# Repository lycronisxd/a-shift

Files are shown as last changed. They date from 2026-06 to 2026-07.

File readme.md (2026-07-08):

# a-shift
## a high-quality sim racing shifter targeted at being as cheap as possible to manufacture.

\
shifter


### pcb and schematic




### bill of materials

 Item No. | Part No. | Part Name | Qty. | Supplier | Unit Cost | Total Cost |
|---|---|---|---|---|---|---|
| 1 | 3D-001 | 3d printed y-axis chamber | 1 | 3d printing service / at home printing | N/A | N/A |
| 2 | 3D-002 | 3d printed x-axis bearing peg | 2 | 3d printing service / at home printing | N/A | N/A |
| 3 | 3D-003 | 3d printed y-axis bearing peg | 1 | 3d printing service / at home printing | N/A | N/A |
| 4 | 3D-004 | 3d printed main chassis | 1 | 3d printing service / at home printing | N/A | N/A |
| 5 | 3D-005 | 3d printed shift gate | 1 | 3d printing service / at home printing | N/A | N/A |
| 6 | 3D-006 | 3d printed y-axis bearing holder | 1 | 3d printing service / at home printing | N/A | N/A |
| 7 | 3D-007 | 3d printed shift knob | 1 | 3d printing service / at home printing | N/A | N/A |
| 8 | 3D-008 | 3d printed clamp head | 1 | 3d printing service / at home printing | N/A | N/A |
| 9 | 3D-009 | 3d printed clamp body | 1 | 3d printing service / at home printing | N/A | N/A |
| 10 | BR-001 | 608 series bearing | 4 | aliexpress | £0.44 | £4.35 (10pcs) |
| 11 | BR-002 | 625 series bearing | 2 | aliexpress | £0.37 | £3.68 (10pcs) |
| 12 | MNT-001 | m3x5mm bolt | 4 | accu | £0.27 | £1.08 |
| 13 | MNT-002 | m4 nut | 8 | accu | £0.18 | £1.44 |
| 14 | MNT-003 | m6 washers | 8 | accu | £0.19 | £1.52 |
| 15 | MNT-004 | m4x10mm bolt | 15 | accu | £0.15 | £2.25 |
| 16 | MNT-005 | m5 nut | 2 | accu | £0.43 | £0.86 |
| 17 | MNT-006 | m5x10mm bolt | 2 | accu | £0.49 | £0.98 |
| 18 | MNT-007 | m10 washer | 1 | accu | £0.82 | £0.82 |
| 19 | MNT-008 | m10 nut | 1 | accu | £1.01 | £1.01 |
| 20 | SPR-001 | 25mm long, 5mm diameter springs | 2 | aliexpress | £0.29 | £2.89 (10pcs) |
| 21 | SPR-002 | 45mm long, 5mm diameter springs | 2 | aliexpress | £0.37 | £3.73 (10pcs) |
| 22 | SPR-003 | 20mm long, 11mm diameter spring | 1 | aliexpress | £0.26 | £2.59 (10pcs) |
| 23 | MSC-001 | 200mm m10 threaded rod | 1 | aliexpress | £4.31 | £4.31 |
| 24 | MSC-002 | kw13-2 limit switches | 8 | aliexpress | £0.16 | £1.63 |
| 25 | PCB-001 | a-shift pcb (if assembled, ignore the following parts) | 1 | jlcpcb with gerber files | £4 | £4 |
| 26 | PCB-002 | CL21B105KBFNNNG 1uF capacitor | 1 | digikey | £0.09 | £0.09 |
| 27 | PCB-003 | CL21C220JBANNNC 22pF capacitor | 2 | digikey | £0.08 | £0.16 |
| 28 | PCB-004 | CL21B104KBCNNNC 0.1uF capacitor | 4 | digikey | £0.08 | £0.32 |
| 29 | PCB-005 | 1050170001 micro usb connector | 1 | digikey | £0.70 | £0.70 |
| 30 | PCB-006 | RC0805FR-0710KL 10k ohm resistor | 1 | digikey | £0.08 | £0.08 |
| 31 | PCB-007 | RC0805FR-0722RL 22 ohm resistor | 2 | digikey | £0.08 | £0.16 |
| 32 | PCB-008 | 1825910-6 tactile switch | 1 | digikey | £0.10 | £0.10 |
| 33 | PCB-009 | ATMEGA32U4-AU microcontroller | 1 | digikey | £4.01 | £4.01 |
| 34 | PCB-010 | ABM3-16.000MHZ-D2Y-T 16mhz crystal oscillator | 1 | digikey | £0.42 | £0.42 |\

total price (excl. 3d printing services, shipping and tax), <b>£43.18 (~60 USD)</b>

### relevant links
link to **public onshape project**:
<a href="https://cad.onshape.com/documents/ae479125a780254f271543a6/w/35b4ca05e55e778462ce5fb0/e/28c8145b059bf4585cd308b0"> click this </a>

link to **3d printed parts**:
<a href="https://www.thingiverse.com/thing:7376293">click here!</a>

### features
<ul>
<li>custom designed pcb based on the atmega32u4 for ease of future designing :)</li>
<li>7+R normally</li>
<li>5+R capability</li>
<li>sequential shifter capability</li>
<li>built in clamping system for tables or sim rigs</li>
</ul>

### how it works
<ul>
<li>uses a combination of software and hardware to be used as a shifter in racing or driving games</li>
<li>the used limit switches are mapped as controller buttons inside of game settings</li>
<li>can use the shifter sequentially if printing the sequential shift gate and using rubber bands!</li>
</ul>



### instructions
<a href="https://github.com/lycronisxd/a-shift/blob/main/instructions.md">click here!</a>

### credits + ai declaration
<a href="https://www.youtube.com/@amstudioprojects">amstudio</a> for <a href="https://www.youtube.com/watch?v=YMD8e26s7VE&t=88s">this video</a>\
about <a href="https://www.thingiverse.com/Noctiluxx/designs">noctiluxx's <a href="https://www.thingiverse.com/thing:1274947">h-pattern shifter design</a> for the forwards and backwards action of the shifter being locked <3 

i used google gemini to understand why the length of the shift lever mattered\
i used chatgpt to confirm the selection of the electronic components that i plan to use for the pcb (capacitors, resistors etc.)

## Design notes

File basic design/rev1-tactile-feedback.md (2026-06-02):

---

excalidraw-plugin: parsed
tags: [excalidraw]

---
==⚠  Switch to EXCALIDRAW VIEW in the MORE OPTIONS menu of this document. ⚠== You can decompress Drawing data with the command palette: 'Decompress current Excalidraw file'. For more info check in plugin settings under 'Saving'

# Excalidraw Data

## Text Elements
## Embedded Files
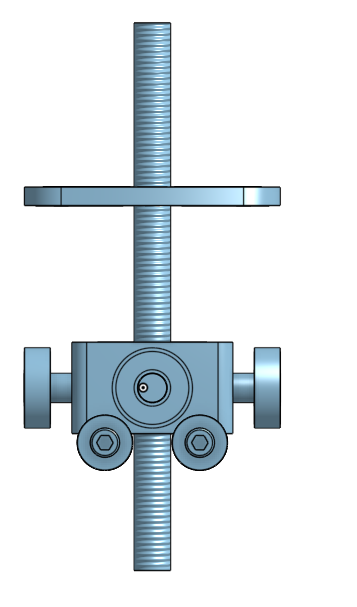
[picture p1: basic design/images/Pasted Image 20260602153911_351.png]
234c616a46d7c50920a0060077a56fa564ae83e9: 

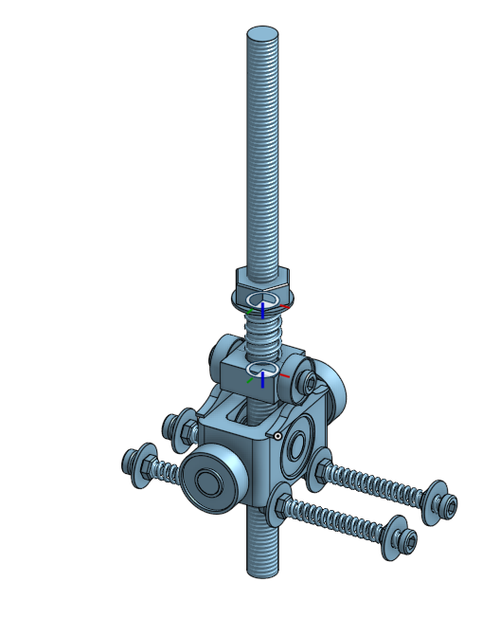
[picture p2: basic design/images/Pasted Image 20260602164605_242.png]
6d9b194bfda16ef9e24804b23e8041610898d77b: 

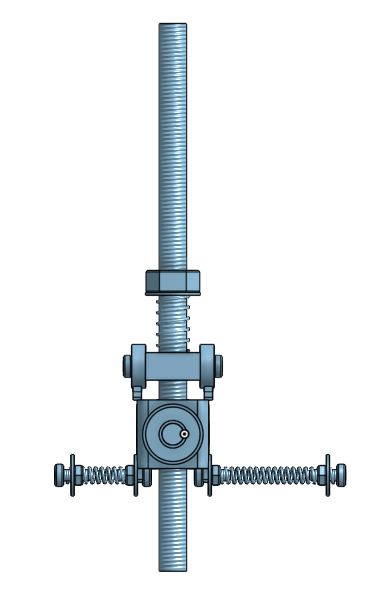
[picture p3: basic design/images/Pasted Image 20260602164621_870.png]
5b474f4c6cc8ce74e5476178851a1a231249c66e: 

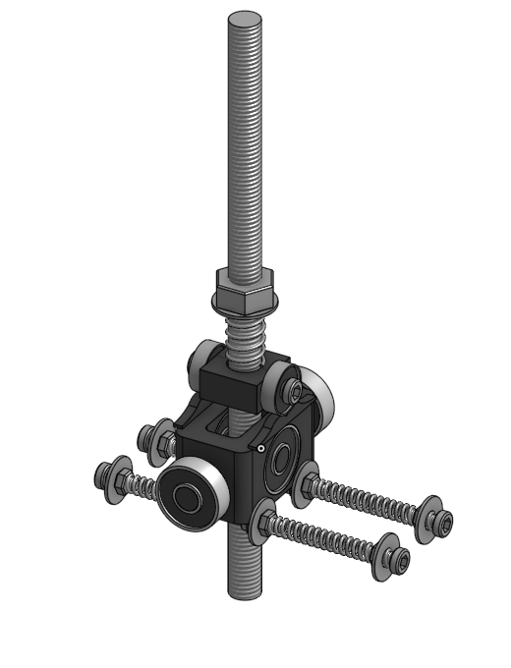
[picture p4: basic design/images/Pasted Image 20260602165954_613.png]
e46b88f7a6ff542bc56e074cb9cd92b4bdc86a87: 

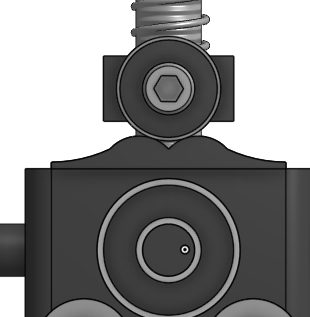
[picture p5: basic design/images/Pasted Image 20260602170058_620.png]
d8bf0ac76847611c596c5c8c6d7cbc8b6c326d83: 

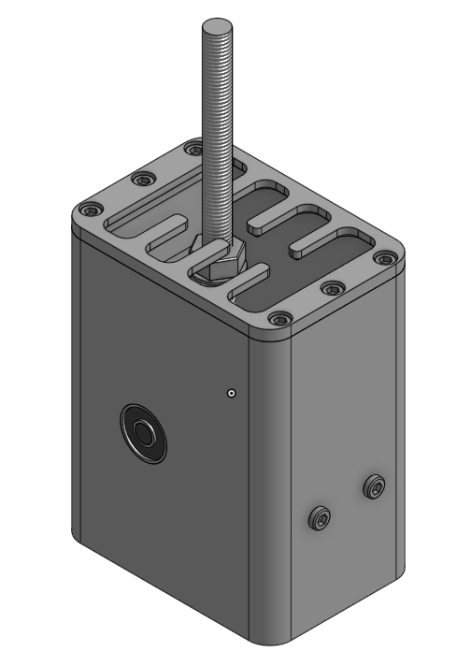
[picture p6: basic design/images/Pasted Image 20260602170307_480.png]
ec3541a6d95118efb10d60b192f7a991a92ff538: 

%%
## Drawing
```compressed-json
N4KAkARALgngDgUwgLgAQQQDwMYEMA2AlgCYBOuA7hADTgQBuCpAzoQPYB2KqATLZMzYBXUtiRoIACyhQ4zZAHoFAc0JRJQgEYA6bGwC2CgF7N6hbEcK4OCtptbErHALRY8RMpWdx8Q1TdIEfARcZgRmBShcZR5tHgBmbQAOGjoghH0EDihmbgBtcDBQMBKIEm4IAGFlWUqAMwA2JH5S2EQKwn1o5sLITG5neJ4ATm14+IaAVnGAFgBGJIaZniT4

lsgYAZ4Adknt7Unp7cWZ7ZnJ4eH1iAoSdW45gAZJme1hl+3Lp+25mfi566SBCEZTSB6fRI/RZLR4rObwta9CDWZTBbiPa7MKCkNgAawQlTY+DYpAq2OszDguEC2VSJUgmlw2FxyhxQg4xEJxNJEnJHEp1KyUDppTqhHw+AAyrA0RJBB4RQJsXiEAB1O6Sbh8JFYnH46UwWXoeXla5s0EccK5NAApFsKnYNSbG2PDFI1nCOAASWI1tQeQAutc6uRM

j7uBwhBLroQOVgKrhHoqIGyOZbmH7I9GdQgEMRuElHsMkpMktsGtr6QwmKxOA94klrowWOwOAA5ThiAvDHilmYzR4NGPMAAi6Sgee4dQIYWummEHIAosFMtk/YHrkI4MRcBP8zbjo95nMeH9C7aq0QOLiI1H8NdiczJ2hp/hZzqolAhH6IIgObHlGTMVgnDCQEhmbAGjmBpcBmBpiG2bBJiLHhHkTQdXW2bZcEmBpp1wmZcAQVYEGGZNmHccR/V6

MAL3pOZeiDJFsBxOBb2zKtJFCAAVLAoAAGVjG8XxnBBCgAXxaYpSnKCR6AALQAVSgZx9E0OpNGcYh4keSoACsACUDOUOBBmTNoqIgK8eirfo0GceFJm0R54jgpJzlwz55iHJFnVQByzicw5XSPBttgmM5rluYh7htbQvMOctoMuMtYUBYFQWFG0dm0Y8vlhEYSwba4USNN0q11FUuRJCoAGI5gQBqGuTRlmQ9dlOSJGreXIfkqRpYVg3FKUZUsk1

80xZV8XVGLNTQStSkq/VRoqcbk3NSR0z9OjIHtJknQeV1rna71fXyJiqxDXAw33VAs3vJFY2IeMJFwOZ1oXYgtu4aTWngKieF6SSc2fVBoKSHgFnORYmxrVsHhPWGW04DsOC7NApimHY4OHMdgj3KdRLnT7lwyIV1wu0otx3AmD0LY85j2CGdqsoT2Iey82CfW7X3fKs4DYWMcnyGiCnpEpyvFx4aMpkoxfFhz4uGDykoaFLtjSmiwAcnK8uGJ4e

EK6YkhlxjJupKAACEnoA9nriyYhrf/DhALQe7zdIKAAEFSBxCggVwW73aRB2fb9gOg7va4BfwGBlDrES3wQQEeL4wTr0JpOJKkx7bogZR5MkSQkn4owkgAKRmbiOCSNUsIADVVbBVXM/6Kms5M7NQeJS3iw3Th+U5hmeGHfIGOZAoOZDXTPcKGkipFoti1BHmSYYfmOCHUKPIse/SkEwWy/Y9YNo3iqRUqqMlpU9QJLqeXQerGuflqmRZVNOu5Ml

eoFAagOGg0RoIBrUmrfGay8Fo3xVIAsaRJTRIg2t9G01w9qOlgIda++c2SnQpsGUMCBQJ3Sjo9OMXdkQ8A+h1JBqBfqQAslqIGmJcy3UhqeFyqFDZI1rFwNAw8uGtlRujVATM5jr0eL8XG45Qa82TkiecHVSarmFmgDcSJqa7lBhPem8JoLgUgazDObtiGc25pnPmpQBZC3XKLLW18JYy3WGAeW9JnCrySOvLRW8Z670mI47WJ5j7wnyobYsxtTb

0llsAqInsnaOBdnbEOHJYm2yMRxRa0Tva+zYP7EIkc0mQFDlknJgcEn8yJHHBOqAZEp2YLxTAAk2aJzCNnQov0yh52JJofiuB5IAGlLYUHLgAcQAGpwFIBQBoGZcBJF6a3doEgQzMPIFQa4XcHKMzeP8YYDRxhY2GD3GY1w/IOTLHMbQ0EzgVmOJcY4UUNTcCGE5DWhZSxHj2IzfRQID5ZVQFBZyvwoaPAhlBRYLNL7olAVVe+dUmovznG/dqHJq

oP2gD/fqQp/4ShgatOBE0PxgIeWgVeviCXQJWnKPFlCLRWgeCgh0B0XSYJOj6XBSIro3VKTJUhCYZiULTLS1JHNFrMIeH8Z4LxdlHKRM2bh3BTj6NlQIzsVEFgNBBRMPhj1RxSJ5kTORJMVzk3OpubcGjbpaKPDo8sDYfKXkaUQ/JVkub4j1UnaOgs1wi3Fs4iWfjpbi1lk42x/q17bF7A2eEZZDhngcTY8WYA7G0SVucIYFYXK7F3ibQNjjfWJr

DTsJIhZ3KXHiJ8UlCbzkJTTahMtyEDnZoibm2xBbN7ApmKW8tfjYhqy0UsIYvZBx1rjT6rWVblbIXLAkXY8J+zSoTYkUsw8sYDjOJcBoI76R5vHecR4U662zv7H414MxFjbOeDwCswUZibrllrHt+tjj9sNshOC2w/FOQbD3deYKTynsvZMW9waE0Pr7X8F9R555+IaHEYt5YGhqwrPMDtQG82LvcYOSYbC13uSmNB2DwL4OIdPL8YYqGtboeXVh

1dHbcMVvFvsLRcwdKntIzsg55GF0HAwyuvdtG4L0fpEkZyuwBw9ncZcHsfxOPixPWe/sR4pM9kvX44Te6XgoQk5cU88QZP0jk1KgcHbTzKbteLYT69L27KeAsM4xxth6ZKJ+1YewVhLGngc+d5m3jhoQ/8cRZZThlkc2AZzPdw0nA865PxoxFiXHmPrDNx4QswZWMCyYlydKun+IiBNsW1bK1EU8MtyWc3xvFql4tGX55ZZcsxvxTx4rz1Ea5/uO

zpghcY8cZjR4khsbVrl8WjXyw/HeOGtrUxdNldHQmrrfWWN9Y7exwb9FzkIf7IFHSZx3HlhC2p0TmnJPD2gg12IuEJ4rFcpe08WG9s+cvZGi9k7GxjrO1BCLV2kO3em1urWFnfOPaw89hriRzjDz3YzeECR3KAx+3evLyQCvJWY5m4rDXXg9wrCWd4OyEjQUA3D4DQ3V4jZa+Nkzp6VslE2RG6Y69B7FheSF4bzWxuGwp6sBrMHGbAoWHsSThYpt

NvK6t7Q63Tipr40WisDX9i9b3QkfWZZwsE+FzNobb2J7THGFJvrJZZdvFTRl7eZb/i9mZ6DpdzMXhLfeA14TMOGjPHEf3RYDnCfbox7hS9RYKySaGFcMdDvlhO+QieU8bvmde4rE73H/uRgNdGOFYsqwIZ8c+GRj3Y6nK0/iPT0jiwsOJ/innotDZUJ2cuMznP0w6dYQL1jbtq9dk/DLbs67Pce7M+58hPX/OUouSb2LstKP28Vk76rkoQbt0995

yWDPxZB/3vOdMfs0E1/h5LI2qfzbK1y9PUeZP1H15efpJDA4rlvIb8Nlv5n+wJ01qS/rSBJRDa5X+PPWEWGUo3qz3vw30w12T+iM96iQQw7iHag4pGWEp4zOwePuYerutG3arwhsFYhaBWlmZwcByQIezu4ep6yB96TkJ4rkfW6qtmcI2+YA0+Y6SepeqeFeQWL+YAl6zkFeTukBZakMv+auv2IGzeI+MeIwp44a3aMGSu4i4q/c5Y7kIW5+q+ee

vwc6xY7W4hbwCwUhOkMh6qvBO+Iur+sQfwlyX+IwxYKwL2IG+wfW3+/w3wpwmE8hYBKwysy60BCG7696wmPwvYcEpmL6k+NBu+4sp4cQ12GBkmGspw3a3hJ4kq/hvYgRtBIGJB4EuE6q1G0agmr+owseEMewdhkMyu8hqRrk6RJYEeuw2RYAOkBwe6e67wywty8w7ufB8OIRMGsIe6hyBy22zGp+JQtRk6DRLwZhZwE88hnRFePRJW82AxNR5yRm

PcLmpG88ehQRBhrBEhmhvw2hoh5wnhC6ixoUpYPcqx2Bf+HRGh540h+xewfiQwYw4iUEkMuy3BKwkx1xWhBUEu9xFGiQoiRaw8HiZyTuG6lxZ+1hnyBy8IfG6qEwDxAJKewJUIPwYJ8hUJthsJVyqwZm9IrkzkOyyUh4Zau88hsRvYo2oip4FYJ2FGrwvuxJguGsHGEJr+FJHy+sUmtJeJgxrwpayw36/cSwrR+h6uZ+uRRYhY3R/Y68UmDx/Jnm

CQFwwppw8hkpi+MpHanwp4DxTkGGGsbCcJsIIWQx9R5aTR68OkVONR+pw8hpA4xpsObRRO+JJK5pjRYx1pDxMG9m7wtJ12jMCGppxxfwpxGWHaCGnOFG+wGRypsIUOwKmeLpaGsQOk0EI+Fw66ro1RZaYuFRPcCZJ4SZppaZzxmZkmTuzwDxwmpYEeZeZh/appSJ0uFwuwohWENZ3G9ZqwjZ0mbJNRDJRJG2qwdmjMDxowQ8I2SwpGewhwppQ5UE

I5JWPw1RA4YwWECZqaI+QuYp/B4sBJApypymcE0RWs65Zahpvw2ureppdp9RRpgU+u55q8l5W5N5zGd5a8D5jpT5a55y2MWWl6tmg4zpe57R+JvpZYMJkMWZuwvJYA8wcQZwQFoKGsFYppUFEIJ4jMtyuEx6sQE8jMGm4UVy+OppsZFRTwsIspas8xywFyq5JFJWUEUwFF+ZWG1Fp4kZysx6iQg4DZRa/cHySRwR+JtZEMp6DZ66QwfFzk6qvZQl

N2q5ppk5nw05yG/p9FiQOyUE8IasfGr6qluU6l88M5HaBEx6rwZ6EwwUQBpYIWF5m5p5tuyELB/YiOeydl6aDlA5SF2MOwWGK688o8CaHlNlUwblPl1ByRsmAFZwgVAGNJT6x6zyYJ/YdhQSw86xsV+mhFTFq6LF8Ix6MGUwNyfWISjRolmxDFRFMa3RZFO0JQpwU8GW5YMJHaA8jl/FCl4BW85wHax6+whwbVA2pGXVflPVgl/VLwgeYVwm5wOm

fG4wGs/wOVYlzVOlCGOiBlZwp6hxsmC11GW2fwpJa13Vbw21+l9p/YZYx6owrkYi7wGWcWSwjl1lbxA4yEWZZVa5D12pRYhwaqOy61NVaVUBHVFlz191YwANz1wNb1fl4NUEkNOOhwH6q8NJOyeyJWL1jlpVTMxY4elwWGlh4syEcQfhbxLe5wCwjlw1QN7Va1ysCGGNlNiGONgUdNflDNo1HVLNCFGWFy/Yp4kM42/Y1V4pzVR1N2BRkmA4CJWs

QtyhotF23Fkt+5+mMtKsee8WLkgtsQVqUN7kxZzwjl/1Oy7kI1ylR6StsQDaWEQ8wFvRIWFNWN1NuNf6H69tYUleztZartmNVNnNtNupStiQuJzwEw4iUaPYrt5yKtywatEtH6Ed0d0wTuOi7iYFGxUtoWht8wWGUpy1IKH6rw4U4wfGJ48WcErtPtgWcpWZhwc15N5d4wJ11dystdA50wyQ0dbmR4nV+sH6TkuyI86BpGZaiwrtbdld4xZhTRI9

w+49hsk9T6rto9OkpYE9HaEUS9Y929q9u969Pdm9K9PBByUGStMGWGxwjp7dA2u5udmtTmN9haPOEUqaZN9IuEBwha99eyByT9uVTmx8g6Dai1G2gtb9d92WgD4wrtYD9aDYkDpwgtSDUaJtiwhertwmA63Bk2e1EiStGDCwWD6qbFPdowkM7Wvw6BfwOMJDuUvYmD8w2DlDKZWsTuFyyU2hGsCV7kH6pDRabDFDGtEFJQ3D11fDfGKw8xvc+Dvm

Rwa+OyKW5yUhuF6W8WYJH6eDhsBDyjCW4JnDCa/y+suxNyspeeNpCj+jSjJWRjajGhFjEBu9ByH61DoiUwdD/cPcOdIDYAFYyQhGJhZh4wTVoWnjtDcEvj32JjFWkIzwJNGWpGl6LdP9UT3jMTOmcT4FrpkjrwTuA64GaxttCaFwcQXjEZ9DfjKWQUOZdWfjfwdyStmT1TsT/jG1gT9TzuOWx1LTpjq811F64xoig4KWMGeeWEfWysJW/w0GQzyU

IzeU4zA588cQ7wGE7Zotp6CzPDBlt9KzxjeTea6zIwyETu2zywuzXD6jgK7kwKwFYKKWwm1JOuuEVdoVFWdzbDA4IKaqDEazowSZuEo5WZ4W0GPzQK/zzzQLbw2DpwUMxmvFtzAKvzjzoKUEnWbiJtvY2m2mslqLGjDzMLWLA5Pw8Ui28upG+OkLaL0LTzZL8T9I4aYuT6eylyDDET/yxLfzjLgLzLJQ4UBwuwz+yw1GOwNpPL9zfLmLArJzWsZw

Jl2ypBJWkM3LULJL/LnWn6URGsR4/c45RLMrGLALnWqW8822JYfGhGdLvLprsLgrYAWEFySw9OCGWZvY39kjmrsrZr5Lam6BBEe1XJCF0r6LpL8rz9EjzrFmFwteKwZhJ43rgTvrDrTLCrs2sWoLvwRYpGg4Ybabkbe2JOGmTRg4CVZadrJrxbA5fWYuGWQwdVJGuw1bEb2rdbZ2p6VZWGJWCIbbDLcre2oO0MEIxTzwGr9LWrQ7dbGOxhvOEuym

LB4bg7/rTrJYlNLkcWzd+shbU7frjrmb5m3ObeZVSwkBPYA707a7R7Qmcuj1Et4alwS+gz+zw8hzQSqz679+A6CQkap6ltezwzH7Yzxz0b+TYARayQIwi1Xj4xeeQHSzIHy6e2Sel64U1F1Ge6B19IUjSH2Mn7YHAT7ifcNWmH2GOHTmbTPjOTnTmxw8YuRpRNJWUhHjlT0TNTuT4HeaDHSGrozHZwrHStej06AGDjXjIW+sf9ybiw7OeeZ55TIn

Bj4nqjA5PYuUfOE8zTHapBujYwdjYnRDqnTr6nbDbV2nz+Njwj5DODanYBjMnwX2z76NTD4rrDaqtnJn9n/OTn771Rv9t9DzLk8DwDXTyslTW231t1paH6MDQXD9QDknqBPWmaNuEmNjZ9h9F9U9RHYXJBxWxsfu7i8zStmXsn2XJ9Jn+XLkhXhUMJZdJec98wC93dJnnRe6Y+g8RalHoWs9HdLXuX9H7XNq6Hvw3Xqdfdoe0dWdcdanEhvWS5bu

Rm3tWyZYftKNAdan1hW5sI7wiuAz5N9djtOpG3op3HWs68wTPBu3vbP6K3RtOOuLOZknwmBWCWxWyeETytItSd4t5wknowFwCGcp4eKDKb331zYt/c/3angPulIP+j7k4PQdHNEwntMVXT1FuUByPY882Mx26TzVFtLJQNr1oNedNmYwz+Eq367ifx81uUx1y1Z1vwzO4iVPxZhwtPY2Q1rVE8Y1nVWEbPsQFhhBl+Uldu55vN/P/NE1TrBssGSP

DDt1dPJVDb5VxNVVbPAJ8+1m3+ZeNpcE6v7iFVZhLw4jEHTwDJEMXwltRp9FBNGvlV5vbP1vSbdvjp9FyNGVOioi2Vrv8LsI/DI28n7l3vxhOiz75PL9tER4gfOw2HNWys7lH1XlUVqEvl8vzwyQWEs1pYvbgWVlnltl6fI8bPvp22l2vRkaKfxfkVsI0V5f8Ulfqw1fFVclulO1N1RlA53wbLkMCuBUdaHfV1SzgUR4bPtZj9md22l755U1ilM1

KlvfRYuUCGi3eLRaFwclAli/wly/Wfk56/Y3m/2OBFjFxFhVZFHDt71OjWaPxXhm0FPXtVBVDVcE5Fvf8IcQel4aItjOCec8vlUv7v9WKFvbdN/2AoXZ/+ZYQAWFXirioG+IFDCl/0Ip9gXcdZPPNWXPIIDUKyAujhTxPAXJ0BcRCGFgLXKvlNyPBD8qF02IIhnIhwdVK6A8JfoU2TlK8tuVvJf8dK3+UsNGmnStsKMaldeGZU0pzlwBY6X4MkDc

pt5RyO5LsnWSkq9l10/ZeXpsjszVZjMCQbxgoMkpFplBINWgYQOeSnBNBymWyhEzzJxlCy6rVCO4mZzQQxcG2SXFa04QxkOK8ZWwSWS/6lVnB0wKXFvB9KUty0AZWkukQcHDVlgNFRyIzgQoTBgh/pVhGEODJf8Fq1jXbtxTiwsF4hfpb3CeGSGDdCBaQg5BkNupqxsh95B0phDggmkv+D1Wyn1nCiFRdkepb8lUKdIOD6hUwRoQHjPQKk3gSpIU

jSTVK99UIcQcYH1meD/oGw4ifoUeSGGnkzuATYsuMMBzTDzw/QxkmrBJIskjBMfHChcn8zFdPIpuQnoOUJKsUf0GaMkqMITpHCDkJw5PIiQuTIkiwqJaCF+1v60Q38sIXEuQV7aWtnhgJDDCCTRKfDzulaN/D2AIjbDTcUEXMi2RBHvD0SowiOjfl2CbxGcXzfEmWWgg4U3i42DHnQNCLhpxE5vE/LAPmKPF0yLxDMu8SJEU9ewYuLTrMCSaF44h

oZZYmcUjIXF5ebBCMj4R4LdsHi7pfhp6WaITFRhgSP3qfFCSEsQMGpfIhhxwrFFRheDFCICXLykkU2IwMXFKUpKFFbMewmNsmyeI9hNRZAl5DEXihxE/CaBAIszl1GoQ3WJwGrEsGtE+F4i9oxIhbiGYZpHahwZUuFA9G2jyh4Recr33+DORxEzwGPKbjaohjfCYYoNhIMrRRjXQTwb3C3jOI9ccoNhEYHYXTyOFIx5yE3isGezFh1ULBPMdCULF

2Zix8vR4uWlwgNhAssnaojWKxL2F9WSwzHk2Oeq7Juu3bXsOoUkK7EfishaPiaPGBi5xMIeR7ocB1HbEbiexNBnIUjGvALgLuHnLdUGr3opiHXRTBmh4IW4nI+1e+tXXcjjB1CXRcsEeO4Ks9IxkzXDCMGTbHkzhTI0gqxgoKwC9cFufYHCHtKX1wooxbtKUW/F64Is3NRscC3LACYue4UNhmBIuTgRyCkEqghblGBWk6KEwE3qcWQlfi0JlBP8b

33XKpQrSE8bbLfRQJhF0CT6SItjCjxVoqxGWUJMWEYYgZUC4ReibckYmkSe0kVLbF3Vb7dpnCEBNwtqT/5R5F0WOX3Lt1WB7xQC+ncSVAUkmwFSJJ6KsigwWDKlRJyk1wqpPpzqT5e5wMYAUTVo1Y503aIwh/kNLf52JUeVLOSKKa9s281k9/KE3snriTJjGF6ttmaaV0dRK+S/OvmPA35M+Xwsbs5B0760rcp6DscFLXznsoc5YhkfsNPSG5Bxy

VQghPCHwt5R8NaCfNXhJxiZHS7kf9O43vSCFW8I3cfLXmrxrZI0ClW5K5B66iIS8KecvOniry98sMF+G3JuTIEDgWC7U5PGXjTyV5kykU3uuBiUaZYyixeMaYwW6lTSIRQ2F4GMFqyAFe2haRaQwS6mTTq8GOLaU8gSC7Sg8uBBAi7gjzzxq8OeHYHI2Yym5IY9uS6aHmundtexdA3+n+mNzKwTetqV6Y7nwKu5bpvU7nDdmroAdU8CFCeAATOIm

4MO5uXqXLjFqPo9glOEaffiNym1TccRavPfjGYaxcIFwEFFjPhnG5ssSM1MetIdwZlj6t1URPMThkP5KZGaM3DTPoi9xyCj1BxjM2Zn75Cw4aJQsrjnLV4k8zGERDthWoG55cwspXCBN2Dd5m8TwEsAVjIHekx0gshXCLMVmczqc/yXvJLMLA1ZdJWs6KULMVxGixZvfIJl9WQzwi8cKbOGXLKtmiylZtssAg30GHKjZZB+eWdbI9ny8lgLw7TIj

3MJFo/Zls3WSrm7xOQ3hqEK3pX3JmuyY5Ns4OU5BrqfASwpM9fFHJ1kKzY5tsmDO4i1zQhbqvufOQHPdn6zaI6zTEYFnUpDBgx5s1OYXPTmRT1U+ZGPFjjIEZ8q5bsvWd3kB4uZd0OyDDlW1bn+zB5Rc+XhrFyjFpFcF6HSM7O1nVyh5vfCllPQNg1T0yNpF2dPLTlBzIprLQKpGiwzs4J0A8o+bXIngAlfMRTLbC4Wvntzj5a0+iEq0HDFglCt9

XoS/MDm3ylW48+EI51IIJB/5Ncu/PqX7TjzYRGZCBRvLnm+lWKVRY4HjkHAILZ5J82MkuheC2pwoR4TBR3PfnU5jgU8cfNsgvnrwiFb85YZ8EZ4IyqZr4gWRbILkAK4Cr5SdMPFN5yM2pa8mecQuWH1tRC7GKVGdPwpTzo5r82+RDGFqZERaTQmhTIv4risHpxuHLCnMPnSK4COlUvBhDbI6R3RkithZAt77uQ+6LybtmQNdCrzWF68rBSQtoiLB

h86+CPBfNgFKK4Cw1Fwqwl6JwhYZ/Cm+XAQWpAEYx7ObbJ4rMUhL00YSw2BEvNmszcZ1MuAg9T/Y3JRa/wUsAbkSWIyOZzOBjobEwxYRm5OkM4SzJxm5L8ZvfApc6L2BNCCFZS+Au9IIKR5qlCdCeJfReCkEXIzMppSDJulfSKe6nMkbBUepPtWaF04GYgQGX5LDanyRmGMpGATLK09BTqRNKHirTlh6nMVoVjrKvi9paypghnnyUR03h4yvHjDg

OXjSjlPU+XgcmCZGTdKEWZYHlJ3K1TlSXeapeXXqJtVtmjtV5TVLHwfLb57wPUadRHjcEoQAKgqR3nqnVLR6oULeqOR2ALBu0iUq/GFNSn5Kb6zxXeEuzwzL4L8SU6/FiuqX7BS8m8HggkAwWErV8GKlKbfmqXCYllFbAqE+2Hq0qQpyUzfBFMcWAkNmYJQ0g9K+DuTjCn+XsGYW8mRTLgLw2YKcWJqKSQMNkzyZKqnEQdt4hJUCnBCmZuZcxYkg

yUuSMlqq80GqxnMPEvxbwdR+qyAoapgLGqqppYksDpN7B48UKNE70TxKwL2qBCsQNBR/0wxoFyw7q7iXFl4m8ivhtaNllaUZwENgUwauiaGq9XyEXIUasaaRR9w6jwJRE38dBIjVx86lAWKsQEQImoTwYxE3NY4oz4mUEsmaZYEspvEcF7x4aR8U62dEblfgNqAJC4RtJsFbxnBc1c2u9UhE90P/LIjhRvyTyQMy474joSlWVrgUrrR+T2CwK5jp

1442dUOrPyr8h0ZucKFvFXVfF11ohXQsmuBZvEAk5eHYN2kxIFjsSDhPdKesupJNGYb6S9OcGvXJBaxd6nsfIUazz5UoPcC+XUo/X5iYS3YhsRGu/5VEaWLeFhiBq/XgaH1A5dVvFCBo6dYNGWRMV6PDG1zWEDbUWupXZyposNdonDb+sXSRkK2yfNzNWI5KkaUxv6k9G5DVlB8dgkvEDHRuTEOjkNmyLlSSvDS5jONCRCMa2t43ErMVAm7tIqIN

FQ4jRv61LMhnAyiJfMuY6TeZJVHhR5NlNZQk20sxX0F0ookYpaXGKDKY+YtQ4bAI4RbwimIouomKNGISjTNMbIos5Gjo2KIotOWzcMQtJjEWiv6tTG5uBQeba8DxTkeGXOKbrX8CwLZM3JBoXybmRxXKCcRWI8jItrBdqasAlRW1uC8wULUlrDIpbx5aWmhn3Sy2po/+lg3EbSIJE355CYwgTcivQLKlcyVW/EStVq3Ibz8V6XFTDh2BGKF0rW14

u1o+Kda1sg6D4b1rglAjXhoIj4YULM1v4L5MHbOr5h2TTagSbw2zHNrq2g4ycpJcPFjnW1IittKI1taEQ/wVF604aVzJsKJLbDmSNws7TnkBQ5ZnVr6W7ZcJ2GPaI1bBHRPMBdx49mmH2pktcNZJnbucs6GzOhx0w9dDygwlUsMKc3qqcoNi5qX42hxzD4dJ5EUnVrlzAo0dF88+AukqE0VqhTuAgQtvvxJNLWzTPHBULaGk6OhnWh3HVgExlUHp

9Og0ozquS1CztLOtapjFczjYghuQ0IbBRSFnak8M8CNAlQAxUisKiQ/IeLvm3Oahi9OK1BDGu3FgRd0FPIYGXCHIaoxQ9G3s/gjQ66QhSQ5XU4UWKuETd4eaYA8Uoq9s3KiZewYbrTKmYOllmGJo7o8E2DXdmyrpn+1gyNEMI/VGlQuid2eCA9ThV4B5yZmXI/2KbKwQWRd3Fk3dranuM5AebmEJVN+bIVHv93p7A9mxZUvCxRyrV3ixDSPX7rT1

2CS9edbQTnxzn59XM4+X3dYLr3eDM9+wXPqsDghLAAicQwvV3oz0RqGwbLOwq1LUUd7U9RZevU4UB6rVlMpvYwrPud3z7u9Ea9cm+maxJlhZ/Wg8iPs31j7K1SFCYMbtz1bZ190e4vfIQYrhEVg6FcWjfqL0L7kNfwYgZsxnQXyLsr+0fQ3rM0eVYx7LUTvpX/0n7ADzmjyu8DzxZNXMQOCA14NP0BMbs0gv9HnlGLKUkDMej/b6XilxLrkYdGvZ

3sgP37Yy0MMkYKPbo4G79H+2suKmZKWYAMtB9/a2o7S5QFaFwMhuzksHH7kDUB9VRTRWot510g61g1vsrVC1wIu7V5IUpbkLoFdeugoSUUIq6bzs3BcRLDqUNi6gyKuoQ/xQLF7VwsotOIToct16GSi1lRXEMBGYhJzdiu/XRLojWHA+4OFfHeHjNnE6Gdj5GoRTuc2/1QUAHYHs2v00HkSdvh8nSUWGoOddCaCl6fSQGFXYFhOO5Db3HmAsYIse

PQhYkfmEI7FhJRBaj1gVRu5UIVIxciDtJJg6XDD1YrD7j27KbcyFR+7aDuNFCHaj7CWPJxXXgIiXhG22badojXcNG1XBUbNkMREokTt4I1A/8iTnIrXM14ijINrpGEjJihtLoleiuxoEHiyxmrSNtbVBNXQzoiNHWpUwUYwthWtYmsbXieZ+iD00RHlqWLhbUtkxSELpUTnG5IYitAzXZqM2+bJRBxwpg2lUJtkK8Xmj0g5pPwAmhjQJhsCCcsx7

opNeo8wupqKKabkNUwA4OYywiyE3BCo5E0qMNGqiDjQUbE1hCLUkauNPojEzBikrnAz2o2MpiESE3eiRNQx8lfPk7xUU1ulJ4TbhvWYNgCixsTijyfvQ3qwNRYpDQceZWZbAUvRBYBE07G3rENSOk1V3MuwaN5TfWUcTsVuJrjitasC5OeBKEOd2cOplcROJPXIb552HRFpJVXoIVe1IxgdSeOtOrwT8madvKSJRYpEUJZBMtTmrSnOaKWsA3bmv

kKVnHfThEgM1BKDPqqQzpImDs1w4SOmuJCazAgJuK2ssmajzbUspvjVxLE1mZjEokHX6lhiZzMD8WmcLMZm+Jra4VmWdSh1kHjSk8AgaugJSTrTm4wcd0I8JQxHT1qiSUaoxJni9K/YeeJxQO5n5Bzhku1SObX6HoJzYtHUcqvFVeSszkzU4jIfGwtmlVHktc6qoxKbneyiymhmiqJX0qeVcZk1S60SLk6t6za6seitCkMreVqBshZ8iLR/bClLQ

zleJtfPXmxTwLMPJ6xRXrpoVbeQqXCvrNYSJcYUM3KIh7XVSYVdUz5a2sLC4FEWuwKZrZiuXLTDpyG+tuMRkr/pNCzM1ZdcpWnkke0eeQKkGQ3jfGhsFF/CxsvJKLoS+cBziuqjwsHTWLhFk9CtWbmWaiwPF9Zccv4vv5np9mQpY0ren9LPp5JT9P5hiGuZNYlaPpdMoUuEXUsibbKgaxay9K5Lml1pehcYx3nzRYFoGXgWMtgz0LamG/AflYQLB

95Glj6SZYjUkdGhX1LKRPGwHqWjLbl2yx5dixadYx5eXy9UXKW14kleS5DQx0Hi6FxzaJFhTkqpmxXW1UnPStjUSKwVbFqV9mVUoytnY82UQmAn72yUVK0rhViNfcoHCD7gU8+akhVeiuVLkZGVjHPrXXTJ8+ckV7GS1aqttWarOefjscDcpQqEllVgq4NcrWgrt4P6Ma6iuMX2LBFQenZISUJOyaFDQ2QJdorisSFnqEwIJGiV/P/4257CvawMK

55ZXjr+82fH3gXyC51S1hcTKk2ZiXMucxAufP3kXxtGTVxYJWPxzhGrlmZd1vnA9Zcjqlciyua7bBwU5DZQb8+AXBDYHJZZuMHkZjHjwWBlKEb31x6yjfZ6sZZTGInSSDc+v3Wkbv1ijATb1zplibklBrDXk7z55aMTOfG2mU+Cqz2JYtenutLiC14pmDOVKIBYM2JA+tvtHsBvAZt82mb9eFm8ClNJx8756/TOkNqlu55mbjOeW/jfjkskBqm2k

mWrf5sa2hbCtnW0WD1seIDbY6aPOWJxzj5P+TrLepdX6pFFYKETKQZjlttA88cN/RxYYsRzBRtCzWJk/RBtvY5vbH+WuVtiazv0XMXxra6HbMlY542uOSOwrde4/Uily59HEna9up2HbXw0pVPHlkCYN4kZobGHZTv23fbATfzIz1pqa6k6yyiu7nfDv52a7XTOwmZI6UvIUV2/a263ars+2o7RAkzOplLmjLmZldu28PZDIAltV8RDxAPpzue22

71dkewyT+BvFe8PBd29PYjsF2/bUg5WHmx9ut4p7g9me2nZRvH2xMpBS5P0UNsy3BbrNx25slTxFY4irCQQZWkZt14X7Wtt+76U7xvdQjgjbPNLf/sF5X7hdxwSBM1TKwwHpNnnOTYHyU2jisZNNPtUSjwKx0ON8G+g4PLRb7JgVQfUGQ+soOwbFNkMrWTMKkOk6Ei061ovOtv3JyD0odAJtIyRLHbYwoYLdReo4Ut73Dwu+flXo2pVCNU4R37bf

yftlg2cr41I9rsJANChZA1qCQd1LWBFtCzu0yJeQjx3kq5TRVIpYciPnkwKfRwcU+SKOzYSIcZFaBEDhATUOoToFGA0QAAFQIBmAcfcBsQQgWRJxFTj1J04wkKpKJBaQlA2kskdAKqAACKI4AAPpsAAAjvoEUgjhHgZgTAPJH0DOAQwAACUqANB5klkJZHmBWSdwtQg4I02KPAxckOJpQE5Hzjj2IXzVRNUKPclmgPA9g7BDpVrm2x8P94mUbgEE

zgyhNS0I4i+C7DKhQp8QKKWFM/GagIo2oH8OZz1ApAYpaQQ0bFBSmNBUoZnaoIlCvAOD7OcUlKBUGaGEA0oMwdKO0AynQRMpjo2CVlE48uj4JCEwcKsE9BejoAcI/KL6IKkdTCoBAoqNABvGKz1PIASqSpDpn4QowVU9YPaqVcwSEAdU+MaRPqirDyIlwRqL1CokiTqJaYYMQ8AzE+Bf4HwDqD56UEfCuozE/jixJ6mUTUQ86SaANE6zcRYEi07a

eLGj39TM4U0BxA+jV0Ki8vkNs4pW38HBzljiDUsU0txmOzUZM03NkV06wMwwdYxGYvSsq6+FhZXMkWQG/MXZcNbi0S2Nk44sqzpZMsIUSdVLFbScuS0z1TrIxXmy9Z+slUhNIa8LTGvkmd2dTGJhcKSZnioaHbJ665cOu6292BSlKX4xF4W0wbttPa9NcBN8slY8oc7l8KRWU0gBdNHWizRs8msg8VzODg84NZM3j+HNw2gcFi5z2N2HN0EhLfVo

gC5bhsJW/Fw1vUcu5kImK76y/ALCRDRGnyIODvZguNQ5gVevvRdvZ0vb4lRbkZ5liX1rlbtBO57dDir8M76GOYXneSZcycrgNTRnXRrurcsFWUiTWPQLzDMimEzJdijy53Y8fubTGIXPJnvL8F74zKsGryQOBb0DuNY++7bPvjMr7wh1zI/fG2rRStMYC5h/R6UI8AGbvGTaodoOP04H79E+ihz/oO7dA/BxTfwxpYyw6/XHJpTvysKrSIjK0i8G

w9wY8PSGUjIR4nR9aB+IFsNgRlw/A8qPKGTeQATo+ZiyRCFObJf26zaDblkU+AiNXETg4GrNpXjzGn48IOcCMOET2MxsXRkE0+2DTOJiOw6Z8lHUhSZrunjOjVMImVT/6+0yqC81w+H4PkO/QqCWC/2S9Jy/YmhJnDlaxKUoTnS0Y1Cf2CN3Z5LRqz9DJq5z/rFc+qECVCOUNe9ySzwg6t+5uyZKosIxZEc8WIrOF6jaoHVz0XlKLF7HQk48eFeM

hohKGBOF9JNqjs9K/ohZfxsEObrq5Hy8f7aJNZyIofgaxrZz2m2KXCIJKJ+mLmIVSMta9Fzi4Wvs/XbGkY68Fs762NNqZrmws65oPxYT4hsZzkNNIM+8ib9rlosVThbVxOb8FGdyLeQcjPcHKuShwoN/D6q7Yo50YNHZdvYOTCJDlIIw5Pij6QwUmUkwr3vca92e9ac/XHUQFS2PEy3dXtD3r76Fm0RKupJZkSwId6nH/c/dy31vZ+DkjQzxahII

fdcuD4jbQfqkCTmES/HKWdmYf0f+N34z5pakvttrRHvdSWhAlpazS9m4zZrP/z5XuCO2EMvlq5ERl3jASimUkpcKqmljTxDMquUrIR7SfDPiLOvFLJ8/8pWZHZEL/ohNLas3Xbijz4XQtl9YQPEtMKdEs3LBDaGRcubdJdLYEtTFrTyxfEuO3dfiD7KvFh1HIXhCUmDDlT/N9DxFM/0883SpfNXmFySR+MaoVUJGsQMz57leFNh+DF7yvGHDCV6i

0Xn3fQfr8jxiw7h/5ib+MVXt0jKr1g/NRBXQhbgqMOQiq5lP7jiKKYUEhWfvCgOcK9Dm5zKNqPVxVorgXWzLhIr2pKp/V+jjtftbfemrMRFbkh+U0hJR7IB5srBZrv2IhGGO2+/Sggf+3hLX+mfxWu4ylOVEGzlD9Z+LNTGbxbz/TKcEpf4n4PF3jRjrplV5QKiLnst337qdewUPH7+W1Xw9gZBmPebMlxXxWiyngSuAfmquAiVX2C7rmmXIy67r

nQzf9EKYAVfRzHfjB9MriSQmf9//bVUcpgAneHph7PRP3FM6xe9SV9ZMKajQV9BW5HIJ4NLsUlM0A/TAwCIYLAJ/Q6SDjWB9OSakm1VAAz/V0ooCbYW1IJncgM9EqSbkgQZJqS6jBJiSRgI7E1NZUTRMaA1PlchncH6jnIkTPIhk0NNQQOL4vqJJnawf7A8lFEreOnFpIJOJGiawIaNako1LBC425EitfGmN4iaZ3lmBHjZLT0CrjPykd4TeTXm1

wqRKrQrJsyXzyl4+eJmnGpm7HEQl8HA6XycCwqaXlcDOqdwMGIJjTbVBJpjLpgylIGRKF1oT7M4RnFgRSY1CCfA2TAtopUc7BSgO3fEmCCBjMIJqoUgsohRoiaWIOaMrhKo0AC3aPwiekoiHo0sFigr7WqNHFCHmpItEddCU8DyWoIe16ggJkaDzRG5EtobSOHWSN8jVIydY+pI2hZIG6a5Ex1Bg7HVH9tXI7m1IccZ6iKCkjQUiGDZghoPmDG6Z

JliCIjX8gOJ3gV2jTpydRYEHpXCSwV2DqhfnFrle6SOgHpZSHTgcMKqFCFTQYeEYL64q6BekVUDyBXSeCpMVfGuCyuHemAlHg4sj+CyiV2ji4pgXbnxZ2NI/Vr0yDHuiQZQoJ1W79Yg/g1wMRgpTjQJ+1LGFzJ0QugxGDMmKQnVQSaZ8hIM59AQxSxFmSNx2A10UmipF8Qtgy+EV2LcWxwWaGX0GJGQyQwCYzGWdCnou6HHn6CuQlAy6YRnEJnFV

S0WygkMRQzYl2R4oOQKBpUmNWGlDtfLhkKZ2EFCj94ewWYXcFSDSkLWYemVNDlMiSFUImYqeYpRaxFMGNBBDUIMENeDmQgCU2ZvgJdH+kzDBIV+Ca3e0LNdXmFfX9I10BLBtDng/4JSxgWOnnhJRWS+k517SbnX2Da5Q00rF3IKEFlIYOVoS51fDK4OxZkgXFk9Yw5WHQuDDKctE6wq0KlgPwaWWHUVJpg1UgIChWHtCfRI6STDRxcjLHSrDOsRd

F2BZOYwhJoQCBdArDVgmYOrDnWE9Ht8/0RTHpNgdFo1KCdWDcgNYZ4dLkjlEjLYRKDdhc1h/52qLfjXR5RA8iyDkRHILzoXWdfHdYpgbTGX8ggvo2O1EgzrEDYX0EUllIvGI7QSCwRJIJZYrwl1QlwdOdvwG1PAgX0cDLwt4HjY/GO3RWAdjL8NwofwgNj/DYDUmiTYgI84xZ9njfQPJZs2CgjvtICB90S0njS43DVHFetm8YUVZtQS8qRJQPeQ4

DdVmM4vhWRReB5vfwV3oIXHIgJNJAgQOHZODOsiAYJMOARCI+Aok3RN12OdiOEO1LQWrFOI2TWJNyInPAVpt2LMhfUsNVgJpJ2A9dhPZ4MPYBP8pSaSKKw2AwALLBXNTqgOIzCEnzh8KAmSOoC9sH9jk5/2aWVwDlTfAL2wHcNV0KVeZVoMhJPvSyPrEpTciLQ4oyGzD95MlH/ygCzkGALU5m8RXFJkyjO3x8i//PyN2RJOFfFYRbUf1yKwwowqA

ijAA0zk04UKNdF059xC/z38XTa/0cV7lTJUc4bsZzg7Fd/ftWPFcopN2S5IuKYQA5LgafwglKCC4Ek5huTrjG4TgeqOzU5/ObjeAXXSemMwE7V/E79PVPVkk5tuW0JchRPHoL0k2zRv2HM1OV7lLRe0K3gC8PxGc1tVOzEzjh51sDmwkxd4aaIb8K/DaMilXQbHlotXVSAiYDc/fc3z8J6dP0p4lCDPlrwQTXMQD8SVRlSz4ReERivE50dxFd8+N

TFXejjonXiUjMlRKMWN/fKP0D9SVLPmt4WMLxjG5ywDsRt9rsO33OoV+fkkLB5DfvXRlNfKixX59SR2hJouScxmdlmLXi1N9joivgHgguSAkis5fEKAV8NsNnljJSRVSxN5v5KywewGYykXWDlhEdWyM2Y1QgcjSFTn0RlufSfkHcgGGfgA5y7D+VFimFJnxX4j+ban/RSZM/mMViPCn0OQHBV8kHFL6C1Q5t85TWO1JtYr/gApf+bikKhEJI2PJ

8TYl4AcFzYkBUtiY1ZByNk0fH6wcE0BK2jiIxuDwgoc3Y3G2Rs1BfikYEssRCXtJYZKHxA9AHSKWYw/wkYAasZmYeBGl97du1vkpBa1lswDKADhjc0xPb2u8UmaHGWAHBEwSuQXRFPHAc84q7whxC4o7xLj4oCXHWwhYkRlOxB3LXHbpdcQqAcFfBX4hOohKZ2WW8O46bzui4ZUYmiFcKXD0a8q3PwT7i2vVIXfwShEQjKE5+StDK95DXLyq9jvC

AS6FSwO+WaFGLekGTdCsRLD7ZkvTHjGEk9UPGQw1ZFNiPiwvU+MdFMaCYSvixuUFn089NLz1owDdPkTuFisfWIA4pzEoBs9I3ezx89HRX+N/80eABJTYVPP1y0wpMQAIOFmMP+KgSdsFNkk8PgCqhk9RhQ2kuwFTUbFLk/EDBKCxSCArEdFcE1YHwTASDlVMYmPIjHw9qPHBLeBEidjHpgt+eYnNdmPYjAI8mE6ESB5F8KSjI8wPL9DbJf0aD3Q9

GRNESf0mYE3hSphEiDxQ8/0EFFvkSRD4zBxtscazCon3BTH/dxMRBNUSyRdRP2pFrLjCXRd3PjH3dRhUehZFhA0mQQxqxJd2WAV3dfEdEb6DtXDxlCbHGZlS3Rt0zQK3UYTcTEWI+nilwA+kA9d43E1xUTpRYJDPgU2cJLtdIkx0WiTEsEJCKg4kx0XVFceb+TG44bMJMdFqGQcDKFV8fQT8RXEAtGNgo0KoljRIxP0UhUP+FPGKotYMpODcKk2z

BjRm3GpIuRjxMigaSImRWAbds3bbHWwLcdRhjFQKKIiyJSkndCzda0IZP7dIpKMTLFrWcqnVQeufpIfxfE7tnmS+VRZIjkKxbBjWTQMJ9HAxB0eYAtxfVAcVbEhklgkGAd3MPxNj9jBZNLM5xNJlJkWxUpMoxzEtdCaE7omcXKFHcBcROsFYAzD/clMCVAtxNxY7FgpB6EtAQpnAEFJ0SwUxNz7EzxQLGyxLxJxNKSEUozCRTb5LPXPF0UwqExSm

knV0g9UPLMgtxnxfYP6JOpNZNJTFEoqNVC0xACXJsGGMsBTZnAThPoTx8ZTAtxXmDmwihWJM5BtJOUuhMo9FcQ2D5TGKfWEFTASVvFKTePBbDYx4JTCREwZyRgQW531JpMVSXXA30ipVUjrkLoPmbti1SE0ZwFgTDsdWCLRVU7CVmYSQ9WLNSLUtTytS7osiRZIMOR2gqJSk4BOswAsFCmq8TJZiXyJASUmQExvUiN19TbMU6i3jrbASS54GiW6i

mZSku+MS9TcISmklB3NLGl9CocGIVgU0k+PJ8Y0ytE/1XvOSRzSRUlnFGxWsCnEvQo8E9DB8YcFm3mIHIMrzJwiNZPifDqcDyjBwU8a5kZxm07/j68XBc8VdTP0NvWFkyCKsSmSmvGeKlxtsKPDHSVNP9isUbkogXOxJvVbyFkz4ugSN503GoQSwwUaoh1g24jdN1wIcRyT5sBqTgkBJ4RKZMtx9vG720FGYKPF8kSba1nilckkoAch70guMO94R

F9OIE3019HB81kj21e8h7Iwyjw1MGKQaF7PKZNTj0CF2lIloMk+O6E4MppJpwjbWW3Yk+sKDOilUMuKTOEHIPHw9jkMzKXLw30QgnAUMMkjLxsTJCzG1VJKNYhhwK0naxMc+VDgyvFtqQKm/kXOM1KitGFY8UViTJWLC3sXiUVhcwj06LSmU3LfsGKkG482xsVE0qZNcsWlOTN6lGpZmCBJCoajP4yyYsSzglq8M7GfsG8ZtLGF8pSCw7wV5avFB

w00RGNQk+wUpIUJ/olKUijepWzPQ4sYMgkcymkpPw/wbomhg6x3M9/E8ze2eKUriFYZRxmiK/bUiOl9OZJnCZQkMgMiy1o6AlizepDHDN5tcENOSyXEUIg9VE1KsTiyB/Lnm2QnVOFM/FS1Wf20FEEjaRKzsspLIqyhowrIhg7pMImFlkMXrFuonM5rMwIis8GRQlQ6f6W/kV4yLN6zKyVrIGzfpKGQBlRsvLNSztSdLPl5unBMg5sMRTGTMyFsk

/DF8UZHpzWyMZXsk2zy/WcyWyp8Gx35hPHZgAcc2UCqBcd8Adx0uzvHNAF8c6XSAC4hakNOAdQZEcJyKBc4CoGUBMAZQA4BVQYgEmB+IYpwqAggIgDkAbIUoC7gMLFeRnRSE+fH0RGnEGiaxnpLXCQx9EJeDmhUAEjkc5H0eGM8g8SKQAyhD4fHKCg7BY4L5YebSAAhRiUfZ1WdH4OFEWc5ERFBWcYUNZz6hBQTZ3ZQAEHZ2AQ9nMlGmhDnElBOd

BckBAQRLnTaABcWYVBEZQwYI6HdAnnM6Dxc8Ea6AIQ8kIFzKAeUV6DIgLnKhABdaEaADbh5oRhBBhboTgj8Y+MWFx4QwYInVKAoXdsHhdsoZ1W/lT8MoFRcEAQl2qQDUBRBxdGXVRCrACXTRGJcocRAhZgrwEJ0pdIAal3Rd3UJEHey6kBpEMRQnLOBKBgYCJz+yJAVUDccoANgCGQYnOYBHB9AVUDYAAATUUhcQfQEtgAAeQoBJQIQBbhrgehAk

AocwgBhyKnF0FKpyTRKAzpIGY5HHgcePUWsYHmTNAhgOnZeAn0xeEoQeZmsUnO+QhnNAEPIB+LGyiEwoEqCmcr4JnK5yWchZ1hyGQDnM+hmctFHWdecwaH5ztnQ0FgRznEXIOdOnYlGOd780512c78qsEQQ5c+lH2h7nJXOZRVcm7NFA3nbXJjA9cn5y9g/nahBNy283gAtyKoEF1QBKxa0neBv6asGRh7cp5DtzBEVVGjQNYLxn0QUXPGB9yE88

xAZBDUMmFxd/QfFzNRCXS1DCkM6ObIMQY84xCpcXUEgteypAQJ1TyQnb7Mzyc4T5zzg2wS2FIAvQOAEXB6AcuHLhFweIDgAvYcuFVBMADgHic44CvIhzFkQIDKdKAbvOERaTS2htxX0GVKHz7IJmU6IvIBOLTR4sKfLxy8ySMiKxkWP9HSYycn5EeQTKWzCuRNUXnGC9SgBnJXhd8r+AkAn4OFFfhlnE/L3yz8nnL/gtnEaBvzcUd/PSRCUR/KOd

BMKJFvhX8oXLiLIAT/OudkEW5x/y/IaikedPQZ53Vz2UYAq5RIAL5zIRcAS2EgKAXWPOAQEClLklkMsTBGdzhnRVDhg4XNGCogMZQGgxlJENFzdRSCiACxdiARRGNQSikPJoKw87RHyFsLTBGjzyi51FMQmkDgssRKC31DzQWXELGbxZmCWl+YqiGXFsQdi2cWV4ulRMMYEbk3YrOKDiwUwHDzkK5NpDhZdtGr0FYa4svxzi04DuL5CbPUyojjdq

lgpSk94v2KoYPdT2AfinE06o/2alQVwj04EoGpQS74pRtXCtbm1UDKZXGbT4Sz4rBKBwuPXsTClGniR44UrEtuL58RykXV2cHMmNhhRDDPA9YBHE2pUXMXEsRx9Fd8XExQMukoE0YCFeXCxXaKeFoxcMJYEzpTUhWAeKFfBkp5LwStZkpp5TRDG1CWaKZM5Knixkt5LpS2ZjRJocWQjcpFSx4olKgtKUqdZMHQsG0ZlMS+h1LxS7kv1KBwvBj4cQ

ULq0DdaS3UstKmSu7HGBxE+0tyyv0w2koTYSIPl7RxESTnYIxGE0xaKTEyLN+KdEf4v9Lt0vOjQ4HCubSjQbk70r+K/SxLBjL9hVeCNTeiGiguBwMJzIjLfSvrTTLK3J4FuQBsEQlhBc0vLILKuKdqhsxK3emGm43iSYSIzkyyMtTL6y0YWx5AsHXG0ls6fMqC12yoss7LGxWVUIwHhEkO+oByn0trLoymdyHFzPbamQhDFacpTLhygMtIluMJpz

gM9KXBzNS2ywsrrKNy5bOQpx8KdH4YvGMzJrKoy4st6kfMUCnSxsLPrSPSDy2ctvLg5aePaxdaGYSnpVyocqPL0yk0XJULgSdKJSo0P8sPK5ysxQYE8ZE4O0IM0CCrfKRyoTwbju3etA65LsDlNfKby5Cr5VJya5iB400ZQMQqcK48tM8MbGHDPQIcS6OrLByyCvfLTPShLQIfEJtj6TsKjsrIqnPP+g+YDkRXGXU2K68o4rAK5HXY5YDQvAeZe2

EiqErIvGhjEruhL6l0zwyyEuT43SolNw17aXYiqMx6ZjAj9tYX1UJjBSAdHYlcNUs0Ixa0TzKKJ8y5SsMrUkr0NQMOrfzEA1ycDmN8zm+f0OhK1K+/QGEhk+zHhIIs6susqPK4yva9e0ShIDxpgZjA/ClKgyqCqraT4lijryKXxfQrywKtUrgqj73Mc2yfX38E+M6Kvcq0quKo+9CYyYVtDmMNWSsqYqgqrsqg9BanLLLipKE/S9KtyqhKqq3DVG

B+fcct/Yx3fcuaqVKoysKqMraQWNKOEXCTNwsK3qpsrPKgn0DFTBXwl2I3XPKpar+q6qs2IoxGki3xCCTgjkSeq1KuWqR7Q3GLIg7RaiuwKq/Kr2rxfXZEXEr0XtE3CAqyqvOqUbZwi6t9qErFOqlq2yqjsGSWjg3h+9bES9KJq2KpWq86AkihBthPFirFC6N6r6qPqr8gyNQA47FmkoayavSrHbM8R6wEArQm6qFYUHFRJ3C9EsPta7bnDhJNDT

gkRMmknGrcK0S7hQJrO7EuQCw/CFoqWBC+cmpRLHaXZHxqJEmPhsKiSFaNfETMD5NZq8a6ms5qY2bmpRpUmHZQFq7TNmo8L/hcJHApfwR7M8cXnRaDuyHs+x0CAfHUgD8cakFPOCdaXH7Mic84QSAAAxZwBHBFIZgDccvQTQCgBtgL0DmBIIRcBgBsAGJ0mA1C9AFKdPAVZCRAu4bp0/sffJPRzkjC/yCZkdKXHAhAMjXKUXhDnZRydxQzOzNpJU

CpfIpzHiS6sPpcIGVNljkQbfMhR780/MCL4UdnJCKOoU/L5Bf4TFCiK0iqXIqgpoB/OXhxcl/Mlzhcj/JlzqEeXLud8i5XKrAWUNXKoKNczlCFRQC56CqLKgWouyLAXJhE0RMYWbNaLOi+3LuoZUeeuwLHkZ9CeABi4gqGKOC0YvGKNi6gppgZiq1HyFYBZIsWKh6pEHjyt6j1CsRvUGPm2KByFl1OKPig4oeY0tJNDFL6S50r7Ba5JNHYqiy8Ah

/rF3XaupVAApNAprU8XPkT41ZHYtPdoIJrSpLbUA0q+Ek0D6lZLLPE+2EqtixDxjRe09bGFLAGrhhlKhCdjHVZoIGBsIb1S3RDChVk85hCwyknCRBKLi73HwxKG8fFw9YBA4IHJ6GvYoRKmGo4tmxh8Y0pZpTSr4trluGm4tBLLi/TzdK0Pe0olo6GkkskbmGi7iDLC8EMtjoFGp+sYbTBZRoRxHzJOT95OXItLeKtG3hp0b+G4nA05m6UkiKjJU

TRoYazGw4pGkE6IsBEFeK7UJGB7GnhuxKpGyQWCYt7cshr4M2RxXEbn6pRosb6IIwn7TeymHGe4uGxRr4aRpJEkRyJy9xFBQvGiRsSbdvBcv0p4RJJgyawmrJoHtd48Hx3KEQVyAKbtGpxrVt90c8sH5jgSpscbfG3+3vLmzEkK8Z9YRpp8bdG+G0/LJsUtEbKxGhJvMbyZb9FAr2JXNk7TtYYZuqaLpKOgw44KhMiGbTG7poibqcbwn9kYQC+ht

Qumg4uaajfH7kIrgKbomWaHG1ZurEhmXCScSx6Lrl2bwmi5r7oDtFirk47mopohigcWPCGBvypmVeaRm9yVkrCudATfMumUJqqb9ms/A0rTqFkm0rkUzYlBammnpunM9RBOosraG+JpWa9mxFsGiniRysSh9GCfnRazmzFrWbWCRUj2ohG+oixhfm2Zt9NQqjRVgNdENLXhbzm9QgSqPISTG0F0/ZluJbqxOXFeR6cbKlsDqW8Ftfxe9HDANgSrI

LXIarCZvlowJWgLylaH660T8Inkb3FVgyIxxV/r2qlvE6qiNN+qRMt8FCErL4SKGGlbFAqeFEIgcRTSDIzW/EgAo3IZTUWCX1E4pwkTzSDEfLYde1ooItg1XzS0P6+DBqFzRXszy11qx1skj7Y3vk5K8GjUWDbYIwrFrQG+RakbYfiwcp4oyqlhiBS7Wg6oTa31IHE/JRXHE0AJzRK8X+BPW7Nomjc2lhkADwGmWoMoFqrNvjaK29zCrbySuBp9w

6KSHAw48tRtqOq82mgJZKYFGklIFYg85B7bE2vtr5KRPPu0nQdcbtua4m2pNvzaRg1qiD5iKbogQ5efdOvbEbq2tOlKTMYhtTcFSzdsA1t2rOqmaJCZplmpJWPXH1pgIrduuqz2x10HEyqhzmBk7A4fCuqXVR9vDc3SzilbFrSH3WPbP2zOp0qpm4FjSZIMLOJDx+gmi2A6d2sDrcMTMBMqzi72k9ofbQOvN0Lp28JQgVxARIDozr4OksuoogyUZ

QnxUOuDu/a1BfxoYJWJWZi+CPA+9q/aMOrsqbSYmhLD3FPwxjpA600Gd0Qt8hJDD4YWtD9oI7KOhZKzC/EkDPZqyazjrQ6mOnjsjFxO+tEk7o6MtrHbK25Ns3KSmufPi0/mOdsOrx2ltrvK6PTtVBYi6EdvLbe2wzpPKxEdNHnxACQITjb52yzo06Pyj1m8RoKSMP6DR2pzoM6XOk+TMkHaf4Ctpusxzv071OpdpQr5m4mQA5PzPTpzbm2vzr5UN

mtCqLAMKiAji6F2iduqVODEzF7JQeNWFzJvOsLoS6Iu+dUOEFKYinBgPILzos7fO0rtQM3EM3BFJmYI3CpEiu+LsXbAAhQhdVd4PiqWVVOnzvC6uu6KJ4qvm/FjCMGO2Tu47d2s7VEq+EiWlkFyOkTuY7ZugLzrRRvHxiE6uOwjs60NCS9o26YmLbqm6duiJHOyLEJWscdJi1Wv0BXHCcA8cNaqiBezdaz7LTzeCsACzzfsgQvbhy4HgHic68tsG

IAYATQHmAknXEEwBy4SYEXB9AEZBgB3oVvLNzPajQu9rtCy5CxMk+K2m1xSctHNMlBTd5Exii4qwq1Bs2YauNamK5OvJzfkT/QnYiiEUjYlosSZ1RAd8/OrCLC6tnMxdj80urCLy6jZ0vzLoAXJiKzneBFrqEihuufzhe8lAF638oXtKAsi7aG/y0ELuv/yiivuuDygCzXPecWCiorALkQEcHHrMwTXoaLNETavk56eqsDaKbQZCCwLXcxAp3ZbU

UnMILdUWl2JgA8igqDz9681HBBZihPjORyXNPPqLL6p3tscGXaxGZctXTVqBKn6t1sDbB4W1q/T/W5UslKBw94qj7464DUdKLS54pdLI2q5Ojag27enNLP6zPtVLW1CMrTby8arArSlSvUqz6S+wtoDwiiU6mjqequirfKAG2V0RZd2T5DhiFA2ipnKbytvr8oKSgZr61tSCrMEr/68sXJKTg0PDZLL8KSon6SwSdtmoRGaNuvJ5+pmkn6924+mS

hD22iKaqW+/vs36nWC9rrR+oyNEFwx+g/tTKB+w0sEaX2pmDwIryq/oX7a5G0pB9/2npRJbnAP+o37F+tTiDLsqNCkH1M2/6uf7f+2uTjKn9EtBfRuw8MrAHyyv/qz4rGvfUc5scX71761y8AZLLXGjfo8bWy8fqwGv+ajszpmy0sqRroSsOOmtlhKJp7Kx89jvwHgGygbxTZVfjqWpAqcgbdKmB+cujQpSD4Ck7DkgGs4HMIKgcx5NxPXG07oeM

/0WroargaM7zyvXjjIRLVysYHhB2+Uzl0KeNg/4ahCbv+qVB2EvfcbOzQaXJBVKWtxqqazwtvlSqKELkd4MASh0HtYGtqFqLBwjzGbhxCZu0FTBymvZrhamRRgqFmopi6IevL9McHzBuWugq+iHnAjiG/TwdRLvB5wey6fub+VYQBPI9JCG4hsIbuUcu2jCbZ9GArqxSKSsEl2VPEZNXK6vzIGl0IuefIbbbChwumKHkNRrvyFmCa8kOQqh+xJqH

O261J41uKpmoB1QKPpLxKY8L+VqHN4GSpNwMDVlVgGXEAYfbaihkYd261urSr3kOU6YfaG2qTocz1kW0kUTrLKppJWGhhjofT9ztOrBq5WsFjFaHBhjtrWHDhsls+l2GlBnOGZh4YfWGXDLt31YFTcc2bS9hy4bqHW1UegVkMxRbFPIYh2tp8H4q9sVtLQ8VIcFrQhmmtL1nxTYxukJUDga+bVBjEmz0h0WnoLYRU/SrOqYS67TRHzHdmqd8/Mdf

oQHcNMVrDwnqW+gc4C+rkqL6kGytVqqT7AsXVgoqlxHj7q+4vo8s1+ZkZx4zVYksj6UR6PoqiaqnkeGk+R6CgQpWXGq1dZtRCEDk4savJLitZRl5HlH9GRUYlhBR6lRqE9qDHw6roKX9mbkS3HPqFKNRKSj1GdWg0YVHcxAgbJGLRuUd4r1Rm0b0H8R5Uf1G1Rs6Vh1oR9IdhHG9bVodHDRjUcQoCh/YauH7R1UcdHPR092n7l5KXy05wx3VqdHs

G5fsFKaha8gTGrRpMcIb92tEhIaGrJlI4iVRxMajGKGy9rP6eZLrv9GIxwMZ64jS+/rvofcYrSrHixo0Y88ZGu0vYxVsjMY9HWxhHAb41G9MnrQUBQavdHIx3sfFhIB9DSgJELSsaLHMxksdXjkBsbu+B0OAcN1FRxmsanjSytxvr7dubsbHGgx7/kbKSBiYXBd9xzcdexuy/1IgZKJQ4ebH5x8cfohkm1gekJtHUvXvGexw8YjoeBpHxtRd6DH0

NaPG0auTYc7EprwVO+WEimbdRQCZGqTWmCJaa6PNvAT5SRBpuVGYJ0nrGqpbGzrsE5ycAklS0Jt5CAm4J3Hyrdp4P5gzxMcKCeJ6jWzlswnzZVwdk4JmitVQNqJoibJ7XpeZqC6Aht5gAnCJ2CfYmLpCIfQqp0CAl4mSe2iZAm6CLIaSH8upsaGqaJ4Cfgnh1Uoeuatsaqxmt5JtibomBCR5uYqHhQ0bEmFJ4idd8eu3it1p+uwya0nJJvc1kr5u

8rUwb70Vif4ntJq6LW6MREtDoZJswavQmJJpSaRb46rYYsqBKSyecnrJkIgcqCuU4YJbvJviYwmwps/BuG3cO4eOBZxnycUnM1V4YBHlCW+hCm4pvydfx4R6gSSqRR98c0nQp/KdYI+WpJiwhBWwolynfJnUTFa5WrohlToGgifEn0p5VoGxB9Rtkr41xpybymdRKsYlwabRKHqnOpxybKm4pudRYmpphqa80FXK1vmrUp2KfmnYI9ar7BcMSDHD

Rxp4ydC6W2HnExh1MmKY6m9pmToo6esFadOmBJ5X3iz2MF6qwjZptKbOm2g9gjDI8I/vUChzx60f6FUSb9AqkPkKibnHPxvMI047CR9GjQhS76azHFDLpPcLSRUmrXGmR8Ud1pJRoIXsJYNDCFXRySMUd25UZxziCFzwXDHeAngJmuMb9IvwhRnWR4fWx5x8ALE+R+cNEcgblNQGj7tYdY+FTt6ZoHE+ACRk2Qv1SXEkYowfQqAlcggkQvC67Cpw

Am7YkRoWazCLKctC/QHZEKv+H6Zj4a7ISPK4MVm6GLyuaIkp2QnuHZZjWYVn+9bWZq9rSSKfGwzhw2fV9jZ0Wda5x9TYfMqzKHYYXQHcG2bEq7ZqCchaVqX3CWH1Z92eNhPZ0YcJTxUT/EmHBiN2flmPZpWa6GPm0sPbaEjV2blmxsaOdNnW1BobfU0FZoaESk5o2dTn7ZsrooqbCarAx7+gyOZTnA5mOcyHEhvLtyHYQ8SmTnNZk2YLmtlaSdrm

UhrslA5+iMWcmwcCISdS6RJ0JIjmXhEWbyhxZnAk4m1UCtoQrZZrudFmb0oLLnkAu8ZtxYD44ebnmx53udtlSJg1nJMwSN3F91U/dMnzFGZu8sMHGiYwYrZD5zmYVNuZgsaA9jOhQYqIlBmvSPmuZyknvmu0rcuK50sSQeT0OZumdvmP57gYk6+BlTuvnAFk+Z5mFOvjqsw2Bnvs5DaZ6lSAXT5gd1Y66BpmTRCkF4+YZnoFqjuPHAmlsogXkFqB

c/naIFxrLL3GjhCwW35lBbwXjo5AZ+AGiDImUxiFnBbvnAyx83ZStBY3DYX351Ba+FIB7heUxeFijDpr+zEmcKSvJwRYAHIO3D2g7CZ+moK7SZ/9FdLTpMqsy1XIElviEiZhmpUXpFxxTrHz5Bsc4JFFiRcZrVFtUrLGJbc/tvaxF4JnMX9F8mckZDcU/psWb2teZqIAFkhdwWyFhTVlK8xo9tfmb50haX6BSgfTTGRS/Em8X2F4BcH6Yx53X9xk

fMWp8WOFwfrbbh+uCREE+FuhbIWKazvt7YrUBBa8XsF/hfoXK1NyqLaG+8JnZnSl3JZTbKEsvuDSQBkpdoXQl0V1Tb2MdNor6cl9pdO62iRWoe7ACgQDVq7ui7q1qdapPK4L9a1YsNqc89AGUBKgRcGUA6gRSEqBNQeHoWR0ADvK7y1kbgF7oaKBtEKgttVArRyEMSpmuQsbOpRZhccsVDcSWMGtHnbkilOt+RotSecWa3mLfMZ6868XtmcWe1nM

PyRijnuRQue9FAvysUaIqAQa6+IpVBwEPHMbrflhAGrqW6mXrbqv83IoV6MEQoq3Bii/utKL1ekApIQR6hMBNq9en6BohTcrZbAoPu4F00R0ycDBOql69AoeB65tAu4QV6o+GhgCiVAod7BiwPsxdyCpRGGWIAUPItRw8mTkYFfe5gqdQA+1Yue6gnL7LCc+C1pHmWIAXpAMgFIZgGUBekJIBgBMAQQH4g9IOvIMh5IbYDcdMAJME2XLIHZbCBtC

3uneIrMR6guYD4iADRyMLbOQPChG3JJuBDnOhgOBijR5c55BnCnLeWjgLiYmjPlhnumdme/wv3ygipZ3fhQi2NfCKK6vnL57r8qFZRWoEUXMSKEVmFeWhJe9Iul7MitFYnqO6vIqxWVc5XuFWOULXKWLKihMCGQyVtAGgKEe6lanrboCAgbJ0Btlfhh5oRerN7l663sokMbZdA3rfcjF1KAd6wPOFXRVz3qPqE40WilWli2VfTzhi5PJe6eCpVfe

7+CmSDzh6AfACMAVINsHrgWQegCEA3HbCHkh4gNx1VBnAGZA9qMACUE7zbVvZbQA+pS1nphVyXD37sqwNHPU5ydb6mlIv5G5d9WjeRtlChrsJ5eDXXltTDDWp59Mh7AVsHOu+XGcmNe6g41ouvZ6S6kFeTXue8Farrm6jIpSLYVsXLF781pFaI3i1lMFLW5ejFcVyCiqtZxWVeyJFrWNep1AbXXoPJ2bWaEClZgL21y3LFQPRy3qZW5UeaCyVRN5

VG6LuAJhYjJU8cdfYLne7F1d7Z16YrFWvemVI1hl18+pMQaXOVamWPshVde7t1j7qNr/s3J3LgWIJJySc3HcuEqAbujgDmBekfiDgB6APJ0tWkQGAqfXoc19d9r9l2sL3nWNKVBDrv+/jkuomnS0kaSqwW5ZtBwNgNag2g1pPIp6HgODdgruJpDa+Xo1xFYLqAV4IsTXOevDbBXIiq/MhXb86jaWh66+FfI3s1yjcLXoVktb8BZcstfl6GN7utKB

e6mtbKKdN7lGJXXoL0B43W1qlbgKRUTRBPxSaUlztytQPyd7WuioRFLk6GPYGRdvcidcTyBVl3qFWVayADnW6YBdaQ2oIbTcnqL6tgqvqDNvWsVWM8ndZVWvuiQDyc6gNx2wA6gfQArydwAyB4B+IYgBidMATABmB4nSoFIAuAK1chzn13Zb8331gLa/XGYH9ccKTkDhEzk+HFmlLbtSmOsSK/ViDZKYSMfuSS3nCm0FS3/BiNYy2o1pnuy3/lg/

Ly2kUT+Aw2U1nnohXkV4jYq24V9EGq2SNgtczXiN2XpucqwBXN/zGNnuoALNtiADY3CVz5217cAcuAG2+NtteG3aV26A+AmZRbcm35oCFxm2Xc6Teyh4pMgi03tUIgpW3hi6dZU3+d7baJcNNstFCSmCldeO3+V0oA3WjNrdYu3TN1VfwAq4L2E6A9IRSHOBmAPJ3rgYAJIDrz64OvMUgewR9ZtXAVv2tHb+9HgnB8HOaHa2Ad4f1YYZk43ElA2U

duLYeWEtzHc4hktnHb8Hw1xDcUr6c3OrQ3id5NdZ7AV1qHy3cNynfw3it9NdK3Yi8rbrqGdp/OSKKt2neo32dnIs53O6ytd53q1/ncF361kXbmRDcgVAnrBtgGCl3DesVclxuhDouZX5odiMhch11XbBhRCazXcCvc7XcU3/c5TY22rurbbU351sKVcISue1D96De1db9yAnQze4KDa5Vezzrt9AHrhJAXpFxBFwEcG4geAAyAryhkOvP4h8ANsH

icGgfiEwB4nJtcB3284Hd83bIeVCwl0U3rDfUyqT3Jh2phJLWcsxKvXEJ7Yt+5cg2qPdPat3M9sGFx2c90Tzz2UNrLYo2ct0nYTXydsuqK3K6krdb38URFcb2kiiXLq2s1mjca326lre522tyAA62+9rrcO3hd3rZ+dwc4ff+dR9iXaG36QGlcn35UTOc/oFd3gCV3ncjlaJdGBVhIILltrfbW2d9iYrxWpig+vU3dt0mWQ2z64Q9YKVitdY4Lrd

m/dmW79z7r3WKgbiAMgZgeuBmAhAAAFlwgQgEXA8QRSElBHNx4GYATapJyD3IDkPf2Ww9q7FfjC6T4BC2cvJrEwZwYI8MwOwYFPZwOMdvy3wPsdwg+z2ENkg+Q2fCzBAq3KD+NeLry9indRQq9+g5r3GD8iAb2yN5vbrqGjw3Kuc6NzvYrWHnJjZwRBDglYH3RD5EC8Pxd8WEpXx92Q47WtQKHGmYmF5Q5pIre5fdKVdiRFo33He/Tb0OximdYN2

D9nbaP2BsU+opdz9i3Y2Ord6ZfO3mkRw7M2JAJJ00A5gegCMAZgPSAaAvQR4BgBHgEcFcAvYGAA4BcARcCEAIjnzaiP31gCiBISaPzG8ho9+yBwmnBJKfnhzGLwsgAYtjI+wP0d6Dax3l8/I/eX0t0g5KO/CynZL2ydznMK3z86vdFB+e1nfr2ReqrZaPUiqjaYPUVrg/RWujzFZ6Oe95jc62Bj7ra16hj3ADbBRjqsH42J9sIFBha0FPFYlPc83

pUPHCtQ+t7yJj5nt6dDk7c2Pd6t3tNRjDw/ahxCgnDjN3uT5Yr02bD+VfsObDuZYf2IANsAoBuIGYH4g3HS2BmA8nIZE0AknIQDryZgCvKMBhgAyFwBde8A8R7lkLQrfXUAI3l5xKS3MrVRUcrYChwtI5/FOJIa5HeXgPhJLQnYRaNWQ8GMT1Oq9aNqraeNwdTvE/Q3UUQk+oPiTyvboO018k4zWythk5q2WDvNZq22j6XKZPmt+jd4Olejk/6PB

6yw55PvnZEDcceN+opFOLUHTRAls6qU+NhFjoRG3g3RHggU3lTqdcFWDD1Xv32NTvY4RBOeVAosP/ek48NOg+m+pURNie+rZdQ0HCUHFD0zAxPBY+5NCuTEWOBtSYZu5BsXdBygDv4Yl0fVvHdgGqasPOKMb0dlrfRu+tgb7EjI34w1xC89QavsQXGeBk8C86CgUxiJfwaLz/xYPbtQ+xJdbZmFPvMcX5irFcWQJU4nUwK2KZuT6hR+Ov44iEu/r

IZJZaOjzwULs8EIv0Ls4Tf7ZGy2kkw+XE0cDbXifPrbHbStJkYvBPPlSjbTRvPr+qwAcDuDLBx33GcXLz7rlz62LwS8nHd2acaCxmLyS/4vpL2GUzKgyYozMo+BP1r4vWL/HEEvv+bcYjrxsDIlvkdL2PBUup4ghbpFi0VyN4uWL8y70vYZGgevHtJaZkUvmPXS9ja84vjoVwF8AoncuA2hy68uhsb8bXQJ2d5CCsKl+AfNFIrMQe3KIJ0mYaXMB

8oT99ebRCbqaNSrrttGYrrCfQoyRHSp9xPGjpb77UywErwdPyxMK3tgsAtvuq8RmipFixm+E/GJTBaEwqWXR+q6cUCjj5aQ2IS2q6YHXpfuaiHRJmq9xH+rqSZ+4bkOst0IoJwQZRHYSofAor0CBqm6w1x2a7qukY3SfqNO8fnkOG1rsa/ebTJsboltitPa9UH/mv3iaEbMRFiBqzNU6/mv70b2YIg6rDrmHGI1O6+u09JAKadmp0YKZGv3q/a/C

mcWi2fZx8+Xq9Guzrjv28rbh/WcYEwb/64hvaWpXAuY91E3deu/bb8/RLrY4gi7dkbr9EKj2+swfSGsb8/1iidcA1hwyCbrwdlribkIiqmsqwVosJa5L4dmGT92m/RH6b95EZup+9KlW8XiQAg/VMqgVs5ut+MJdwbTRtfrFN2boW8WoRbnun5KxbyJY7Emptp1KrBTc9qIbcx3fsdNlbkqrzY1blLCwur2vdS05cxHW/layq3CCfbI0YxbfaP1Y

qvNv9bn9s4uCsAyk9LKp2VpVu9btqZM5VGo8MHGbMRqY9vdb1qctv/+x8ynG9KSfMlv7blqYtupmxrCw7lx3Ds7Jo78VtjvHbqju3HcBkap7Uzb9O+9vY44gcIWyB1O+anVbgu75VnL06hvH+y0u89uQ7+O+fG4F18aVug7h24rvlhUK6U6wF3KsciY78u9DuTJb+fAnR+FpZyh+7r28HvppU8unRrkCHBBo7btO4Hv479QYfK7OvCd5a27/O6nu

+VKwbInxyzzsXuy7ye/jvgKzzEYmTaMMr7ul7k+4nn4NxZtmSj7+u7ju+51jEiG0ux3Ovvj7hu808a5nIY7m674O5fv6hza8+bACKLbZuJ7n+9jnDrvrpoTIHm++gfZu2ycSIFu2QifugHjO5+09u9bo8mDiDB/bud71A1MqUW52avvRWre+XuvK82ZOHnK4WPdvBbmqeFvEB7fShu9ZvyqQCpbph5luWHqQ0ynVZoEclvGH7Kq5uMTcDwRHpZm3

E3vhHhm9lv6zLh+yqt6Vu5kfmH8kcoeT7gW/5buH0ml4fUDJkYv0q2sck4eVHnh7aqVRkaecs0NTR+qmRHuR5lHnpm6bZuTHnR6jsSURabmqJXXO4UfZH3R87tMzzaf3Ttqpx60fbH3x9Wr2ulokOnFxU2+8fVHi6uO6s66x45vTH5sjum6KaG2MeQnnx8+q3pvxh+rJ0pJ+luXHz3z+ncym3nSJCn7R9EfUasGaCQtEeClzjgnmx+yei/DGZJqd

4GJ+cfqnwu3EXiZixfraKHrp7se/bGJbKWvHoZ7Cfga4Wagh55ysQ0cZWiZ6jty5puc9nKn0J6jsl9W4yhgYOeucGesnuJ78pMadNTXwdG+mDWeWnw5+dtvgZtrgacjxyMWfHKJrzHtIZtmvOeDnlVzTJQWQ5C1xB0aR/2eUnjgOp61UIeC3xA7h58BfjcYF+zk+BAh+3upmz/UChM6bhYH1A7qB+AeVXASxSgWig0gzpYXqh/UD+iAPChCqiDC6

/vn7rB8cVTJYgJ8IvzWCl2f3btF4peAmcDepUiSfShGxW7xl47vwggCRNulSFHF7uKHrl6IeeX5xjIEy8RrM4fhX+F9e4Hy8zznQgeTl8Qf0Xm/weocyc1VlIBKTe+lfzaAYTtjsLZ2alflXpl66YKaEkMxxXkYgMN8yXzB+5fNiIWjxvxEVqTMocjGVp1ee6Q2kPArabrFwl6X8e+Ne7XvOj6k7VEKi0Z2qbW/UekH7V1BwoyFovIEc5I1+/uVX

hoLxKgkRcVS7NXQB8IepmjaTxEWsQienG3ngF7eDpBRKC/MMbbYSLfin0+gOAlsdNDYYniqt+6eGghTQYZb6G/Fk4I38F5GCJCMKHLEg+TqnGf/n6t5GDMHLbBYwwcNWDBfh35t66C9GRF8CoIL/yr2fmn95+1dwOtA++oXqE8IYeZ34Z66CJZJrRAlG6Jt/3fRQtS5ANaQzXVjFT3yZ5j5ZjK0OdxqXgL1ve4w8dCAY00jRNeL7nvd7veY2O2QC

XD2unJXfknkd+ZCdeE2Ru8IL+rCEff3uMO/HuKCXE7bKxV95SxNxXE3UplNaClQ+DQy6mboMqBOPeQcP4/uAqTkjPjsFBLlHTg+XmC2Wi7KJ3SmI/mQjZpXloQGZ4vRGPs10nI5mWw3UohZDj4CZ55ZBPIIzwM8AGfd31d+LevheeX+Z10ZqStJ+PrpgpYi6OsnS5Q8D8Tpuin2d8U/7aXeFJnjrdT9ifJPwxdMrNULAV8Vp3iT7A/DF1AkXx68J

5GXQu36j/JZFSGkn1ot6OhgU/NiXYG7kMa2qKkGf3yz60+vP58RSOJ8FPFZbZOMm6aIkeTrF70CsZyThAc5q4lJusBaL9PRfw08hWoQUSth39xHv9myoiU9P3oUioTDCzJncYpbYIUvgr4pu62ElDfChKEmbxEIvihWq+YvutntbnLDPl4lctTKKq/ybtr/XZR2w61sGdJI42QlQq3G9HJccPbBosJUJIZw9qxP4b5wK2PG+m+62ZwkHfxk7yAym

Jvlb6m+0b4jgZJELFGNsMI8cb6Ru9v1G/EvzFVvE/wXMfAnO/lvmrH2/rvs8Uyq6rIGlJfX8Jb+tZnvq772wiamHXOYPECr5+/Jv/77rZfSO3gvRn0QV9YIwfy7/xu62DmcOr4KYrk8WmRXb7++kf9dleYE3m3jRTqFbG6x+UbnH/IiHcCiehJE5FO8Runv0n7W/12JfWMJTBdnx7UEf7H4Z/BFzGgoY5SKFKq9Hv37/p+DvsLndMx6cVm2QmFxP

3Z+hf8S8ysMZSkgE6oYAX/B+yfvKM+fNCNiJW1lfxH85+8olRRRpTIkLWJ+Lvjn+F/6OSEC+pRMCpKEdjfun9W+zf2MoEt3w8E/FqaJXWZCoYbkV/o5UiEoQHQXiWkLd+KRD3/hJYbtTn1JOW9zG6EIWSG/d/fKyTLA63Ek2UtooiIHRj+g/uP8A0wO3l5Iw61IEnKs0/nyruHQ/kzip0mrsHDyeqzNh+D/4/l7j1Eo0ASmY5ET7Ftj+i/r39jLq

GS5I8a9qDsUSnq/zP4B54WeLFXITmntV7+M/4v+Ojm8Etq3YgkfbYL/obkP7b+Myh4vswMbfSkzrUzKv/H+l/k0VhARMRDdPIJ7XMTH/W/+O73+RsYaQK6/GGD84kt/0/+14FzUa2hEKqMT9CIW/z37P+49c7F7Q1Wk3cD/C/j/4B8a1iBifBRlESv7v/Rf5n/IKBWMddIGWHv53/QAEr8VLDWMMhhoMb3DwAiAE1/JAExaQ0h7obtzEyf/4L/LA

FZ8WMhpYBoh9MHtyEA9h7EA46JKcBE4KmM0zz/agH9/JWIAoGnS0WSVj+fZv7p/e/6sA8zyxGOJQTCHUQn/RAFqCTMoSoP5gRVRByJ+EQGQAh2KEkYzxBaSKhJfBKYIAuQFmxFNDjvQFB5yJgF9/Cf58qIgRSUA5iPsNCKA3TAEsA4OJGmcd6QNGYQYAngGiA2OIR0YpSFRTXTToKgF6Anf6W8KQQfIESblmVSruA7f7x3GnAqxeOp1ONSxmA+wH

qAtQSZyGfowkdrBSUAIG8AtQQE0HTiJEGOhvxXQGBAiISw0ZdRMwCC5M1RIEOAgwHkqZFh5ApSLWvbFo0PJyog3P95eA6DIRQY7AfcU3qA3KoF4tF9C1AiATeEGYT0MAvDfvSoHHDaoHtA9OJcfdWgd9X9YtAgYFtAr1gqJIZjocRtgsMIBiKmCKa0PGoEzA6DgIgDyAkyFog0SVoHVpUG63Cf1aM0RRLakHYGTAvYEdA17Ai8VxoxifHDthUf5A

3FYFDA8hI9RJxLXMVaiCzW/67A8nD7AvkSLoFNx2Yb5IcdCYG4tc4EqJGz5b0CEw28U4Egg74EXAyEQYxFy4m0F96Q3L4GrAx0Sj0PXBEUBSgZ4eAGogp4EBJDcgvEPYh8hJYEPAwYHTApJIiYZ3BXoSkgpMaEHA3fEF8iOL4S8SnA1cObL9AmEFogtUR7eB6Tn2ceTH/MkFTAn4GRSdcYZ0fD6YGDET0gx4EUg0YSiZQXCPoNfBXiKUHkg4UE7J

Or6i0NhD7UAnafAs4GwgvFIAUXCRhWVfA6hHUGcgxkELJIb6YMcSrEXFEG6grkGNiHtC+ERBxjMPxib/PEEygxsT2cRnBeQVwg6MW0Fmgj0ELJI74h4EBTgndkGktQUGggiFLyhE4Br4IpamA1QHug1UGd3b5Sxg/7QtEBMHcAgAFRAhZJvfPhgwgdlISbW/7mA/QGd3TohQmEJgxNQoE5gnZJQ/DpT/aTQgBYasE0AnZLHwMFDFKP35W8ZsEWAh

ZJ4/dVxqtBvrdg0sF9iCn5bJQuiJCIcGeA7dB54SWImYIUrbAzIFJAyKTrkB7Dt4dhrTMTf4lgqcHW2d0xvIPETrtaECTg+O5IULzKShGqZ7cI8FR4NMhvofIhViIpjViWQEtg5YRU9Y8BlUAATgVRcFFA58GQgQDQXRJXCAkS8EaSZhhI+ISjeQejpZgogE9gjjKpEQUjduJ/SrkQCEmSfUjhnQl4TCRCHLg7A4GOE3bzhWn6C/e37iXDtRxAbo

jspA1hA8bX6m/AiEtUY7D14HpSkiRqqY/E34y/PDJA8F9QAYBgG5iaX74QqPAd/eZoWUMhxs/HG46/B37pSLCTQDXDoGwV/6cQl77cQ+FjGYcSF4zZr75ffr7pfXqTN4HUgAYMdgDRLYh5fKL6FfBqQbkaOiL4HHyKmQqa6Qmr7LZQ2jwnEoTDSXBSKQsyEDfaaS+qM8pz3UbBBqXr6RfVL56Q4LL0mUVhh4TQiOmUyGeQ8yHTSL/6TuDDjmUEyE

6QoKEOQvlQbSDHrg1AfhxKOyHRQlSHLZIKC60PNjQiG5rJQ1r6pQ6aTIApogZKSsoDrZL4eQ3KF3RX+jiYYKJToRQQ5Q5SEVQiQi22TXRXoemy2/PCHSQ3bKIZGwgVsMZhS/QSEUQgmSMcY5bI3XqHoQ2KGkA4aE9Q7KjKgoUFwg2mRjAcVykUL3QzQqMG9SPBiLQkfAZ4T65mVTow/XdVDiyAFB8vUQTSdEIgkPQKbOzX67LZYFjfeRzhwSE6EQ

tHB5PXLZjIXXqTXQo6F3Q3MQi8C65NsKQgFuA6Ex0SvDHQl6LdDXrrmTR6aY8CpjoUZBKAkGzA5+LdSgPFio7XA6FQw8GaTCchxVSUoZLXUigrXZGEizMWaww2GT4VVfZuNKror3KXQzPfGHceAa5v3YSZY4ZWC4wimEwwqmFzNe+44nRBLcMR0gRkJxLe4TxahrNLb47BIDKyJM5cw8sTj4DnyNXdSjIYGdD3FDmE5kFWipnXmFWDfjAoUVZJCw

zmHywnmGRxe8qZ0eYGFXMha4UeUKMwtpzowhCa1NFyFUNBmHQw42Fwwr+ZgTCVyj8XcL7CSGF4wpmEmwkK7idWmLKBSK7LCZ2FGwtGE2w2iDPjXy5bubiLTScmFWw/2FOXK8bV3Vy6oTK6GGwiOEEwyy6hQE8YzCIWSWw1GFJwvxqGXa5DGXHOQZwymFuw0rzIDDS6IxERgFw12EBw2S7IdBS6vQw6GAwj6FxecO5yXMcxxwsOH1woeBAwuLz9jP

25kiMS7/Qm6GwKVdDSNZ24tBJi5rQhaFzwL4obwOqIcXd0rcXfWEKMDaEzws4R1jMi4gOX/zV4daFTwpaFbQ0sbxiHC6emQbzLZbeH8zTaGzw2hI5jHfpIXYSEmiJeE7w8+FnCaC7hLVfo3XO+GnwkUiPw6MZgkG7DgXOWhbwyeFnwleH/nKjyPUcqSyEABGltIBHLQr87S1JwYZDaaQfw6eEwIkDBrXD86IIwBGfw4BHjuR860Q8ez0wieFQIrB

EoIobCcla84qxUzCDQrqGHTUbCuvUhFXnRcqGqNAhUI1JI0I0aEtoY86tieERnnAiGVQpqF0eWqHHFAbJ6IKTDUqTUph9H2HpQ59hckF1TX6IRFpQi/DSI0HzZQppIEXbUax4GPoZZXAiBib2ynwNZJqIljAaIkqYU8XN4pMORwf4ZDB9JAxHutJexxZG7zmI9fCAoWkbkI7hHFKGzKM8CcxOhfyHOIxhELKNxG9SJyGz3ZCbKaOFL+tFxF+I0OG

xQyyEUTHeBesel6KwBhG5NCJG1ZFf6GQ40oerHxFJIo4CRIn2GpIvIhvCImh/lJ874Iv1pmvdSFvgwSxFIvBHthAhEiZWSHahXzASQ7EYRlYpE1Iv1ocGBOLKMLSgKOVyq4I1qQlI5iFEkUYjeMCqgCDPpEOENpGDI+EQh4ARxBjb/qnXRBJUQrQxMLafQNeZQZ9XIOLLggCTEQ4lzg1ZEYgNC9IQbLCHZycaoqDRZHIQ2TioQz+66DDZHnIwbLQ

4KHBrcVK53VcG6LIk9BGwKSgkYS6r7I60gZpbC5/ghUza6FmpwIqmoBIerqiDFRTr/bOTNqch4ODDG7P4LgQmSa8EhUF1QgodhDAjIWpgoxZG7g88BQQA8GBBOFEgo7wZYoqPDc/NHhP6VZJBPFxBpDTVAkoyMSA8coSRkU8hN9bGrwoulGNiUcHlyXChYtQlGE3WlEoqRBIT6TQgfMAcFK/YFF8o3tACo/8RnuSiSqVPFHNpGlGSoxFELJOsFeQ

AO4AjDFGgoqVFPiQkjjESsFj5TVHEo7VGNiPMF+lciZb4Q1H8o5VE7JYMFQCHEHlCS1FKo8FF0CGcRlZGqZD0P0FmpRVEIo51EU8NOpOgjvpCuOFLeo9lEWgrZBWg7oQ2gr1Fso41FhozlpGg4QJ9JENGxotUG1vDUFGYaCh57YIYxo61HUDOUG/+LTi/MEVLJo3NHnxdqpig3MoSg4D68oqm5Oo/RJHUCWwConkRrJEtG+o/YTj3Jmpdra0gqkR

1E+o/RJy4YmSgUbmZ0g8VG1ovtGuJQkHdKVei7EJNE5ottEmiTH6YgtEjdcE9yjo2IZWo+dGW8N/60DG8bIg6NFEojdH6JcEHlfEYhQgtdEgjUNGV3P4HQgAEGLZIjKto/RI6fV4GiEfWgtLW5IHoutHPA20LHYZ4hzkeh7zIs5HgJQ4G/KX9AnA9ZGvIx+LrA/ogjUKYALgnaq3IyDFzFeYGsScJg/IzZEGAkYH7FKtIMDBDHzxPdSgUHP5E0FK

q4YtQT1A+E4x0dmTEYiDFf8EoG5Aw8DlA05EkY2OIpAmM5+QjIHwY6jHRAp9RYkeIE4Q6QY2VX5Ff8HPAhApMhMycIEvI+G6IJbwEbwZOzK4AdBoYqTFOA0ii44VwFBDJqqAY7gRWA5a7LlV5AKYz2ILyOLA1ROpRJlBZHyAryBaA18FUYyTHyA1xpSYJQEjUKzEyDdDHLCBO4SA9LDbICXB6YvgE6IJSKCA1sReYw/hsAx2gcAghSMYzjG0A/Th

WyPEQ8KALHHRUgHSkbCjciEzEaYrPi9vGxp4AkBR3PG5HhYvlTZ8G3ATlIihVUWLG5Y6yhbvaHCWScYESYpzGIJRWzf/VXzXIP/7gY6zEr8GN5aIFUi7xAsTFYvmJOQwTivJa/7NIlLHHRT14H/JmoIorrGY8dnhT0W77r/RDDjYugQnRXQiV0SNDwxObHt/Qf7OgmdrzPfjEUDZzFhcUSFD/HnDwOKpH9IyZGw8DZihxLv4p0XpFhVapEvnWv6Z

0fyHWBKULXYnLC3Y4a4l/HqJl/ECq30fAbjI587vYwRbZ/ZDAdvYmLHYiZF3Y7qIvUL+SrJQehqY+ZF/YgZFh/aDi4SSP7hkMZE3Yk7EQ4qrgoSX35oEcPA0/OAYY48HEA4vKJO/YmL+kV34vYy6bE42pGCLC34QXc3j/sTxbw4onH/Y2nF6/aKQG/fRhkddPqNyLJGXkZKLq/YtDaYLX684scg3nbJHJRNbDy/XzHGEZd7+IMhG+IyXGScUX4sY

CNDKaLsFi48JHK4gKKjqbYTPsL8SV9RJES4gXGocEVjM/UVhtDI3E5NE3H+I3H458UtBU/ZZGZI23E5IrphQcHqxreQThE/fjKK4/nF248n5GmGNAE/b3H6IrUaGIzbRpaTSKpAjNCgsKWIR9V1o0XWxGQ/JWBViGH7gYOH6hNNC7J4+SJdJIH444DeBwlcPE2IzRHrsN76vID74tFIjLWI4UZR48ugY2F5CFkMPAJ41C5J40vHkRevERQfUoPfe

REd4gFC8VP3CnfCoGJoJiLw7UOYEcbiy947CKzfZui9kBb4SI93FDfd7AIYALDbwFgjSjbCIdfXshyBCrQL4rz7ZsQxQ7scr7VEDfECfctHYMTlouhE/GxfJrAk0Sd6JfA1w349TAfIBoTOidJLksEL7rwp6J8YpUaGlDEFMCSAh+fd/GGlFz41CNHjJnKUadYGz5CyVvB4sAth74vcImfAbDJxS8QIEmPissYEj+YBfLKhKfECfL6GRkF4gbuDd

ruuIsJ/0EeD+udOhnCU/GKfNxDO0XShgnLSHUErz6XNBUz9oK8TFcNAn/vLj7+pCvBXCHrhMEvOhdyFCgNWY/hb0dfE0fXrB0fdIgMfXAmihUj6/sC9AiEzgkQcc5ZHhYEx2YA/CQE3D7tYXMq1OGeDX43D4oqLwQ6YBe6yE2ULofKsSYfH9AJHMwmCEhD5zocYhtUFD62E+94QfKAgpMaD42kAQn3vKJqIXW0LVo7wn/vXwma3eUoBEp+onnbhE

kzcS7/ICiaCWNsSDwI852pLhELKKIlOMZaLfUR5jQUPoH5oThHS4FInG4KkIacS97TMBPgBw94oRE/InnnKhg2iI97Ieel7lE5Il04AonVEhMit8Ld7AvRIlb2Rok8I3Bj6cBd6pcO+idEh/innVImIhYfDjvQej8JOJLhE7omjEnt6rcCLBjWQd5DEiolNEqonzE7ihlEDnTS4WWKajXIkjE5okjBaAHroMow6SHEwrE2YmHE7VylYst7duCYCV

vDhFJEvIlrE8S65vLKzpvNwgRMBonPEnok90GN4ZEP+Ijwa0KPErok/EuYlzBZvjJUKrBuNKUYzEsElXEjYIiYY1wiIX14n4uEkHE9YnauMUr7aZ157+C4nwkzEmUvLCSuEPWQRQJDD4kjEniXDKQ/wiHDKESd5ok/YmREhEnMvQmQ6Sf9qSvCklMkwkkskypiV4WI51oBklPEykkGBQpZsvS5ATmTkmVEqknh/M5AWEHCjxsSUkvExygkETeLtY

Z/FffCS584m85aCeF6YvJLJJkdTC8wv3HakyhEcBRF5+pcqRRkY0Y24ihHMIiF4qiWnqgva0lak20l3nSl6fPEP4tEIHDiY6nDGk10nwvJ56QEF55XIZ0ni4/0mOUUX6TCOCRcWUPChk8JE6kiMnIUHLRSw9N7eJY3HhklGybPeeYw4VwgZudMlMIt0m12ZZ62zB2Rxk3xEJklGzTPbuYLzfeR+kgslTNFJaxLAohlkpJEVkx2y9PPRaFJMT5hI8

smmk9slwzbVQIzDp4tkk0l2kmp5R1IrD2YEmQjSOsm3nBsn140WT/Sc5gEonsmtkvsmF2L6rvTfJ40lStCzktsmF2J6r3TDJ4jkjMk8OYTqntHSonk+snM+eNqRPC5jRPK8lzk5nwbTJXhbVfS57k9cl+2Nx6WtDx7WMR8n7kjSYOPFyb0QD8ljkmUb8+Cx6SZbImrk0cmFk0UYqtHqYo4a67/kz8nvmSN5x3FClgUytSSzCEY1RGcn5kp8liPWK

JSzE4JSPRUm/E9gxqA1PAGudElck8S5HDAMEuVd1y0UqUkFeL667QpOrKEk1TezdyY6cfB4uE5zRfQjloxocrST4s1I14oxHFaEbqfNOB5WI4vG14koZMVLa7gPOSmJ49RGR4xSlm4ZSmsVF3FLlU3EgPIuaVdRKxsjOPqzknXHVzPtLtzTVBSZMyn6U+XjJdRyADzLHDXIhXEEU8ymRdVmHTzOHEwUvSkB4vlRn3FebHgDlI+U1xFu4jDw7zeAI

UTdvRa4pXF2U6e7YTR8r2ddAamUtylxU2KEz3JCYXlUwm+41Kl+U58HD3e2G7lN9EhU5JEgLbu5oMQDQt46i7qUnPFidWBYAXQTpVUr9A1U9vGV3aOFsdLGxXFeSmSUx0TtUjBa13EglEDKy6kDDUmBErwFdJSha7jP9hcUzLxLjK2TJ3fgmcLVhAR3RMozUvsa2eXuGQ4JsECUiDj0XDsau3LQm39Z9o23R/prUzC7qlI26RoOzBnU3Dga3a+G2

hPfpjUvNDPwhW74NG6nNUAdoSuIdoRocQnpLNoahjO+RfEym7rozG7NA3/FvXdq4GEkvrRXMq6DU+XhmXGNrsXOGnINbqm0Xd6k5E1vHqU6UhUElilKkh+qo07GnkU8Ek0EM7qQAOxxeOZWp77YBCjLBAD3dCmmPdbWq2Hc47GbO3a7rCop5wS2B1ASYBCAfQD1wZQANASUAjgYgCf7ZwB5ODsC4AQ0B6QR9Ze1cpyBnQ4wvUJojJQLmGJHA4RQE

aZiNsdIie5ZE7M3WoZrEGDYpbVCqA0K5D0mKspkHInYUHEnYVHbDZVHWg6knOo7lnWvaC9Ks7M7SraM7Wk4S9Sk7O09vZgwHg6K9bFZ9HKmn97PU6cbH5wxOPs4G9Ac4ybZOL/FVApSnKczK7dQ4OefPhX3NY58rU45kFdbYLnd3q0FcVZNsD64X1I44yrLc6X7ely7nJlx/nHalYNMdC2UvKldMX+rZXG/r3nN85MY8PqwIqEC7xRCyJhR2ExsF

BoUlQC7GVdnBQXeW4r9cW5vwiDhJoBC4hE0hr4XFhoBSRcSRcC+RUXZqkR4wmmKsUi5fmDeGUXfGlqUlelRo7zDtjLi7ZxMelbFAml70lljr0+bAZ0TeHb0zGm70jUkn9bC6ZaKoj4TNlyn0++l3UuUrT0peloXVenlMYempjOC4306ql30s4SgXX+ETRFGhv1N+mgMvuk0pK2iD0oBnL091q/0g8golDukQMdCjf0mi4oMs/CmYxBk/0s+mv4Bu

lH9FGk705BmEMzUlhk0KmgNaBmKkhTBNRfBnYMihlPUkElIMmoQ4Mr9ISUidiOeAJhcMjhmuUm0nXkxhlY0ihks417GY4iVxYMkRkakgDG1XdBGatWhnno+BG/nHumKMs1I60yHDt0KRkgM3tHxDV+lkM9hmiMnEbvVeRm8MtRmE48Rng4yRnCMnRkxUtclYUsxkGMoi4yMrhnVYfC7mM8GkKMpxlo01hmrE+hlkLPhkUMkqnuUrxm308hkakn/p

2jGxnhMj8R4M/RlhMwxkak8BroMlBiYM6JmJMmBlttfunwMl+mkMhJnOMmBnT9cBmGKH5rpMgpnJjF+Gj0n+oeMlxZXwz+k7UbRkxM2ekHwp+mBicS6BM9+l1MkhoNMpVrZjbfr1M/ShD0nBoj0xW4gXAdrFMiGivnLRJZMuBmLUXJmhM4BlNMtul84btwYM7unj0mpmsEOJl5MxZkZMh84lXF/qNMvZnV03KlhU5lybM74mHpfxlHM8pmV01hkE

Mlxmo0txk3Mnxk5UwRmEU+Jm7M25nN9VnG+uLemfMthnfM7bGtVF5n8M99ESo0EZlM15nApEMbfDLRlQssFlgMygwPmf5k7MwFnQslxDQXaeDdYF66ybAK4J9K0qlJLFmYQKMl9mM2jZ9DPoqlatGipLpmpuF6Hw0p0r0jNZIP0y6kVjfFmcjallrwjem14PsDss50rR/R1KbSX56hQddDDgugRV9flnUs4S4DjPuG6/ZYQSsplnJpRDorUjtR3R

BVlUs0DJqXDQzbTboQzTIPTZXWGmilLVlsfXfRaXOG5OYqgxTJY1mlw3VlU+eFGEYMGlx9a1mGIsuF6smqiwsooZ60jDLOsnVlmsv6kXDT1kLwfjI+s01nlwwNCk0wZb004VasAG7r3ZMZYPdCZZM06/YzLE05XHVVZuOeFK9IVUC/bXEDYAZgDbANsBeHHABzAOoBeHJJwxOTQDS0pHqy00HZ/IawxAMYf7vDLHqRnGcQiomhg2sVArInKNAl4E

2SGsOVqe5F5ZTbR6HnsMPQgKTLbm0mrblHLDZTrYFbVHb+B20ss6QAYCCO0qXrO0+nbNHNg6e06lBNbTo6lALnZ+03o64rRc4C7IQ71FEOnIgAyDh0p1CR0nHZBdL9Zz1Ofa8AXLIJ04dbWMUmiMrT5xKnS3YZ0/Q571dU4e9Fc46VS64HbTc7WHEulk04Pq31Huno0rPFMM0akFNB5k40xknzufJqEtfJkYs30kEUgCkBMWDnSM2JkI407FOsXD

m2M1BGDYkJodM2IL2shBGt0rjAfoyFmfnUjkt03hn7Myxls4qZn0I95nYcuul0Mr6gBM9GlJoYjkl44xEV0t5kukoRkAsn+lp9UTlUMj5mRSBGkCXUJGgUuCml6A1lokXSniciGkbI+67Sc+MmoU/VmQ0sHFsc4GkgjPaJU41pFY4m/wes4Yas3DAbU4oznxLMEixjJJZP9X5mEc7Vz/02C5SEF8otIt7Hs4nkIf07pnZYQzmI44/qG3csaaEZnH

GM6GqmMxT539E6mNjfZExczYh7Uw+koEgQbvnFGoyLHuEgVfK7bUjjEmMzLl5RZVktwypJj9DLkDVBhaJ3eakqadLlyMwrkuYiak7jCsoL7bLEFcirkGAou7WXEu75c6Ln1c8+J9U3dFAgqrHI1drmd3FgbN3RqlNY3rmjcvsQewpXH60ZLF1cmbk7pAqllNfSgDYpbnH0iBzpXFyEcIASrlcrbktNBKnr3RNiLc3EZJcinh73dzpRUsLFtcw7mk

+BiZFcZriRctBF9cugQBUtwarzS/qucizlJdLq4BDB6nBctzl/cwa5pdIeb79H7kk41uZ/3ZIbWUoHm/chroqTNzBqTGzmgDSHl+coPQZzbSnqseHlQ8oPTSU0GHjddHGsckLnYPFB4iUo4BiUixl2c0nmVqHikP9ALxXoXHkY80vRnQ766cUszm+c4rTLAwYFWzH5kk84Hn2VKikGzfnk08wXlB6H75vDQEZTvZnkGmPL6JVDlq+EWXm8zSz6FE

ZXlFVY16GFTnmY4vHml6fR6IUlcjZEsRli8hHmrWYGYHjDkpYcvTmlTICnxTFKmcc63nA1b8mzVLpQSuMkKilJTkNk/x6vkw/CCXBJEO8hxl+PbNp3kzDDnsdTmyc6Rznk9Dq3Ve3liciPm12Q8npPUih1WcPlcc1aqbkvJ5aIAp52M2Cnzkm0SLkgGZqc7Xk04qnxo1FeRHiXYhzItsrmc3XnA1ImrwzZ0RWoZpEEc03mrVDsnKLLsnN89HnN+O

pakLdXlj+EeYzPTeaVYtHkC81vlTPRuYlkjz7F8+zmO2LMlBUpohkTfvk3+I57JkjtSpk5fmUvSMnXPWDjr8TfnMvQMkimdCh1qffnhBD0mjyH56Tob7lj82vkx8KnqQvE4DQvH/Gj8k3m38mNgIvekwWkpKzgQiHk38lnl50btK60U8jULRegz82nnMvFUm1OYl5A0bzkt8t/kQcKl5P6GTjyk+JHV8rnkik1l5FU2QgCVOAX/8u/m8vPklJ0Nv

A4C7vn00MV7Q4VvgVEEzG4CtLTUkuV6HoPwyJct7kACtV5JMHpQ2qKO49ckbn3c/TDEk/V4Z0dB5Tc7gXXBKf4wkfAGwUXSqyM87nMCmPgOvUchOvNBh3icHlSCu7nXBT17Ikn16TlJgXLcoN76VKElhvYpYqC6bk8CpzD/Ep1S/+IEkqA1rnGC64KpvfN7GlNWnaCkwW9cUt4yJBEAhGJwUAhWt4nEjXSFoDq5GC4QUQhSmhtvbYmdvTwVBChtD

2pF7TkkoQWA1a4JjvboiTEkfzhCnujzvekyLvB/opCwkI9ONokSoXCxKMmEYi1CDiQw3RCCAtsjxI71F6M5kIXvTyBXvFFSzoujlVCs1wuNCyhPvJ/R7o1lGNC6jk8hd97t0PdQaJFtFUclRkqE4In3Uo2m6M7oWihNwnwiWEgfId3nUooYVFC05j2E5wTIfP3mVCyYXmEkViWEjxA/oeXHgssdFNCnkI54HwiJkEwk7vA4Ug0+jnMhGIEjUDGRO

JXzATC4YWnMAmgDND0yaEp4VLCrhjyE0M716G5IbC54VcMaDJNmMMghGf4WLCuMLMfEQnbUMQmfCuMLcE6NINEH15wizMJCfdfAoMOEzFoiEWZhGT70EiTA2E/dEQso4WKfaKLkE1T5JMFEXksfAnHXedqcCzoVEizYV7hHT4wkHqHA8SkWGlJAk48BMjNCdkVSfaAnYcHSpbiAlGXCkzmMi9AmgEopgH0KxwFCn0ZfC2bD/43z67RDlIAiuUUMY

T/HcsyzxYiroWAi2bADonByv423Iyin86qi58Jr8SLY18VXy8iwxbn4qsS4SK/FWis/HSCQ/FlfI2QOi93F1fclrlPfSgNChkU6i8zBb42wxwUUQhui5LlL4iQXZUN0qDC7UUmioBIbfCMXz0cqQhivOirAfTiAEvthyMRzGBC2dg2iLvH3fZvGxCkFl1scvFTCUr6llbzkHc1/qA/WnQF4rXBZC8iJQ/NPFBUEpj7czbmv9FH6zJOPGizOsXYRP

H5XVGNSjEFsXSCnQUx8KDjQUbOgSVLfi3cmwVm4+X53iSX4NobsVJubn4ysramSCqLlZikziq40iES/TXFcCuIVRRdXjisKdCdhRcVhcIXFPeHxS1cocXOC+5SQdJdjjAWvBlc1sWScenFzkL+i7EJ8XXiiAZk47egw4bZini734443NrluLbHDc/cVI4sgQikEbBiIYgnAsh6ptcf1bgXH/DgzACWxlIHE9uCwjahTMXgSj7HLoSWHfYuRioSmP

j/WB7EmyJ7FN/dTHPis7HnMFsSXY8sVUSzaLnY2iUcIQKCn8+jj7YjbEj/NiUU8BbHT/ZbF3abiXL/DchnocfAZUNZGi8mvl4C3f7DY0TyH/GVJd8v/l+tc/5rEb2QJsG/7U8ySVKS1rFP/L1id0QSW7/L/6XCEjrKY/SWW8OPjAAgviWSCiXG8zSVs8aAG70WAFFYnPmnkymLjCMQWJhTGDW4uPlp8niVpY3AHdYIih9JEqk+SjMrxYzCAwkbkT

BUz3kSxfBj0A03hRSq3mB8+bHXQ9gHKYULGp8x3kZlFKXBYtKUryJqnZ41ql8xCWSOQKdCSseTj5StvHCck0SuY+qhFQJmRBskxreM2qkGA9RgctP5gl8AUZNSwqWY8KDSzMbojaAi4VcM5qUuYowjS4d9gmA/wVDS7qV0COOLOWbTFbsLLHTNVGnDSnqU68awGZoWwHo0+gRrcK76uAl5R3MytBxxHaUuAh6T7S5inIcm3CoctQToffnipSCujJ

UjGmgkq5m8c+uJWYOhiiYk+zOyaKVCYn/iXzUuSfSljmv8qSVeA4TF/SsIE6ibZkGAmIEXoOIGwY5/lbMsjkuY6GU8YuGXJ6bEU/S6XwoyyiJsCWBlgIuZkEQxwSwY1jHpAhqX6YcZnIsyZndxBtipA4KAlS+Rgec1+HpxFjFxENjGky2pn9M7pmDMnwTUy4mV0y5pmP06qJmUbIGPUc5j0YxGLzELlmX0ii76wuGQiysbCvIcWUjw+eFH09OK0Y

0WUKy2DHdwjak5cyIa3wuoHRSBoEUY03DzEaVmbUocYEysjGkuWEjGyhrAhssyhvEGWWWyxoGUYrca2Y3OFoEfOHzxFOFWypoHMyUsQpw4u7AUBwROyo2U03SJoDc2OEjxEOXWysOXU4IOECaSsimtL2Vb2H2UuysdChXT2EGOYijByg2XkYmOWOs2iBxXUpoJXdZmdA3OWpym2Xbcs2HITCvBRy8uXOyyuVHcvK6aMtAiEEHOXeyhuWxylHxNxS

q64Se4pvLFOWdyguWyykCpl/DtSWYYWWlAsWWay+iajyyWHjynaY0YnIHqy/IFWCzq7YnAWFSYtWXyy1eWGWUHmDzP1oDyw2X5yveU0wpykN+duWDy0OXDyomFBYEmFnM/YRHyvOW+y4vATXHbC9oHJERs8mlXZSmmGHa7q3dWmnjLZ7KM0o04pst7r27M06qgIwDbABvJ6QM1bbAGJxJANgB6QL0BJOR4DlwZwAm1SoDxAKtn+nH2rQHDGDN4G5

qR/XbijWELZjMCShlZJ1RK2dI7xCZ0Kk6HoK3VJwqYnbrqjdOB4TdM2k/LC2nF7XLZFnJNYlnBdm89B2n1nZg4bspursHNna0bDnZ7srvZsndrZ87QOmnsg3rns3ADcQK9k65G9lgwEkJLYa1jKHbEQvs5fa3S+KRjfLXbrHbc4qnbY5U0w3Z0Fcppvqcw6F0nXIX7SdYQcsumbFENAHSqWBDEgqVVS8emhkqS51Udjm4M6K6N0mjmduSGmgsihn

rinbH6DBFkUMkNGD0CJUakjRlhjWJVJKgdpOcvWgOTc6Xoc/hkvUkZmAMiTlwcs4ST0+6k9MwpV4c/mWsstVCJK1eFxcmwgmLaKZosxDlKyhi4GUMWg1KrWUiXWVl6yk+neM/hnVwrgIzjDpWzUqrk4dGrnDKw6WNc7O57jVJVlKf2UBNLrlBy2ZWtxdBYQMbeDVMvpVBMpu4NUoPgbKnJVbKxTq8DCqmLy8pUkclux2wtbmJXZZVVy5yE1yvAET

K3mzHc3Canch5X0QK7mRU0tDfxOTn2XRGn6Xd5XkTT5U8MzHjyciy6zy8+5PcyZoBXfxXBXWXz/citrPpYq7M0G6qSUXMocTTynaEBFW19LTk0jFmH8wjFVR2KjldyvmF47fFWttf6nfDL1n+WDeWkqhzmFJXm5xEGPnry9FVLNJfoLWYKAV0KsrrNOFU0q0Lm0s+Up79YlXEHWCgG3C6nhc66m4qklUsq8lh1K19qnUiVVCqzFXkRIVl/tMvA9K

RaWCqwo7Cq//rZc9Rp5cobBEHTVWKqornNw5Dp0i2FXUqqVVIDUZWJYGrloqvFWWqwu6+lEjoLKVqTOyA1UP3I1UNcxsrinP3hyOWSz7yumF+tKu4dUgan6q1CqOUoa7Ay6cHjcnZVpMFyzhq9+4HysqlHKm1Bw/aLQBqi+WadcQYryeLRnEamEpdSNXtI7+YSDHJju2W+UyTRHhAq76QZUjK6XlV+WWU/+529AwboUHCZPlRGL1q3LqNq6ECweN

zofKw+7jXBtWw87tXseMZrK4KGBSPcixtzLtVVqinjuqgHkzzFZRTqodUzq/YQOUxNXOU0mJLq0HjDqiymdq2Hl5DAdV7q7dUrq5zSXNCrrlDcqQmU2iDlqqyk7qxipNdJoatdDtXZDZdVQTAnlmTfFhlqrdWVqr2ZzdVB6iUzdUw849W/qtyYM868htSG9XTqqCZnQrcR+Io4DPqitXlYqCY88qYFMUg5qDq4DU6zSIGjkeh7tSIDU/q5WYgUAR

47vPDUYagjVEU8EaIjMimHql9WYajKp8zTEYfA9DVHq8jXyPaV4Ia29Unq9VT68tziG8ydX4apDU4zBCm8aox4LXK5rI86ipmPCCl9EKCmJ+M9WUVG5rqTJ6a7xNSYhIWDRia3QgSaz0QK2C1ou85DB/kjGEUVVSaSanTUzVdsiu8gzU6TJSlgPAyY32dmhZnQJ6UfLHk2al5p2a28l1UUr4lQ+GHWa55r6MeJ7e4TqiBiXZAfiZzW+awWGPVNJ7

/SZPlD4HzX6TVzWO2RPlRa16q0qWB7mTceSe+GiiZ8lKbD41hUyUtLXewzuwLk494AzAlG5awnnLqArWrVMvl1PKclClEyZsK/LUDhOhW4XNhCMKp8wgwj9UVaprX18tyh+uPeIxarSkuavzUo2HrUMKsWiMqsYSxazvDxas7IDLb+XXZfnYxsgBV00n+UM0yZZX7M7Ys0y46Xbe/bOHCQBu7NsCLgY4B6QegC9IbiAUAYYAwAHgDKAIwDYAeJzD

ALw4G5TzYI9E9l4KlHq/0T6R+4fIRPSZtnGFIEh90XvBt4K1D3Qn1aJFNOqe2QLVNiqJbMKkNYnC25X8MWuXjsrhWTsy2nTso/I4bOdnc5VNZCKpdkUnSs6NHak5u0zdn469o47s6RW7QWRV/5f2lHs1jZKKjjYi7RSDqKqY6guJtiUGWfZibVABuQwdboFdQ7lNA0lg01Omb1b9kjFec5/stRC7HI3ZH1DuIDgEDnHHMDnOK38CQcvc6h9DxVhJ

LxWVSwJWYcylmJ9V5Va6wvoasqFXKXRy6hkglk19N66dLZFVFRNMna6q0pJXVYitTK3WAy+iohK1AyVLevpQwGpZO61vokM9G52mX2iToESY2jYJU+65l4UlAkpc8Ikpe6w/pzQsmUJLNkpP6KPXX9EPWmvBmVVMxPWHMrfqAfflWOmYhkx6lxaiq9xYm3dPWEDI6nW3epW23HBEHMkvVKq39pfGVVW2JYvVRMn27eyORZwSB7CN63ip56oS6IdA

xpYvCr6562+RaskCoOkStEOJYPVd6gy44DcspATHtQD6hsoByrrkRMufUsdaJr9U8MGRMzvXMDeqkCdXZUd6l3Wzc7rjlU1NUdiZfVD3LTo5qv+Z765PXVqx+aZKRQb4cqvVN6+KkVmV4j/SqTmducfWWDPpp04BtAZoCGWf6lwYgVT7lBUq/UT6udVeUoPWP6zfWv3AtUf3f/VQG/fV0CSDX7qv16n68iq4SYuZVdSMigG3DQZzZrrUCFoaV65K

7QGmB4EQc8DttYig4GmSp+8QFoSVLNFbMgA3zDTSrQtPeS6VDfWIGxvRs8jikuzD/UIG6/WN6FDXVpNDVBKvg1d6t/7YakXm8G4g0cGszSS8rKZqzIg3/lJ/XYUvL4kUq+JnSqQ1KGkg3yPQkb8zBz6z6xg1sa1HBUjFFRUGwiw8jVVrXIJciQG6Q38GszQfjSMZBjdg12G5zQDTNaaoIww2F2Z3nma/TWv/NA1H2ezUBPN8k56zw0BG9zXD/SKh

eaohmhG2uwRPDzWRGtqTqsnXUo2WDpIYCdBQ6vMk26s3WR8y6ppGjyBvqKJZ7E9DkrS1aqpGinBBaq7HI0nI0Q69I0FGovHeM3UYpGj9p5Gio2FGgRkeXBy7mjNzXNcEPkJG2kb+Kro1v2YPnxGh8lU453UuGiDhRicI1RPcsxoYmJVDG6Y33k2Y1Gijmr7VRY2eatZLJKn4awOYY0RG0Y3qM9JWJLL4Dgw8J6BGn3lBYOFJ5KgBlec0zXuPCzVi

fGlkcy1NxAkW40/k+40ipFlnhct4ivGvTXLTBVIyqh/qNjH40+Gv41NJFLku3NLnAmpaaePJVk6q0S5yss3m28iqbOAAZXTjRLhujS0YejOZEJ3IMhJ3cZUYmgMbs4bE0ULJrl4DaGZJQjDLzKpsqnjHpTkm7E3BqjBZuXAk3VjIk2gZbZU76wKh0mtk0xqjk20KL+UXdaNk00lbVPZVABPdU7abrW/Y7apw7s0/7L15IQCTAfAANgegDbADgAUA

HgD1wYYC9ICgBewOABJAZwC4KzQr4KuHKPIWRQ4ddVijWG95jwP7XAGFjIK0QpLx05E4rAALoRmHTI44fWlZ7CJYtFP1yKCpHWF7bhUEnXhWVHGg6grQRU07ek4E60ja5rJnYt7cM2k67g7NnA9nsnAOl/ypdl06nXIqKkZBM6wTbzQSloiCdeqSbSpAqAgxVCIRfBi0HpQznYXV67XfYpmkVYS6mxWEvQdCy6ouny61bal0jYr7nGDnN4eNgSqB

oyCiX6lEch4pjMb6gRi65jI+Ls3/ScHzMeNvB0NUdqjWdsJqyRth+xE5ljMMqpu8w6yiIOho0WNGEa/XQi/RaunzWJQi0WUdyNKkJpbmzyLFoXc2xMwcSFJZXhtYtzJEc0WwiCTOap9RbIPEDZg1I8ZSTpMRo8CA7x2fJARXqwpi3PcLCHWRMIDheFLMiFfHAW0FAj80LCnlGTi9USiJiNOHXwWsvAv4/DDxsHtw0vMZg7ZIjlw7LYHr4OwwRMAC

SSoJgTmONHhyRL4SipDC0JQLJJKgjzwFEdunsSYmRC8Lho30EmY0WtJh0WhHDQlUT59y7eh0NYi0OEUwTLxAlGxYGxaWxBEpkLZwCEyQUgzwEfwNWKeLmmzRYWEb6J0NWsikULnjJhHCiWXVvBBaOEB4UuhrUMN0omyAcBlVN0qtxfwSoDWQh0QqZoomteBpYb7GAaYeXGZZhbrgsoy2WsS0OW/SaaW3bwugsRz16KYQzm78mUkUijNYM3DZNZWF

voQxRFXAc3BWupRt4VvDhzQuV1EPxQ1Qs6Q8XHDmQCEBTKW/QQMMUCa7wATQ0ggfwzmgCjZW60gqWvK0QOcGBgoQoi7RcS4tpC1ohWhK3IJEaQkEBSiMw/1y86Si2NYNpnxW0nDhWiBzEBO3qYYEDaGW+y38tCfCr4KWxDW6EAjW3tBjW6EomWp14KSVq3QcGGRgkC5idNLhrqWgUnY+JywfWLUGfsC7C0WAS2XpPVhpcRDAc+fiIj4e6aOQMRps

Wpwlg4Ti1/AA3DXW0bAdtbOVcNZC0WEBC3ypc2RvWjprHgWFp50cC2sUFyRzwPnBlKRjBwWd62FYT60Pmv8K/m3S3O0DnxJ/NI25WFxJcNM80x0C81I8KG3BMbhIxXYT4zmnzB2dLfjeMe4l8KAm34eIm2Y2ojnjmoHDnMMWieGA3Bo2y9yQ7Om2kM7s28CZm2MA//Bs24zAc27ZLys+ayVlCWxh4MkSs26HHs23eLC2zuzvmwMTZJb6Ko26W2C2

2W20CiC3g2kC0DwKW2E2jG1y2+15bIfC0wgdt7u2bbh62oW1paQS3nWkS0q2i23q2u7AFEH8RF0X1W9Wam3o2y22BlFbR8OAioBhc2QC22m0G2wgSVMLPnsIfQSMquGQB2/W2HynPjo1cAiZiEWi62mm3R23jrmqJdB84OAxRG2iDm25O2e2hTreeFcbpYEmS2KKO152k8rVWjq1oJEu2q2wO2lIta3DWqEK9oJO0e2h23bzQ60rmv/jBcV6Semq

3jPBEbCEeAG23Wyg0XSHu07wO3yVainjQ2tKKA2u63d29bBemvu3ew/k1DLRbVCmoBWimkBXimm3aSmiBV7a9ACLgeSCLgYYBuOXED8QeuAxOcQpC07AB6QJIBuOZgB15DgBsAA03I9QM51oJWB9gQrFBiJA7jwYgJ82PsAJUSxHpHLRB9wCOLCyE3hK7QdloAUySdeeX6Wsbhm+m3wr5neZxW0mdkY622kRFe2m46is517NdlNHKM3u0lnYk6hs

4dHcnUQAfdnd7eRW97RRVcnTs665Xk4t5Bs4j7fXrXsxoqOQOqysLAs325Hr7c69lbW9H62rjT3K8rIXXp0kXWZ0sXVGHADmS648BVeB1EF0s/bNmg07gcxXWuKjs2q6v1AcI7m1M23yzpYexqaO3s0s2jR17cHm3aOrvX0NPR2TmAx1VGnDkM2ns0WOvm2NS8x1lmnR2EtRx1EUex3sjBaHHYDEXfyLKwutVx19mxUoHmmVLahB8raXc9DDm0KB

w1carXm89ghSUaz3mt67XmvrSSjS2bKihW3BubGjdsAlVjYPAH/0J17m8AWo5OtBSwMTyZ8lCcpdKE233GIllwWn62oW0tFefPbowlAGhTMZtIPWzC3JsY743i+y1NCQ5p+2s1IyWmcbsIWwIEQly0KSChTXhI9KeWnp2+2jc13lGa0r4xu3wPdkaliXS2KUBO3FxEB4qEY7DkGzPFHSyK01YUChkLXRykROarlcKTK0mLIkd2nP4Nk+2jthaHDs

Ck2QVZTMq7oNJgaQqIyVk5xgDwceTYs1sr8UTLQypWPAO0eF4lySkjmOC7CSEl8rPiASillUCiBYDehU8YExZCaDxOZa6GBYHRGQYNsgpYHSj2+TigOyPSLBDNMh0iK1oUENWCthIiGXVJ9JfoJNH8kcCaMXVxoBpUSIiYWwbaK9hIfJYajckZ7ltULXBJcBaHm2HSq44VZIfJJfTUUGtBQgLq25YijTXxNcTBaz4Yr4CyjXMUTzAvfTGQlV8TaO

14hYpWIDYMFUgEsUmj6w8zKq+NWT4YzDS7DOPTyLZYiFoep2MiLCQ3SazAm9EVLhURFhNsTJTRWVVKQ7GUiR3dFEmu3AiwE5BJc8DLALpQkiQqIq2PjL9IOun13Ous4hGZWGhXiadAImSQUeUKDrmu1f61ZGUx/MWDGXketS7DRdBwgHSSQzILzd4HT5fyAGEuee12aulhZ0OACL6wruQ7XLGzlcBCG7DOV2ekUy1K4IO37CVlhPSYNxClGjRYpd

lw5kQUygxE810KcuijYdiQDUS2jKi4V3ZYa7BiugiEusf7RICWYAzkD5IWYWdA1TCczhSu/CBseGjXNOYjLuvmzUJNhiISM5KbyLd1oaNzC7u8mrMqIVKFYDErHu/pYK1ebW/y49lLauNmAKhNnAK9bVnHZNkXHMSBpss04ubfAC9IPSCkABoCVANxyf7SYDcQEZD8QSUDbAJJzyQYYBgHZ7VbLV7WGmu1ZAKdWTqsVigg6xpwnAP+i48I2n6MRw

pdsiOjhLeOyZ1Ug6QOsGBJ4ebwZkY2SDEwnbI6l2lTstnqoOm2khmjB2LsgXZ46nB0RmnNai9Ah21bLdlxm5k4yK7o5U6w9ksbAep1rYOki7euBZm+AqaIcghqqmXzK7R5APs3h3L7GchtE/M2fszfaznH9lbHfXZWKus250sSVR5BxUPgYukK69YpB5VR1WOkFqDm99hsChhiIfGDmzmsm0LmhlUwc7G31/BFh7mhz1wtR81ToEUgvmk/BHnfx0

2Kb82I2ztrI2i5jGjFc3eOxPazOojmAWjwjoUbxgn4BxIxOjKhr4KdBSW763S4Op3qS/EjpOyzCZOzziUWwr3YMJkolej6lg2mrgQ20C10NNp0cW2ESIecp1X4Qi0terEyPWlUjtetelJiUi0X9eFlEc1r0ToLJJaQoy18OTEWrJfi1cNa22H4C60yExca9W5wHNYQEinW3wg227tgrejXAX4Vy3WW9y09e6i0TetJhaQ2aXmqfy0GkiNpje3r31

g/r3yfKq3NSBWWCcLbB0NPC2wYgi2m2g62XO6iESpD701Oor21e/eRT25pgz2+G2UWtL1wOj1jKaDQ1yxUu2t2hG0jAEL1oMdLCvmqSZxEEQQcsDMFiNDz1/orz1m6TH14sG1CHWXH26Oox1aO/VjzC6nA0e2mW2u8sxus85lHhRm29m48iLSWj0M+7hZ8uUW0SpRVzSixdWjWMPBc+u+iyuIp2a6B5ieTDn30+vpjc+uW59aFC0g+6X3C+2X2i+

6Uqnep63xfCDWUsGX30epn33ve71tekmja+rH2k+pciUSOMKG+s71a+4vCm+6miAoXPjy1aNiRs1bWCm2Nnq1emmJs0BU/u00572iAD6AURBuOQsDEAJJxzAZwDKAYYCKQXpCPAJJwV5YYCrLMXa+nVD0v22tkgVd/BClZ9ggOFmC4eipjq42wzjSfyqg65eB9SAO4YG0mrerKj3RaCJZrcaGxFmvM5F7AM1UHIM3FnGo6lnHHXce7B1O0vj2u0p

vbE63j0ieps4snVratnZM3HsoOm0OlRWqFCQ7UIfs6NFAhQgVRbDKHLhycO9Q6kudtpmqwXU67beqi6tU7i65c5SOjYFF0T3IbnOXWKOmz1K68unQctR2uUoc0ueq7BWSa/2KweazzmkmTeex/3BemPBo+8Hzhewx2s+yczHkOho/m2L09YMqVeEhtiU+tn3foOhrQ+zciw+rL0Jerx1XiHx1BIQH2de771VO8dw5e283xOwAJUW9i3W+431vmlH

1LoT81ZOrb0fAJb222t81jYRyluKAfgxxEJqLe4S27eglHQ+xr0gWqIinWgLxNOmCU/+v+loByp3/SMRoyWngPL6NmXOsS9JRkGxSxSWy07Wqoh7W7S1r0gLyDOp5CY4KS1yBzS2C2xOYTjVYQ6YR/jspTdF5oc1IisXa1aW7QPFwtb2hWweAiDOFoaBulQWWd2wrOuO36WzyBqWkwPyBswPu2UZ17IDyohUNwMMWzQMOB3y1XeqHhJkRNhcBntx

ZYZp18B92HeeRuIEKP3DkBoS2iYFgOwyTcQFWgRHpWqS3jezX2EB571AkV71fUNCxVeo21feyp3NqKWzVWxfB1KIoNIWme7GtJWzFLd+yYVBZ2bWrJUwssG2wBzL0JUX70c2K51VzSi1AB35QgBjlWvWmG0Q+4G0x8W5Io+z/13ib/3iBuGSD2j62TBmNjzI59o42/HR42sYPT2oe0rBiDgJI2/1biVz0P+//BLBuG17BowM2O4x3U+t21nBoG0E

NU4PjB3YOmXILrq6HowB4CEDbB8H3PBnn0Wmvn0u6Rp5vKheR9B/70DBipZJO6y3jyRHi9B8xightOaJOmYTJO26HQh/IMm8CC6CcaCyF2BW368ILqCkeg3eAjINpW4q3IlcX15OqX3pykeYDocF3ji8S4/m3J0lOtyAWWnkoTAXwNtw9G6khhkNU80XBKW8q25WipokhxbbFOyX2MhlRoraUKoYYf9C0hxG30h4UNchoBLuByG1d0upRi+wUMS+

0y0ihgRpDe6UgX9bcFcYDkOyhlNg5Bx71jYFUP8MNUPEhcHhA+mr3hYQwNfnYgM4h7Z5fNU9wNeqC0gUO1n2hnNKOh+g1ABnnB0B6ijp+YL2K2yhIsZb0Nle0gOVe9G4ehpW14h2fVYBuJ1qyLK4Qh1ZJQhjHSYB7oG5elogJhn4pJhlJ0ohrjDEBjJ1SoCMOu6nMPIh1MN6hj5C+hggz+h7MOIhyEPZeFynVe3622h1BGlhlMONh0oMVOhSpCB2

VxRh4MMxh9C34B3IMmh5Ep9h3ENnSCTySB4b0yB00Myh9UNyhiQPKBoBhDOtQPklF0NO20Eo9cab16By+gGBsoJWh5sM2kKZ3ih7KhbwMp2Y4LsOEWxS1lWsO0iMfkOhcjC3U6dmpZCHS3OByYSuB9X2SLIHjPh2R2QiA71jO1kNFfSQNNdSHaLbdVVIkdhChBmkOOuZQMkyUFh4zWGSkepi1RWw52O2ueB94ROTxYSKxIRyq4HOxIP/9aEoQ4BV

Aj4Z2TpB1K1FWswhe28S29OjIKQ+V1gFB9EO1BvNyWB5q0AQ1EPVBx2hR0dOIh2lKa3h76KVBl72MRriMNlHwhkEG3L0MgSMMRmoPCRrsqWWzOhq4l7SSRtEPSRzENtUuSNOvfSwZGfK3kRiVTEh0cpjMcsTisQcQn8ikNxBq5AJBmK11UhPajEFsS9aYIOQR6kPiYAiEQRwyOyIuyOXjfwQARuVFshsbkF2wfg5yboSvhnkouBie37CHCOF2gKN

FgobClW0O19UVS3525qakiSKO3xbp0nh+A7OR3AhtOJKOMCKKNCYBUPY4JUMsW0cp+R7KPF2ki5ah6QO2URu6ZRqMk4TMqOENDX3Ghhka+RxKN1RwKNgeBX21OkH3zlVqNF29qMVh8zy9aqig2KHqNZRtqO5RwYhhhpZRfm0aO1RvqMTRrZlxhvL1ZhhKNjR+aNfSoJ2RVbeCJhX5I1RiKM5Rr6XnoVc2l4dc36w8KP+Rg6MReiAP/+qAOrRuaPJ

RraVkRvZC4qB+SHU6e4V26GGdW/s3vR9q2fRuq1XRv/1Q8W6Pl236O1W59j4UxL1IB5L2Lw+u2zWxZ3u2Um104LaNKZHyOY8C50ghrQwSpRdxLRzMMtiWDzt2/720WagOVhoaOcUEaPseO4Oz2jqNJQLqM2hxBLm2kgLQiHwiC0TsNde7/DxSHAgRLHtxd0eDgcJK33Dh5qOY8WqrmUJMy8x8qMkW7UMzh7LpY+zAxpNTTYkXJcNLY2nCku6WN4s

WWNdLNTFyBxUMOEZUPZdUayH/EtBBaFKM8W2b17hkoZbOgLAYCTfKihiWxpRyUO/qLpK00D4Cr4DvC2yxq19W4Ow2BxvTMSIzDYcOb4tLHq1Aadb3WB9SrMMSiZFKWQgLhwOMvoYOM9uEyq/FPW6Au6hpuxliOk4cVgFeBKh4KOkRRuLcOpRpXAShs8OG6BuK+ED/CV0Ji1xeE2P6Bn14Zx8VhiqMuOJhfTwMW7WPMWtcYW/EuPZx8uNKBuUxKxx

8VHOtuNZxt4g5xwcN9erJIjhyinDSAShcrWzxw/T72Xh9mNiGk9BzeKeMmXZ0NAWjcOpQYrTxyeES9EQxhJMmL1Vh4aMMB1Axbx3Ch1oBxhL6nGN3mrrrPIUhqnhtl4IB5a1rm3x1DeGFG9QtJoQPMJLgBwGPHWhhkHGcDw3m+MMfx+xAZVUy0c0HHh0qBPGRe5x1A+IYQFQcwhum1RFfx2x1OOsQ2ouwKDekgTA+4j3nhOu/2jmuSYhUZTQlKa6

oJSw4MjmxD46alajGXGONjYS3mkJyJ3kJgnzdfNbKoDOr03+5z1HB+/3HTLw3eVERSUSS2isJsx3XRlBOuPHhNDwPhMUELwnM+TGDFKL4zLW9fFIJ64MABpo0f4I2CPMLAkluTaNHm9tCox0o0LQorg72dRNphky3YBlaNnknozivB53wEr840Bg+Nkxo+Od2Usyd4C9jQgSdD0UTW3sBtCiDuwrV/hCVx0u8ZyIeTqPA+umOe+Roi60EkL0ulgi

zxtmPLaKOzWJQUw0sQugtcwJj8xpqPdapMkJW6EBOhwb0SxyqOYwIvxlSkbCZJ+g0DO5cOqBzOrsUFUjmIroNryrWMFRnWNFRwuzsugjRvkD1gmy3QO8W1ZLzYXvz7uvbjZeHDUVxmRqmx6uMfO8xhfO9d0NEOLxih/OOnh+ZlFkz51ruzNATJ2ampxz2MbPEVgiu6d2aEEaRxW2OPpxy57UqUmiJQB4T4u2Pjux3ZNexu/m9uqOh1So/0pxoONW

BuOOPPbwXfUSKhuQE0GWNFZMhx2AKI4AKNFRAqBpqnZMPJvZMqubN3FoF9SR8XYmnJz5OPJjgKk0XnBdKIJCQp6ONNWtONUDZe1Rs1e3u++Nme+j91JszbW27bbW72mU0SAL0BeHVUAKmwsBGAE2qYAZwBegAPZQ9aD3lwKIDP2mtkEKv5DCse52YxthiMFHP3Yu/VjqGaiTxnPHJTOn203YPp25HTE4+h0mP0B1Ar1+/00FnQM3W04M0knTj3t+

5dkiKijY1naM2tHWM3EOsnUd7MT2snCT1JmmnXSe9jbpmkXbyQBT0jbW6ADUeThqoJf2x0pfZCIPET7FRNgVmkR1VmrOn/snOmzFMohUo3U60OpxWtmlxXtmlXWBe5n1QJmn0j47elRp+o1xp5i50JhhhaGSBNCJkx2mXXn20WNdBYiHUqQxp+MoB0VxthhsMkJxAP5plL1YhscNeho3F5pk6PPxx2zShoUOmWkjC5p0tO1pgtMqudxOuh0C2BO0

ayHmkJ07R88PG2hSoVB2kqaJ/tO1w2/rbeygOpB/MqXxnAMwRwFBwRpgQJ8fAZzp0xNKqp20YRyaJtGtYPphkxN4xgiNulIiMH6WAyzpvdPxhg9M+3b20SWrpT3oqaMVemMXd669M0Ru9M2J6VM1h//rPpmZ2vpkmM0UQ+MxUdFOu+zFPLa9e1imjbUSmhw5Sm647oAJIB5OE2r1wfAAjIYYBJOUgCVAfiDlwNxzAe7ACYAIZB6QPVYspgM61s5r

DXERr4rUXu6urH+0UsP9A6JA8Kf3Iv145LK2xRiq0C6qj2PEcxNXxIWK5nAvaIOhv0Kppv1Kplv3zs1VNhmiRVUnSM0Cevv1d+gf27sinXiennaUOts7UOjs5nskXa4Aa1PS7aY5IqCWhOpx9mKjYs0AwUmaWceH2b+3Q5znMR27+iR2+pqXV+GRwon+hR2mZ0NN2e8NMyuXpm7knBMcJvBMXnfH19p7aMTppukDR2gPVh8mMMc8mgHh4r2gNcWP

JB5b1ca3pVxp68NMZvkNQMln3IJ9NNBRvS3vhkWiJp9hNkJk4OxB/Z0WR/WGeOkQI5Z5HyLBp4PLBjNNzmvgSv+on2Lqu304+k3C1h7c2424CgJSJrCroaWFhKVt2i1bEOehkMM9qNuNg2vIQ6IKUP6h+cMZTGFFHJhFNNCNcNrxpr062oR4TxwcTf1enB8lQJPWhxC3WiWBOpJYH6DpsoPDp8wN0RFFG92BvhfoQAJGhyb39BV8iXkNl6URdtCO

uKdPMB16gciBthMCImIuUW71SfRp1RB3gPiBqMQz1Vxq5lc9ifZ7CLuBwIP7W3nylxvxiSoRbAIdQiODwE9OgSwYi3O7ehTCTjNURyVg3p8VMeBdjNo52RLMR+5OsRoFGfhXHPL9RnCVuHkN8Ryq0k59sIcZ/HNEDSnNxR6nMHkFHOkUtzzVXe93O+x92XdGs0vuj32rar31b2407gKtmntICoAgHeSAzAAyCVAE2pDAEZDcQSuCSAf7bOAEHK/H

AjNGmvoDDOKDh1WKiqHIG5DkK3DB9wWyqN2unL0ZmTbfZuS1RED4zumsGAykhu1tBhB2lHOuose0vazs9B3Y6kTPCe+/JapwT0aphrYkOg1OyZo1PyZ/g4KKms3j+lTO8nStnT+uooR0xoqyIjS7KHYzOynQxW2CTcjx0oR1b+pTZGe6s3Hs6xVmegkRNmxxXWekNPKOsNMiclzP6M/x3s+6/1XBqn01586VlPSc1EYYLhZZ4rP0J3LMgUo6NJe0

6O/Bzz2v+g/C1ksdOTnMox95gn0D5wXDYx89PLRy9MIh5rObBgDhEBnowOh/rO9hp82he9H0xB0r1jZi0Nr51H1zB2ajiBtgNdpuXhYhmgPDBvhg0GamMvEIJMv400PABy/Ocq2C0CBg7PtB7fMiUEdaP5qVj3euRwdO3irOC4/PrxqIjDx9p2ASPhxM3TtNAFuhHn0iqNkWt4jVtGL0X5oPhX5zUM5JuAujes/Mf5v82gBkAu/5sAs3Ye/NIFnA

tgeF/PdegUNI2kYMoF2TCQF+bMNJyMPr5r/2H5qkQNp80OlO0cMMFg/MY+1sPT53GMJO8EOPYPz2Xmh+PHR5APlp/gvz5/z1UEsfMv+rJiT5xBPJZ64NRe6QvVZ2QsnJp/1VZ8m3G4RebfKpNOcJhVH7x99PBZnQvZZjvPI+ZwDIWzGCfmSO5t5iJ3HBswtRJ9APNqGwu4Jtz1NJC7PnexBJFZ2wt6F/42PZlIPPZ5wseZ1wv9Oi3OKYMQNhO3Qt

4J8NJNxupMtx5QuaFsbhqF2pOhpOIuFpgQs7mrYNgm/KMpF9EN752YNhe8QPGBmIs5F3WP1p8/Of55AtP5ootLQ2Iu5Fwfrrhpr3AFrIvFFpi11F5dqkFn73apUIvRBk42CElJOjxzllnW6dMBF6VXcBn7NW5yW1dFvwvRZqZoiB8YszhZ5FfpdwuwiBdOyWsIsLFo9LLFq0hO+yJDc5t30gZ990b2z91vZZmkEp391QZ1VaLAOvKTAQgCWwNsBQ

AEZBJOE2ptgEI72begDxOE2pzAfrZJ+mWmEZtlPoUCLj5EW+jZiA3OuGFlS+WS6o8uIVPTHdrMdPYmSEVG3MEhnSPO6bOpyplHU8K/jNse5VMCK4TOEbUTO4OwnW9+8RVe51uqNnGTNkOynUh5rBBUO8PNpm4erdnJkDqZ+Q6xbLbBhytT0YwZIop5ubZqEmdCCOr9mepnf2qbff31mrRabkIvNWels3DFWz0h9CvOeMzK1eFlwud5zhkKJ+vPAx

yi1bmv0q5h8sMOOtNPCyX+ODB3rPRh9RKpp7+N6lqS10hxtMWhk0spZs0vQBmgscB6AvAJ3C1hZpX3Lm1tOiFgr0ulumMaJ3tPBO3zM6JkG0OF8oOHZxaM8Fq+OoBi8PRJkdP5h5fN9ZiWg4WkoMdFjAMDRucO75r62sxxwshloMuv5iMtDpq8MNRkmZ4FmZjgFwH3rZw8MKx7uPlW3uOllmmO35v63cWo9MI56dDMTEFqAFxouOlp9PUR79OABl

gtkhjUMfJwnOk4Tb1cNQMMr5+MttSGKO8RpnP3h9UuCNTUtlhlylrpISSrJGhqQYEm2Zp8W1LNJJqUh670YYEHPyljcuLvCQURW5CN4RyyMhNJz3t5uwvMyHCPxB6K18c0yP5Z+8t+O3UtRek8u4RgrOBFkc0ppx8unlz8uRtZ/0qFrQv7yW8vmR58tpFiQt3gxYuBwmqN3l1CPsF/fMFFm8uwVsCvwVsouqhvstRxiCNUhpKPjS2cOWl8kN/hyy

3J/VcstzcIL2loIwE47kM3h6csa2hova2qivU4QFNE59Pxtlhiu5x+HMdqZsusViiubhxuM1Fkot0FroJelzbPZJlF65JjAsNBESvxSDr2RlzMtv5pzDSV6NNsVyisDhJsOoWmSvWJjCuch9PzqV0eTRpjUuxOmfN8F0PX0V1Ss+loqB+llGM8Vsyt8Vt0uPxttNiF2uy9lnSvCFnvN1pzAtmhzCsbR30vIx7RMBhlysGhqfPGJi9MmV8iu2V7tN

2h2MtGlzF31FubPsV1eOQW9eOn5qStlljSvRp7MtkF9otyV4MvcsH/NGE4ssEFuW5Jl6MsMYPboqB5WN+LfoseF/iskRwSsDhOYuW53/ziBkVNY5pyvu4sHP2B20K4aycs5Wu8NpabcNLW9Nq0R8hax2vuz/CVjAY56Z1ipkatLlw72kVs/5nJh5NsR7y4hBxyOBWoamrO+O14U+yM4VgK37l/rmeRnwOqVNo2XehyO4Vjav6RtO2lySyuCuikN+

WqCN4Vu6Mw4AV7A8bCM7lx6uXV5cEpWsTC94aNSo8mCsPV9asHV6tXgwc+5WoYEjIVoGsXVkGsmI2GOtBkDa7V3ctPVk8rzOja2I1jyPLlty1rluZ0tB9GtN2zGvzV0MwtzQDMLaqml857FMC53FPe+rbXnFolNi5iQBDIS2AcAfAAm1L0CWweuBzASUBDIUgAV5RU34AR4DTgeSDt+rza/FjXMQALuARYMzw/yW4ywSjYA/2sEvS+CEsgOZDZds

9GOwhrlPT8jPZ5HRwQExzGNExxj1+m9EuN+lB3o69j0qpj3N4lkkuapsRWIrP3OcHAPM+0hM0UO0PM0lsf10lolYMlr2mfQGf1x5ula58T1zs6vtbdwGU7Op1VBGR9vBFmzPMOZ0R2/sizNUwUz1+pnWMWe+R3F5yUtrFC/1uK91ydmlUu9mt8uP+wc07Yd1JFtT4MF1xGNi2/Hg5px/0alpEPth4AkGlytP9Zq6OCJfajr8VvMjlw0v9hicNuVq

GO95juuN1gcP7m3ytaJgdMd1nfOEV1BkD19RI9l8ev9l9/NeVnSt2liKsLZrRLL1oSutl3iuRV/gM5VnMtcNFSt2V2hIYWosudOsRr71retlVxWNVl1cN71zesr1nQOcV4iNQgJevxV8ys2xzHMvpmevaVoKt+NRnPMZploWl1gtz1u/hjV79b44Sav916Ktd1rJNEVrGtHenGsDm8ut8+nRWAJGCtmRlCP4R+m251ycz514tIpWoN26RyiOuZ3m

wfRsGPJxF8umlhvO82NGtzWra3w0wCsJFwfPTWvGs0NhSs1Ed835FzfMLB9WtHW+WSjZrAvI20YPlXPWvHW2bjLtNKuulytDcNq50nWz8Mjxri7Vo3Wt/e/WuiNr7PTFqgNCNpRsiN676dVhQMhl5oPrWlhuBlRa2FJR+MCqtq15E0hviupNzjWpJiTWgajaR/Bs7SDK0TYi1rhMA5N/8AOOgV9Bvnlhrm/1xLNMhoms2WkSNvhzMT2DI8Y+EUBt

wy1hvhNkJsgGO5Mxx5aszeTauxNzyADJnj5cVkiPBN4KPvh+wbbh49PcVnYvRwAU3AZ193CmzWrU1oXNgKkzai5qJyurXEA8ATQBenSQDMAHgB1AeuAjgXEBqyPJxewIZCIQdXPaFFCjC0JgSwkTUqnLBWulUGhH9NAgHQllfKBV8bM255RxBaROP0uyeKG1njPyp5B1o6oFZoOjj2W1hg66p0RX4OyTOrs7dnxmof0tnanVSe/FbKZ5RUi7QFYf

wX2ssO0U5qoUWYC6qU5MKrks4FMt5K7aOsGe2Os5571N7+yR0ilr4qoQcUtHbdOvX1cvNX+iNOyl30nD56yvkNm0uUN0r0Fh8r2XVFCDtMrBtAxmC2ZV021ItxRPfoEAtG+sePGFq8s+F+i0CV1oulFslveFqItv1usobae2PZ9SIvBF6KM8RvqvxRuht/BrNMAh7cvQ1/avaXQ8v8+wEN0RqoOFBmSMl9ItOpOmEM8N651NZ+ct115u0y24m0IV

oMO4h40vE+tsj2+8n1qtscuatwX2c+vpjHYPfPqtpFhtkc8zKBJbQdKJ5ANkuZtWlwlQfQzrMGwbrOTG+1sT1h6GrBVoPkmbBj4VwBsLhxZv/OjGwrN4+GeV1Msetwwhhx9IgRxihgBVqesWth65Rt71uRxuNuQNjVsJtiGJOttqhdZk67StvMPKTCWjeyN52iEBVu114tPK+8siSyE1sQVxVvltrVvY+sn0W+sfMV1kVvkyRH2qt7lvWsf4Nblr

4M3WirPNt7tvHljRsYx6ATwh3i7CtvltKRjiMYh4oPjtnlublodu4N5BiFWghvON8VkTtntu/lj8vgVztsyCBdsC+vLN/lnduzah93FN8mtr2w4tgZr934pne01NvOCkATkC4gLw7tgNU2bQbAAamvSD/HHgBDISoDu1H4vVsv4vGm0FymSBlU9KEmZ0Z3D2mSBWhyMWkiPMdI6NV9YstOm3N4t5MveFbjNO52+Au5ok78K1v2hmq2tEOw5sSZ4k

sEdxk6O18tbB5vg7UlxTO0lmh2R5hkt1AJkuaK+mRlZU3bvNzkth1z3oSuEwoep8xVmZuOtCl4Ftme0Vj2K1OsSls/2l56UtQc3xW1560uKF6BP+Z7BM1pj0sEtqn04NxTvul6GMqdvOvpYHtOWVvyv1vL8umFgdKIxnzPHmoVsaFwn1I5hXEIt0J3xFyzvNItdOz58QvnmhfMBe8MqOdsKurVdhvPmzhtXlDzv9tToMZe1iQ9Blmpot8MOPpuHW

wTRoNQjMLvTRsgPFVnev5l6NGxdh9OW+xqOXZgWopdosOPppgP+Fy62Zd8xPotmaOjFyINNVpDuhdwrvhd2uQIdnov6F2ev7QkrtrF2rv5DNesNV7ou/Z5tJ6V4JONd0QPNVz4a319esNOtRszp3YYDdtrvDd57OFOr+vjZg27pdmqss1eru6VjMu5VqbsL1g0N7ZueOodhYVZd4rtiNn65PpOeCGCwMOFh3bvucujwNBw7vec/zuzZ9L0FsYLvw

+0yk2dgzvkFh/Nf4DkJsJhyvKdhCscN+YOYlbFvppvIs+d37vo03z0ZFxfO/+m0tKFgCsWdmrNWduvPadifWIxmQvAVgGOQ9+Tsk0ubVnt3nMXtnFNHFvFMQZ1NkXFs05h+zABP7BACKQJIAWATSDcQfADcQRcC3atU39Af9tvawM5XITgxhkSQELGA3MMUezKJyVj7GZrtkykkdx60LyDk9HWu9V3kP9Vx3P4nPjOm17Zvm1nEt7N+o4HNm2tHN

4jv9+vVNnNw1PD+y5ucnG5v063k6AQGPMT1Wf2jbHbAYCHTMc6ntafNonq+4Us08dpR1ep8R0J14UtCd3Pjgt3TYx1yTvK6uFsxpqvOvlnTvX+y8t0ttlufxhQuqd9Hsi2mHu4RKzvB9xUtcJ5zsbBi/G3peysh9udCEFiouDoHPXXduKtJV2gtejHbvxdjtOtd4mODRv9N+SGctSVkqshl6H3Qd5gSJYKqtzdgb1/08RuHILvU1djruyVvMv4tz

9PiYWxs8sik2oFqLO22gnMJNlisVlprsddrJvpZ9Z3WebIvUtwbuMif8PHV4pjVEZIsL9+4o4Rl6t1oN6tpNncN8W6eiadRTIP+f6sRMbcMdJ6NCH9kGPFcA/AJYc2yTJ22PTJ9KPvuK15VkEXsu+ZZNUKXcQqiWrJrW4Xsn2UXvxZqct/1l/swd/jgADj/uTKvxv9Vwpu2OLHvPunHtU1vHs01s4u++4lOe1E2oX2pJxQAOYD8nJP2dAboAo9Af

hssfjjYwBTCm7GHapQWGgm7cJgCs0oBdsiwhUgtziYxEpLpnV5ZbidZMv/YshnSaXtIOrHXU7PhUFbRXsCD/Zv4l7v0+545tFrb2tkl0h3kOuRWu16jvu12ju3N3k4bLRh2SHZh0aKxopJ1JKAp0qU4D8cc5UQfhzCBLVB6esxWO9wUs7HV3vaIbNvxTQNOgc8TvDFLEC7gb8AVAP8BxII3tX5GT3oAeCDDAO47KwdSA7gaCAIAOoDDABAAR4I8C

aABIDEQK1B4ok3gIQbYDR5nUCUQKTtNUeViRIFiD2gJYp2HKpus0q7Z++xwCLgL7bKABAA+nZD2WQAgclD7QqBUMdJ0evM2IWRI7jyMgmjcaCjvJpE6+rDGwiYAiq4eECSL5Ag4KmElA0kTQ64orjOobdZvG13Du4l5v04doTNK94RUq96s621ijb2172nkdnXuSevXveDujtVFQgCMdxoqV0Y2Q6QeY66ep3Icdi3o/Y0tp8l/T2Vmywcme6wdW

obd5QED3tWHRwccFZwdfgH8DuD22BbObwcQASYDA9M4B1ACCANAbADYASnsIAM4AIAPgaeIDLBvQXAB06DtCQQJoDkQFIc+96nCOIdIfXATIdsQPU45Dn31/uv30iAQgBc0vSBsAZ2lebSofAnIM7hcYEhUKdChmlK03+QDhDSCJ9iWxmDgL7M3M2gEfIRVTeCPyRyALNjOi8u6UisYE4y8D3jOzDkQcCZmYf8DgjaiD62uLDtXt21hYcO1/VNO1

85uJmhTOj+2nXKDg3sMlqWnG9zQfM6sGCfIDMQJxeY6Ah/TMIwVehNQh3sK6p3vx1pc6Cd7RBaSLdjPDuPIl5pwefgVwcSAL4fxIH4eEIDABwQTQBFoOoDYQPCBc05YCaAJCBNAPjDYATQDDAbADEAHsDA9TQDEAMEcwQMsAojggBUQX1BpDiNnYj7IenF29v5D9AcQAEZAX2yUBwAbYCEAZ06SAZQCSgRSCSASUD1wbDOSgSQCkrZntoewM7fAS

UiKUD5jdYZIonIW6hU8EVnEdPJ7pHPqSIOQGheqZDZUelFRmSSCzuJQg1VgNEvMe1HWses2vYlyYdzDrB0rsqQfiD2OqSD+rYqjrXtB59Ycmpq5uvOHUcWp3k76APYeaIBwpIiy3vB10wenDnnXDrEeAoefRW/Nm4fmZgTtWZ7yAx0aBtUuSz0Qt14dQtpzO+9lhm7k2DFGS2fFvIZYaXUGYQCYDPghI0y6wT5HDwT4tClJCZsvVknJbve4rUyuC

dvJbCdNJa11KCuGI7wUKM9Z0pRJ6cGZokN27fpcYRNXHeD95UNuUvJCfthKILtoFynEZWt4pFzciwkLvW4T0/qsj+E5sVAEj9ocnRLYL3QG3UFCiThOLiTnrKfqIuv44arCCx2ULMiMFgKoPCVLOr0qvMfxSQEFmb2J5LnIUCt1b8eZr/CxYjxiB7AsZfUug54VRIbCydHAf4X8UGRFgAwtBccYjhmTgljOT7ggfJWkwkyhOI6Na0o+TpyfAA/yf

k1CWQ9KKKjLqDrh3YRycUC76iRT9RkPFN1iQ7amKcwhKfsqJKeWTrFL8UFrDNyZsqBghyc5T1sTJTzMHawI3jgEOiEpQQyGv9MKe5TlydYpe/DKCHSogbKxsdVxKflTvKckpACh2+d9iDwVNDZT8ycRTyqfmF9UJuO8O2F0dPzMqMqd+T8ae/0F1SXYFkheMHpWENeSeiYMSeGxElIMo2XYS0KEKdTzSebTj4CKTnadmpEOTf4PrRnKIsjklMbyt

6ULFngHCfWEFBiDiUWaXFO6ct4B6cryJ6fapBOhoAhzgYQGVKfTutA5yR6e8T8sA8Ma8hNaK6iyuWicTCeid4iOFL0KKIQwKbgx0MVhteyJDZUujXGsUb1IY4cqRf4VxRb0PlwYTn/4kTrgHawTSIHHZOLjbPJORtMmeq+CmccpKThHGSSjtobojBNeVmMz4iihIUidmpcLhm4HG3kfHwikzyVCYT5mfJpUgFZUYYdDoC84om6hgYiVajTMTHBJ9

K1numa0gcNKrzIYEm08zrCeUzltJnYdXzduJxL2kXWfiz8md8zg2dW8NyVzkeSQ/rHsvLHK/BEUJTJSZOPhBRRVwv+R9PgW+6dgzleQesK1moEKtH2zxGI9ek6c6T+ogjVltJBzsbBuUL2diNOaejTl5OBz22eezyS5iNcidcujGcrllOcezuOfpzkq3dkfojwq83iasmOd2zxKKhzrhpxxbQR+JaGC5sXic2zvOchz72eOCckSgWvApJWw2do2F

AqTuA0gzm5lQNMTZhaUtBjqzrZBbsJ9jaznxVGBjLRA0N9SUEUJvJpRWcFqS8guYaif7B5Rzoi6SfHGi+F5pGIEz7GcjhWWy2hEPXAkeO8Q7PZtIAbOWiAE8TDezp00dOshgK4KzABw81L/UCaRVdXkubmmj2SsVrD5ENwFgmgmcKYDNqyW781uTtwoX6YpJrJFGfOiCVzozj/iAB8uinkZPjngOVQKpetLwkEoQtq11tGBkGpILpxJOvBaRuFyc

i+/eCQxiC4Pk1QKe+8PbS1oHCcAUbaOJ7G6SABuDa6uHRCV0Of5mpDaQz8GTgmzYFpBe6KcSqUcgi0IBNVTyZhP6EKI+OwGiAB/hfvsvag48y90MCFhd86rmcgtGcFMLARcOMORf7lb+eKyfPRh4aANpT3b3zFdh1OZFfBvCCAiKT6K36LsYBM1bYTURL+ThpbqfOT7thWLi/RxYIxf2L6ul6z5mcuLmxfvBqidzKoufCBfFUHEHxeGLuxc4ExdU

5yRoYLz2MShLtxfhLj8QGT7tycuYy6jEOJe2LljAeLpOYSoKCRKL1huDAaRcrToRcRMaqc0aShJgdo6cg21RcGwGRfFLhrgkDZ0TinXdD/1wpeCLpOiTsWybvYfnifIJhcKL3JdPSJ4dcMYheJRD5jocTio4cifQ5LnN0DL9hdqiqGcX6YLihWXAOTLvFrduGZcRMcxQYigiCvEctD5LlZeKL9ZcxYHtAFEKSgB3FJi9LqZdrLthdn95ed/8DUzm

iZZfML/pfXL22WRCUEjNYbVv1W6pemENpeaL6KN4lFkhCiV9DYLqKc2iH5caL4RcrCfWNmULTjr/dJd+L4xevYY+BbscVDmqPnC2W8/S+L9xcRLkK5fVNPwtiAIhctTFdhLzJc4rp8YWYafosi7kXQBgqeuhKMjBa9VW0BWjAYEJoTtYGlf94rZIUMcgTo4Yi1uEKd5BUMC0eUNYgFcFjI2oBmwi8fPRf4cMgXJ1YNCrvVHLEQUhir7PDpQ+GI7Y

c3j5LuVf/aBVez3feT+1QvCbwZBJVXaAOFMeVd9gHVdc4TMq9zgo3CBB+Wyrk1dars1eQWLnBoCcm629ToKtl+1cirxVcBxuUIIBUYikU2y44czVder81d4OM8TxsHwjPEHTiCrz1c1cUVc+rxjD3McQUDwU+uxr7VdOrvByJrthjJrx33hszHsr289tYpt9249q9snF79201tAcM19AAfCGvJewKACSgcxgV5BoD6ASoDlwZgD2bNsBsQTscp+t

lMStaKTliQaOGrkLaFkW/E1LLBwso9odg6yhe+8MbCs6xEsr4ZmBBLpZr8UlcfodmXubNjcfy9rccSj2UfK9sQf7OFg76IGM37rzXuies8cXNjYftnLYcqDhksA7dQePNrQcPjtlTC6Th0PAUnI29nM1D0bGCKna4cClv8dWDp0exD9IFww+wen+r3uZ1+z2V5hTseO2DEKuKASRVMWcf8S2eGtKKWwb0Qjwb1Fno3eGc4zkfyob83job3cqYb/z

nhzsSfvsAWpOzxxEskDxAjT3yfAAncmsoijczkKjc/AStx7KQMhiIN9SIT32fcT9gnXuUuQRQMFDNcKcqjd7jcFEHid3RQecYQZKD1GMwsiTracJxPApHO0xcn4duidhSSpuFrScKT6MLtV0vTWULGz14SKhwNaNPGB4VQZiA3E56DHzFOkwyJsYIwOL1keTRempFgVJ6ZQgroaYH8xKs8W2BSpDe4eIvymWmdcFEac6UmwJd2mo9waTuvmoHfze

XXAdILrr4whbl9TNR0mtPuyJAU14tdID0tecFcteoDgkeljpJzmAAyDSgPSBQAYvJeHHptJOPSBuOEcBGANgANAMoeCnF7Vi1lHqEYLMLtT1whuYKE7+QXCSXUdwbhYQfTpHfkjLZuEjloTOPIdyafpoKd7g+d7RrNjDvQoDEty9svbbrmUdknXcf219dmJFI9c6pk9eklsju+0l2tUdrUdmpoXY9bBktP2g0dLFTRXFoJHgXyeY7IbD9e8AIZ1+

hJba/r3juGe1U7/jw+qATxMqk5OzNp18Cc7naFvSd2Fswt0hFeLq2fp+MBpmiQFBMbnAbRNoicSz0HdvmxjctEaHeIb4ifw7jzyOL4AHx3WHfIbhCdTxZsxLr0LdNas0R0To6xIznOz8bkKjm+wdAEq7Dc+lDxB4zi6TrKwGh1YHQhwzlCAIz0ncM795pvCU6hVeFrDha+tO07xGdc7q4iiNALC7sNjR2toXec7t25G6GyfGRpROC79nc4bhiduh

PzeR8ALe7YrzvS73Gey7p5fTL65ds77Gd071XfHoAxfxLzJe8LinjY7pmdo7sKhprx1c7NBmcWz23cobtXg1T8Rf1hB4PJBMzyXIwujaDGelK0fqciKaD7jmb3c/0e2gOEAvGAUWdDmzpDeu73Hd20Q3Ak8Gcex76uc273mdu7pWijbxpfsJHvgINkHdZ78pg57r+R57wd2JbnnMIDotdlNtbX497e2QZ+mu1NuYCLgAvJGASUCqgBoDyQOoDKAc

D0m1OvKqgcuDxAeSAGQUkDdr1lNAdpXLqcK2gjETDDQ0RkfwpPf5QEKMloJJnkzN8Ycw6ynqcT76fibsUcbNgIqKprEuCZxbeYOjv17j48erbiBBHjjg6rDnbfyDvbemp65vXr3UdVFLtf3r2PNPNlhCPMZaffvdkt/IQwcybZtQEKDPP8l57f/N17cAbgCcfCYshc6kCeidsCfgblR3OZuUvcc2kpobhVCEbh8vRoxHe+WW5CsNgTn9b0Gc8b6p

IhZqYZb7v2fib2AcXZAtfY96vegZze3gZ+veE9xvd5wIwC4AXECSgIwAgHIwBuOL2AxOfQBJObiBFb3AAtji7X9N7sezoMySShnPTPIijP2QHXDVOTMR/SLAQ6nZE77L55clMkbd1/MbdNLyberrsYfTbv5azbrZvzbo/foAWo5ce9VPKji/d45dbd0nTbekd1UdrDi9cXjzYfmp+ktVFcI6nbvU5MdwhjnlZ8eVIUmWWj+aB7qCBg/r8wd2j24c

1m/PPOjjASMFb7didhA//bqumA7y3gZ7/Wc4y0TfgztVmF7xPfKeRqc9TyiJY7nI/8znQOeb+V6sUHzfO7+PeZ73I8t2CncoeITfks+GnFHymdtzsHAdzmMQTyqo+o7ovdhqpnfDz/LoEQtI+SzqSZRL+eehmWZgo7uHe9Hs/DKb/1J87vbieFlo/CAlSdnz8nT+JZo8u7mo8lHs/C0mECTi73RCOcKY847nY/skFCTJLy2R2K448J704+sEbRfW

b/IjjL4FXLHx4yxqaLgX6a4/bHymcziPNg7S9zBgIz4/pH14++YGFKX0bS4vHyaZWb3+fjaQE8jH8gIPzlJetypY9bHoE+ZRMXdY2Q48atbmconuE+A3U+cU+dY8dJTY/VH1E8gYSScBNEzAPeQrMQnyJdzz7T3emEzy8XGk99HoefLlQY9G7kne672GQ30do8DwPAoJyDk8c7rk947xddxb0ueCnlXdk79HfzTujdX9yznY0ZZJvoMbDisU9yZH

n6dEn5kJaT3fQ8pBlYI7kqyUb3gYDhXCfanxXC6n6/2Jz2jfJzlmo67+ndkNf/q2x3eDA6zAwfGzTfyb7Tcyy7sj2iFmaijrIsY7l5OsbreDsbuyQFyuy0On6yG929efRqzlrGETvAx0aCsbIT09BnxNq7R6M99MdMj8jjDKi2QVLm2XeLiRPjcAuho/fa4KnWUAs+Cbos/5nhvFlnp5hTJHk8CTzueR9tGP8Tpi2CTrudtHus8UYsA1EQqTflCD

RHBUyTckDAj26UeO7ZsEUzx1OwRPSFTJdngc/1GdfiaeHOQ09R5i84Kouzz43D0n+jxvqlK3zHzsLcOyLJzH3ndqbgXcOzLeeHLKk8mLzc/7nyhSHns/QqT/PCGbsqhnnq7QXn/ncSzZVi5lXnCOQA9t5ZPc+qby89ddJJcD8MQwo4Zc8jn6JewCUJuWbzXQPH3SOgZEC/jH5tSxLuzVz02yd9hSc+TnZ4iDn2c8RalzfPUYaRi0Gs9Nnjo9CTqO

xgL9jD1UMRzwZNeCVnqnfpNFGyIL3sxU0cj4DpLM/ruidBUsDU9+2Oi/b0Bi8XoS+fMJCifA6uqxNazi+uiXHA8XuzdJzhC9m+BuL0X4jBiXkTcDb8yOJCPJbTrjXdNCNQvS4kk/eLkbURb1S+2GSRPaX9XdpvNS+1kwvdvoTGcqXoy96X/DAkbxSfvsXzdxnyy80L6U8SXwo/2Xqhezrpy8I4Mo+zoCo/sTwmo6Xxy8nJ7/j47sU8hLgy8OX6hd

BXks9UXwFDU7ty+Rbqy/lXdud8nzo8nKnp4BXyK/xq/o9sn3Ia0hiy+ZX13w87n8/Pn+K+6Xzy+nQ11gUnmScUxP2z5Xjy8nJk+dkMAk94zAMN1XzXc9qPY+FkDE/XILE+01DK/1XntRJLzBhPzpsjhX9y/tXpExQnwkQwnj52XL1hcaHyE+QX6E96L2a+rL+a+DL9CJvHgDgfH1a8HLl5ewRWnScEba/C2ivf7F0pt0H44sZbm9sN7u9sVAEZAU

AS2BewXpBtgDgAm1CvIm1TvIxOcuAcAT4A6rZZZiH2tk4URxNDoCKVQlYdcVMA1h44GEgr4pPbLwUpfE1uqe0kZDtOSZyHZTFH277iYcbr13M7Ni2uSj+Yf2HhUeX79XtSZ09eD+7XvOHzUcP7q8f69m8cMl0fdv7k3t+1i1ACYM9BK819doALzVBHjI6GkUWbfjkA8WD/9d3DwDcfb3TRuj/U6JHyCdA75A9wtDS89H2o/S3qpfE7oU/LYF62P+

gg+Kn+E4wCmDnGn+2WmnyuSP+uac/TupTHhRisK40y/NYMa3eX7OerN33Hm3ljfVzmLfFz4JfUs2W/THsy8zm5i91z3M+uj1A84n9iQW36ufRXgTdU7pQiKlO2/5Lts/Nn/k+WYdz39n9C/1GSoYF1kc8LntPDzYEy/4b9A+sLqS0KEKUiAae53B2PU/KBqHe4Hzc3knyBjycGGVrkMg9EH9i84cxq+5WkQRhmcHlyb06funzc1DXx+fGXVW+TKk

K8lzsK9Ec3URTX3RdtDr+ZH/TyCg+JxJfzylg/z6a/5i/yzZXlnfHqQAPWT4c4K7olu0qIq+zAX8+ABki+ub3C8Tr7Fr4n0fpN3/+u73nC8FQA++sEDu+InuXRfLs+9kXvC8HXra+P8RLoTL++9ubx+89haS9QlFBeY4He+EkDpoP3y+/7Ly6rFtVz3/37C9AP2HStLjRfL39/Cr3o7zr3sKi0rzldnoOy9Y2+4/LXke+IUe1dATxByvoJlqD3pa

+z37B/w35ynguMhtY26++XH/tC88JIZzM3MpUSTc2dXsPClya5BI8GGgt4P3cvqMEjHzvTcN38+euEeii5EHLi72SVAFsUu+VX8u8n2XgScP0R+LpgPebm5TeSZfO8JE88giPp9BiPxR/Vz5O9TzVO8Tn9R++72kj+73h8Dzqc/x3roxWdjgxcP4x88PiR/Vz2s9R31K/uUVqfgFl9DSA0x2R3wi8JyIvgqShED4PhJUOPgi8pX0sqVTqnpMyVj5

oPpo/dWoO+U72K+h3nATWLklesTrlo1z7M+sXhufJ6ZhegP6pYbOgc2e3+tD1z8SK/TPBdpYJ6S6h0UqO3gnfxbstqHX0E8WCXAOZzrze+Xx0zUPka9pLrhpNP8o/gwGA+7H188HHnq+yBpMntoY2+48U2+bz4AYmyUKB63NwOcA714Z4VcbF4MY9rn8C+sWrU+63iu9XqjOIIo8e/QiSe9rPoIwbPmIKIR5ide3ti9ctHW/wYPW9Xqrp8+X5KDZ

B9Z9XPzZ8IUC09mb7Z1iYO0sKn1xOa3jLDVEFu8RzxTefPhS9KnrW+PuNU8UHm+tfPwbfw0bdzYH5jf5Ly5/2JZ5+F3yHdI7ku8HP/sxPP458luNA+NI/x+zPx6ejPxZ+eLjO94vhDfbW4Z/zPk2+LUzp98XrOfeb3p9Olyi23P62+Mv5NC4vjDdSWll8MvuIQQ752fwvy290Wbp85zsF9fT8g+8bil9zPg4gLPvDp5H0zcOboFDqByl/Sv6l9xe

K2/x7h5+HPrF9iYNIOUX0hxjGf1dAv3HqKX0F+SN/ifZ0cswF8ThqpepCca35sTQVlc+gX+C8VPhYU2ngbDd3vE9NX4+8Xzx2fK7unfuvwa/nH4a+pLvJ/dW4Y927rcIAPv48vBJJskHwYhtX4y8Xnb5fqL2RewniN+EBDleRPhlc07v1/C7t25kPvBIVLqUM2n03fOBeh9AaDx8QFqF8mv4beGPmx9aP0x+D9at8gv2t/lMYPe2oN3CIHF18uLU

FCXYS7AJYZPgrcKcd/621teJ46e5u8AiizeLCRJkvfjb83hjv5MU+Tt5+r4+l6cL54i57ibcLv4iV0v5p89PwWizvnQ9bv6qXBbvu/Voycf3qKeijvv1oFPnM/nPod8XvlKY9da9+nPwp/e3lynWP+R8mP+x+jlWuevvu99lvw7IVvkabMDX9+3vzJ90PwD/uP4D+UH87rUHqvcHFktf0H69sE9kXMljqtcQAU+1JjgZANAGHoGQPJwxOeJyWwL/

BDIVUB1ASUAA33tcRoWGhhByIYurIcdC0F26Tzp6SkHLtlVPsU+Ue/oe+r53CLCBCTx01cdlHdcfY3hXvbjvG/Lbqw94Oom9Kjgm8njs9cUluTOUdgQ5KZp/e03qoq5ALw+0Opju9Y67T6K95uh198fL7Daoqbx7fhH0vP2jt7cmHEW/x1MW/BpqUsQbpA9Mvi8vhvlzAFy6Cce8wvdOJnF9+3lDe+v43fgzAN+efzS+g7nz+cnlW/9BJW8q73rB

Gv9fgCb9VgPi1U/AvzW8YNyi24Tvt8mzJez6eP09TCOU8hNFL+KUKd9qPnu+Bn2kgcbpmphzid/9vjXEX2eo9Vn76hlfoa0Vf9L+jHuk+Huh6m4B158Kv8p56SY8+UngYdMtdr9+8Fd8diNp8hv+q39f8zfnMEp9usfBdPSZwUmb+zcDfnST0vYlc81VRTwYAl+EfBb+df88iiLhG8SL61+UWsb/bOib9J7qcfR7zULTz30/zf8b+rvvafXXekxh

4XAO5fyd81qbInrMailvTo1LrTi6daT1L/5f7ImQzv7Te4bELh4Or+/fl7/zETZflSbtg7USM/yX+4ns1LOblPo5eHisTBiGGhhRfvzAoo8prVEGVSBUYT7XaHUgarpCfRfrH9I/zLxvL46wC+KdAY/hH/MwMn+HS8P44HqTd1YGn8xf7H+nYIcgOETxIBTVn+k/uL/pytMhmUBtAj4Hty8/xH/8/tMQUrwob+YaleQv9mqY/8X8/868hgqBwk28

RNi4Bgg8k/xX+RWCmigsGiUo+6dBMtTX8K/un8S/9aTpQjPjkTdhCPfn795f8H8Wr7HgdYoyvdEUH92/yr/Orz6yL88FgqNkJqHfwb8e/ncQ0S0tA+/nDl+/xb+RWLj/ArnRqrzwV/Swu58ivyRunKKP/yBpk0Dmtj8lz/EOR/u/wp/gMtTB4K+injP+3WF1de/4P/1W/P+xbwv8B/19BB/nHj+MU68lN/nMim9Ld4jitfZb9D9CAIwAUAegAwAe

SBsAE2peHUgB1AeIC4gZgDDAYZBFDtgB4D8ocVABrfdj6NA8jVWRLYANTDrhjhDwb+rU+nrycj9fesZ8L8m73rAY3tcdGHzdcmH6UdmHtv2e5kjuE3mw9X7yRUyDwPNyfijsj+qm9q9Gm/uHhMCbAdT+m9i1A44D/h6edm/CIf/cObzFOLjxbR1M/SI8880TrIDdwzhE7aVYftwlvGUspbwc/Zjlfb0C/XDB7bzjfOFES30i/IhtXX1zfI6xsAM5

zXYt4B2S3RAcm/yQ/MtdrryYPW68JABgANsAh/2LyfiAvQB4AZgAYAEmAfQARwFIAeuBtgDycXAA9IDHqMfdAO01zeaBnLDCIUvBHpH/zELZ/tE2kRFgpSE5cZew193L/J29l11NzVjNsnyFID3VjM34/Z3NBP2w7IQcRP13XfG95RxdpQ9cb/zb2KRV7/zkHY1NKb0vHF/9lPzf/CQBNAHEQe8dboAxEIbRWO3nqKbZAAKVyY9wmYDCPNOlQDzM

/CA93tw+EWpQvt1AnT3s/m297S/0Adyg3UJUQKQ5fDA8k3z5fA090XwwA/59WR0BfKo8M8XuJS2JRLR3fYV9Kj2JPbICALhDwWGR0/2dvIndSlFHCJbQw4iq/HZ9WcHVxO1kqgMC1OThqhFekBe8R5z8vcitsaC1/U38lf1gvNc9zbH7aHoCTf1i/H/kJnxDwKZ9UVxbDTC5e3zt/ROQyV0PvL19G7wLEdPwnv37fBYDElyDfTu80CA6fULk5gOe

/TYDJrxBQMMh26BoHbRt5X02/Y79NrxBPd48QVzlfK78jv3peH48FZCnhVfBY3yVVS4DrvyaMb+9kFwIXbt9IOCXfDr9rgO+Cfq92rxo3Zd9w/y7ICVAcnw0A2X58gPj/G28DyDUAlUg4QIDPCv8KgOhA0OJUQO+iAmUT30xA2WYYQPUA3ECYPzJpYgDMQFIA8ptkB0qbfEciez99IwAknA4APSAtICScXABJABicS2AYACgAOoAhAEqAYYBVQBH

AfAArUwEA8Wsu4AdMBaElIlxRYnMGnAGAYaR5KAGHSa52xFoVXf883z6HPI45dwQfOydHCi0AzDsdAMEHCvZ9AKW3U/cVtwk/a/9ibxObaTNZB0pLBT8w8yUHV/9PazIQRwCKEE//Jm8HgE43U50l/T0/TT0XUydoWUgRNjMHfwCBb347IICLPxCAqUgdTniPeA9IgLs/KCcvMyc/d28cAMmjLAC8oTiAj6lm30S/Hxtnjy8/eW8e32csN08i3XQ

nbMDbjwtPcKcouGy/bE9UAJzA7vUwz0onQS803xmPYBs2N2K/YM9wTyLA1o9Yn0LPOK9uj2mPKsDotDQvaTdLHwQLEt8pT1pPUc9FzzTvCU8TdxHAkIhvzy3vEq9kSmHAkXckWm6/aq8122BqFUCZd03+cQYDN3KGMLcuag3A4U80T2K1d89IcC8neW1FwLduIh8Z72HvTGcDwNtPF7MkLzXveydnKwvAh8D5d0QfZ8D6/0LXBD80t3IAq68UP2q

bND9am0XASQBHgGIAepB4gC9gfQAeADycfiAYAAaARuBSAHLAPJwP/2n/dQoWe1rZV/UhWUNUOQxh1wYobrxrGDXwFkNVa0OcSH9QRSbsXZcbcw/fTR8FH14fA/8BPyP/IT8FtzP/PDs5R0v/YwDDx3NA/cdLQIsA60Cn/xsA1M1rx3sA9ABHAJwVF0CP924AY30HZCDrSpBZl0X2fT8SzXCILh9QAN12cADs6WCA8nRbgWs/D0cM60QPWMD090L

3fIQAvzlvYtBgv2VvUt8uMFfAsyDJTyXAtMCEvwt0c0s7wIsg2YC8wNbvSOcpLXVvb59y0Ay8B4CXLwxXW18vIL24eGVyJ0+aAS8K2CNfO18goOdkGLcvTxK/FMCg1wCg6F8dHl28UD8MnzzPOX9jXxBfHyC6j1LPai8WyyC9JyDpwKBDZK8cTA7PaL1XwPaA5gQLH19wGLMUAJ6PIyCmvzHA/R8KLUc/QyDIUxzvFTc5wMWPRDdigKQwUoCaJG3

AtEhyhgyIHqDVAxKAqzBrRARPGh89gPlPeX9af1ysIaZp7x0XRNh1FBBnXoCFoOBPV0EPwLIWMP8tv1umSB8P71auaxt1X3ewJ/NcFym/Mp8HxSCBfEDlANh0fXcrlxKZGdxUoKKfYzAJyDBXMogi2y5ICs9g71ivUFAzdySfFb8JVDW/aCpt4BaIHLBcjUhTcJ86Vy5XdB9Mhnm8LYxsZ3bIHfgIn3X4KJ9441cUJgRrcj1uXx9TV3jXLrp+HzW

PE+93dzEXZ3xcSEhgHGYpoJGvTGBiYN2/MmDWGyvA5aC/5zUxeG9apx8dcmCsLwhmNqhgMm4oCD8+hX93UUsGyUoXUTxR3D9A3mCVqH5g3fRjKDUXWpd2lzFgvtg8FElgwF4UYPpXLNN6KFcfcWCX1AFggwIAGkOsanJnLDkfGiCv31qg3wJ4WEyUa0hTRh3PXgUjHwbfb99VXjM8dqg9uBHgXecrYPrfWiDbYMRJYd9L3xdUaCtqIO4fcR9jYNb

oLQ8N3w+AQ3h1YPlghhghZR7oFG9Z7mymVDEAPz5gzWDFYNHeDQh0fX8ECdg3O30wHb9WYLpg12g9pyf0AtgJzHaic8gHdzxglLBNXUCgevR7MCDsZGDoYLRgtD58PRRwOYgi+XgEAGDIGSBggODcOG5wbScMgNE8LEC9r0eguFhkWHJtBvgQJCCEQy9qFwu/WbB/pzvEZ2MBxmeEA6D97warTV0CoCI9OhhaaGOA68CVoNIIKAkPESJlHDwOHyP

A/6YTwN+fcS4AfxmOD3UYcTL8FcCvgEmEK20IdDBRLjJUoEJhUt4U73HPFqCBPji+PgRo0CqhEjVHH0IvVWRqu0/g/QRRWFFhZCtnoLffIr42HBECZjIWMhFPdnBmwOTPTrAoEJeTK1hBSDVfa6dwzyonBqtkEJAMOkx6DRLApqdZixwQzyA8EO/zGy8273JYIBDD9R/gvmNyEPcgm/FXWW/g0BD4v0ygjMCyFjPgh+CqrnQoFhDIoO9wdhD74JR

UR+DuENFfVhCHINJAl30yaxoPH8CyAMuvFv8stzpA0scKADqAEZAZgH0ANxwjAC8OGYATajgAFiBS4H73N3ZsADUHOrcUPVn/QG9BTC7PI0IHkT0iWQ8Ot1MkTxFKdzfUO54t/2roBgQtpnVeIigB2QIOc5ZnLGJmHqwmiz0Pcg5Mb333TEtNx1MPKnYDALE/aT9rDy1AUwDpB223Z2s790U/Gjt7QJEObs5HAL5QcSDH1xl2G8FSBCX9Is1bt1B

KKWFTdh/HP9dgwKFvSA97wWFcOR1YAISPaMC9IMQAv3toN19JZY8vMxvfNKCt2C8zDsCav2ifVMDOrn7Ans8aoMD3UcDX4KXPCLNIbkGgtSdbgQvOe+cc3RvvWDF2mQ3gxmCZrwL3NsDk9HfvReC49xMg749hLwz9MbcmWldvE49vjwTfPS9NkJ7A2481DwN3AeCVkMrA85Dopw+g150I4h8/VF8XZxGfN6CVkRedcoRHkI7rOF9/QzaNC5CHoKg

IJ5D+X1+Q3MhjkNrQIFDKNxBQyb8uL1kve4CGN31PJjcoUP+IAB9SL0OgsC0sZ2eQphZXkMWvTeDHjz2XZIDEUNdndQhRGk+lHzEel2+QhFDIniJQpSRr4P/BI999gwxQ4FDqUPnvKqCBwMGQiFDCUOxQ3Btqvyp3Wr8KUKLvKlCuUPZbJsCaGENIUr9+UMxQpFCtEnTAsRCJUKZQoVD4gNWQjlDBUKtocjdKUJwPMko5UMhQ5lCFYHSAhTdRPFO

Qw5CWZwRA1l9bLQOQm49rZzaQ+udVvHlnNs8LX34EOExw9zj6STd60ByvJe9EwP8QAYCWvyGA+sCqwO/6ck9+6BknW+DJwL8/TzBsRgDQ7ec6UKaAvACOmn5+XzICYOavVYCQZy4nMTc6f2UnI+8VgI2PWaDCD1TQv5d5skqvQNCb4Kt4OSdXIIjnJSdfMlnAhY9e2BLQ7uCzpz0nfxAXUOZ3ToCpmgIQgo8Up1FKWs97UPbIR1DAyhrAp09T00z

PF98wPxtQ+08MEMonZ09p0hugwnd0QNiglsCcJ1dPNyDMgJ/fdJ9rUO1Ma091UPGCPcCTRC6QkO960MVgFpDNyh5Q+J960PNQr487oj/gkJ8fHxEQ3hCkvz+5fpDBz0wKDadS0J7gnTchlFLeJ187BCPDPi9QoPTBcKDsumWfb1DcNStQiBCHY0fPYq9CsHJ3XKDYrz5QjYZaUJIRWFV70JnPDuDX8AjQk894MNp9F+C9Hzfg/GCbzx3A9SdtfXn

PLDDRkK8qCZC7z2rRCYDC0KjQz4h0TzYff+grVALQyNDevwpg2ZCaHw9fZcCpJzQw4NDlRiHvGzc0FC6/DjCevy4woY1HwMQfKEsyTwYwzjDi0MQvd8CWMjEwmcDzz3Aw6tCOYMAfNzcmZEnVQjCTgmag6to6Lx/vAhdTqzjvNlChzxKeUp9f71OrC9DSoKIvUq9ArxArIdD2kNrvTux7oPWvOSDGwKK/UVDEEMzJd6CPkLU8F598jycXcsDwgnN

3DJdYkVoQ59D9UNfQu/kUHyzfVsRshCcgggCb/Eiw1GCTzhnJA9CMXjZYB1dRV2M7FLCb/Czgz3daeHyGcF8JXxVcHLDSYLywjTc6EKXQu2DXYKNguFJuXxafeOgNmBD3D5A50FXSYDD5sCkwOuhk92nHTMwK0k7Q5/5u0Lp4Geg6/hpeMvAZp1QvVk9F7zQYIIVlp2IFCWg3MAfPTe8q0KvPLoJCZFTgrLBlaV8yVDDBMKkw5ODEsAm3NbDlCHT

Q5YDBH3sw+15bvyGnEmQTFX3KBNDvXyzQhoIzsOymQ6ckyk2woNDtsPXeQdx9p3u/S7DRSi9QyggfUOqJLYFzsMewsbDncAGPVnc1mDoXRTxdYPo3dkYd0OgwnpCehTCISHCXiGhwuPpygNugpxgCSjLwZHC/eVbQvzDz2nLgj/hEclp4Nl9bkjhfQ0964KunWrBzmFwwdGlLpxEIKnCUCj36TyCkoNvQnkIu4NenJG4c2Ay/GU8ywPPaF6dcMC1

mLngAlxFQ709xUOP6Yhdy+W+SOvBIMJivRo9qu2ngq+Jac0oiSqDuzwwvZDDnWGXgok0XPBhAR0xK0IPPQAIlWHpMVvgtsFAoHd4KMMYwoTCpPnvg9IVsQlcaAaD9NyGg/DCVwkB/GGdAXWJQ48C1lxPgpBDmGGqmE4BtRBKiV89SUI/PM8DkuV9UT0NXN2GbSaCWMPafUN9sIk6IOEwOVQa0RUxhv12A2PDiOFjIB4RaZwpRNo0ZkIuPGPDrvjf

nHLw4jGXKKPC88JG/A8U2ZzYQcfJDrHdwo+DPcPJQkzhjl0QkL8x6agzggqZA8L+YMlCQ8Md+BaEqmAJ/T6Z7cNUnMjCBwkFnWf4EDGy1YGEwMK6gpTDscV0oOshD5zTwNrMp8MWw5KJpZxoNTOo+ZhVw6c9b3HVwy7hVAmSYKd4h0A+sEqCWzwbPebENZx6UHuZTwxSgldCQMJX4I2cLKBNnFwh7oRKAEKDHT1/Q2H9V4nLnNOdAsGXYBdCAXwN

Q/GI14He4CdAUcLYbZMC7ohHUSiJKf1woQwVT0PSPNngCkjOA8swvGANnAg8U0KyPfTEtC2FXY3D/BVqwvd8HBABXM0ZmlwrSVrCto0PlY+ARuDbIRbYta1FKWHC5cOyBCqkSfRoIvfpTkC7PV1CJsK6AmaV2qlKUU2cesBngKZIfsImPRk9qBhJwFvRF8HtSL/pzcMkw+lDt0Hq0cQiyJUrEJMprsMzQk7DGRDEIkagJCJN4KQiWHwGfSXdOhEO

Ec2wXCH4Ijstv+l0I7q99CKXlJgjqCLwKVgj670JgpNCfpWZgFkhmf2yg/NC4MMtwqGV1gRcIzOhfhCwqPXDt7y/4IgjzRELbNjC4+iEIhk8pMTOwOIgcCOsYfwU7UL6wq1904jcQK4I03C8gewYHIHoIuIh4cImxJAj26BQI6XxgqTRw6dDWAVrQfIizkEKI8S9LTyy/M/4KfzgaKn8j0nQI7fdCsLixWt53lwaI4yCzkJMnHiU7SBAIgahBLj1

QihCs+F6ItSJ+iLKAxM8EEM43OyVgCNGIwo8ZcJ+ghgigCIgIWYiwCL7A1lCBkKMwlfg6iL7MagjCr06glfDmYjaImAjdiJpQgTCXsNkIzLw8iIfFCoirP0Pgt8968O7wx+UUiPLQNIiWaEE0bYC5kJmggwFoiJdUcYhcCN4CJaCoLxWva6VXWEBXbKZ2nCfvTUC+wnriZwiM3jCUeGUNQK2grUDGCKoInoxbCLfAqEjFd1jiHgijCP43EKA2ung

fJEjoSNGEDQjZ8Qb+WThNoKCobaDHRE5/WwjpZiztREiqSORIqxIG4jEFAx5KWkpI5C8sSMruEwQ2SPqsYRCbgKJI7kiAwC/AqRDzr0vbP8C5EOLHXbVSxy8OGJxmABRNeuBK4HiAIwBSP1CHHgBcAC8OLw5y4EUgeT0RQPe1GwpPRhWoOLRkNhOQCKAg8X4BURR0jlZnZAt18m3oXp8N90kg/ed58IyMN6x6IO0AxiDdAINAndcjQMsPKJDTQJi

QriDjxxv3BJCrAIUHfbdH9zcPB0CKgEcAv9sGb0NHbM1qPXtSSiIZIPtyL2gV/WHWGNQG8SuHEz9VIMFvKI9IAMAnSuhjXVP2GpCowOF1KICs608VMut3PymtL84ICMNQ13cPP2vQwKC+EMbIzPdmyN8g6oiAQNJwjdCxLmlAw+Jv0PfwiM9BV2rvXNDIVxigpM8piIygjAiV5DzQuOVbMKKfDpCMX1rQ3Sd3bHMw0/DTHVxwsacRpAiI1r91v27

I9tD2MKqvItCLiMFZTL9mpy8ID4jpoLTwkFp8CIT/IhxCSKZI4kiiOXvIpEDIKDBAxN9aXxOgvd83kPBcWKdXxC5fE1CeXxrg1B9s31j/el8Wnxpg7OD6pwgo3d8HyP0wMODHCQjgrgiQbW3IiqdIk2D3J3wmsOGnFcitNyo0L7hI9xT3brC09xtfArD5yJcFLhcVLVFmOihlUJwPIrhYuD5sdvAfrAwaIZDyaBWwvbC5YXIXGCdVkLY4AHCHsIe

/ENDNwL4o2DFAcMEopt97IOVPDq4KmH4og6dxKP2A0LD7SAWOVph3sLu/C7CZgMHIvtD0wVhRGSjRKIEop14Z0KnIpKARKI+w9SjBUUXIiBChGBTgziiJ2G4onKDZcKLPRijZEUKgX/xQE1g8E/DO5xnfIbDuFxooqNVGd3WIwc8UG2kMAadQ91wouGDAxCIw3EgDYL9g7R9wqKagz9CEKBZg3LCujFAwhbDOwhbwHGD0sO9XYboFMK6gjKjEnwv

0QGDgSw3PZfD0qLUxf5CnMPpggIivGHKo9ZCL7zXGaqixvEWQoEinj1L0Rqj8qPP8ElDO8ODw+il2qLUxaQitsLPI+TDSqO2QDqijfAAw37DJj1jmNKjRqLUxbZ8HKK7A0TRcqIWPMai8owvIkqiZqJqor0YGyKLjDwieDRg3JVCavFIw3cDmWX/wl9CjnRYfIPDTwNXSYoianwgvXFDoLwovI9DFiOEwmTDYIVhRByA9yL+w16jMSPP6JzJnsJ3

nPJY6qP7gJzJzCNowo49lMNRQ3C8zMhTw2+9jMIug3+8JSXJqFe9GxmOvB3xfgOm/PZAjuzAXaN93gIDDHTC/gJ+1I7sCaMxo8EJaLwxoy6DBUgCnT8iTkMhove8fiGpo8eCBr2c3UNhz7xBo8moSaMpo5wUXgJUw6GiPkhxo4pR/j1owFmjeaIZo5Gj4H1Rox/h0aONpQmisaJfKTB8SH0xnTmjEaMMFNggaMIl3CGj+ySZoia8NsIkwnr8ar38

vbWjjL0EI99C4L33Isa8Er3KvdkYNyPrPLvUKqLyXSdDe7wqA7pM5rwdoy78XL2cXXa91Dw2veFCBUI1QrdDJjUcwt2ieKJuQ7oiuaiDow5cWyJZwzMDVqgjo/a8vLzHQsKDP8ORAvpdLkJ9oxOxnqOyIqOwwUKCvL6ipqK1oiK8Br34wk8iqMItosq8Gr1ho+ZCrMIKvSEihSLVLWq8aaKto+N9G6K13cLcjaMSvBdA7kK8wwCjq6KLogqi3WDb

g4qje6J1o+3c0sJDXSCxh6ONo7b9lJBgolKivaLTo5zDEKGKwnRVYKI8w95CAKK5IaCjkqMkXPygDFyKoxt5i4LHouNdsqKeTQqjB6IPoluCz6KZkduD4XgSwlWDjrj/ImKdPoPCw9/k76Jhg7GAx4MLo8EC/KBLgxVdg6lro58jhSPCCZejEbxDLXPDg31TwqkkkKIlggkVPXyHwk6iyBW/kDWCFYNgY+iA86JEI014sKNJcHCiKJS8fEJ8AEPq

wpeJsGKGnXBjJyMmIsXDriW8o6ii2GA2XXzDMd0QYayjGcTlhAOco6JNfVnDTXnuwuSiaKF5fHajshVkoz7DlKJSPU5gIcPE8bHD/0XgIrS9j+hEYrHClEn/RRlCUgM1Q4/oCcOJkZJ07TDVQv2jN0KNPTcR6cJCganCFw17IjRjycLWYdnDfELBnSFMDGMxQoxjj+hMYioIzGMU5LLCzXH5wxjJ3p3z4WnCnGI+/Yiho0wkYoL9B4LnyCxIUgzC

/XhjmQglw8xwpcIyoHhDWyPYYrz4FcJEESbB/BDyrcrDACMNKTXC5OEZ5YlIE6P4vD/Cl4Ku4VJi14IqmNJ8WLyXItQjxRQ8RY3DKWjfUeYi4nxeoq3CoZxtwt6UHpTWI1XCkMNmLOL5LmBywfIgByMj8Eaj5wMNKVpj+pXL6TpiIwWOop3DKEKawNpjulkGYtWiPcK7w0+DkEMg8cH0e1AVom8DvcKiEURJ+0HrLR8iRMOZIwb4DPB4Ic8Fxt3n

g1mioHz2wdRh2yA7UDPADmMSMGWjSaIBA+th1MD2Yi5jwvnsWdujwUPa+XZjzmK6sBEjlaP+AltDTmNxdfZinmK/va5jKaKIeUUj4P3FIxD9ZEKLHG68gILzgR4ATagQAIZBiAGUAXEBHgD0gSYBiAAaAXpA5gFxAGJwknCMAbwB8AAo/Cfc4GnvkWzxrGA7iMZs5Dy7kB5h47RZlfRVkTivnZvC0YSKgTxC8jl0o0yigcKm3dddgkLm3N3Ndm1E

/Y0DxP0JLXgBYkNObWT9LAKpLJJC7QLsA6MiHAMHAZwDKnADaEa0l/Q+bM4cV9newLIkcyMDAiI98yIgA+4ciyK/QMIC4DwiAisiYwIaQ1z8DqNDovDdIGDJfMWxrIKnA2yCzb1JfeDd7WIyg3hDW3zc/F1jdyjdYu70tXyRfWZh6DX3Q71iRsyd3IjlDbxGfc8FiX1tvENiZjk87EG0CmKvEci4FBVXSamU4Nx9YsNjurWYvJNjYzzuMdz0eT0u

YS61mVzZfbxjvP2rnAzCNiMTvSyCY0PvAmc1dH00w7DDrL0xfANik6CUfFK0VH26BAr9vMHWottilOjzvTtjoKTIYtzDpyIHvMu9jqBkfEECM6Kgw5rgaLwHvPTdl0AeEaeBk438oppid8OPnS6juqIWUIKRlqP1w5h8O8OPglyl671vPYaDTHSmYuvCfMUPY/89txjCtCug92K6og9jk9BXvOujnwJBaM9j7iIvY5PQdkO4vN8YQbTfYq6ixzme

Yr+iot03Nediv5EA0bLB3yMGILuiN6JfojedQOIOOJdjIOMQoPejz6JxMSR9QpHHY7sM1yFpXGRInf2MkdUtlH37Yk2Qu2P0wX+idVzrYzDCG2NGQzKjx6MzYi8sK2MHPKtjZMBAYtmCI7wLYjrhdKGLYxKjoGMTgyOCBzWivEdw/qwJYOWDkKK1g6uds2JjPeJiP2VkwHjiFYL445l8+L1sIzPDckPjg5BiUKKGfKV8iX1lfGTjTYLU4sTi/WOb

YnU9gJ0Qo3Tjw4P04qH1EoJrfFU9p6I93ErDaSAdY1UCt6Ls49mDrkK2QtgQyOInoj1Dlv1Q4xft9hGplXqCSMG0wPuDvaOUXcVlYMQC4gd9shC/Y2S8f2P3A5oDaPHCUR9inyK5I+uiXwNS6FoDEuNLwgC9gFFNwIcD0uIS4wsxi6MowpjCFwPy4/GVzpGGQyKiS21K4y3xyuJQbeaiFiPLPGrjqgNZNaKCJiOHYihisNzK4pbQKuOoLGVClLyN

3FrjMuJJfa1jBuIy4wriUAPTY0Nj42Li47rjWuPUYyxjQkEqAubjhuO+/OhCDmDG4grjeuNIPArDiDyxDeLi6uLSdMnCluM24w7iw71jYgJAZuJonFbiJuJDotzi1oNGA9n9WGJBfKJi+iwOAhr8SOPlDHtjpSne4tL9PuNGrEXC4oNmnIECrgPpeRNjJOPTIDrQfbh/IhCiDZGCfCzCCGNHQuP9TUKWfCKiqOMkofuUp0JqfPYitz0CI5dDCmJU

1NdDb/mGYozdb5GivZyx/0DPAbB9c8Oy4m9j34MbPc3hpSD0UWygPxCWYreClsIZ4ygxf/B1DczotmJfIlCpQYMBpNHgExCuYlm9dkIrwEFRS3h6UEJA0lFFbDPxG6Mng8ajA7DrURGC5eO+Xe5DPkNg4vzwUrW8YTxIvmjOg6Djn6L7jSq9bPCxmZY5DeBw4zeA8OOK0ck9TeKxgrXlR6OFXY+jyON2oyZ8zeOxgmziSYJXo+zjXeMmA93iHeJ0

4pBizOKTgoYx+nwsIu+g2BFk49TjqMP2PcPiD4LCoDR9Qk0cqeTo/43Vow494+PJoLBjBp2UIR9M32L0IiPj732IomPdFeP0iSmCu7xsYIiiusOL44rRK6LCI0LAs+NCo3Pja+MN4RPi8FGT45TlG9Gb4kTiJYPk4xkZryJGvOvikqOc4+mCu+MPop3j01zo4vR5++PL4muDcOIqoJDBmMLLwpE9H6I14/iojnVH42GYXmJL4s48y+OX45FCF4Pq

oxfiIGLsVZqjlr23g8w1d+JP4u4j/2Ibw7kZL+NofDe99iN3Yi/jo8Jn4pK9eTwR4s/C/RmnvIGgqvF++fJiJOLTPa6Q7xh/4xtgzwAuYfJih2NFw+KCg+XB9FiQBQhDLN/DMELYYEWjRrC1wQ/BUGNzAtACW2Jc4jclv7xamQpJVqKTAmtjVdxdo7ECwH0roR/ElYNrg7N9zuNtY11jJ+PCCE1clCG1CKkjBGK9Y+gSM2Ku4hAUdvwzodPQnWOD

YzgTpuJoCVx8FlH1oNMYbWKm4uNiaAg0fB2DlPiQ4wQSpBMu4mQT7YPi+DPgFBPkY4u9FGKxJBrCO300uLuULGP5fKxiISU9gx99m6HBFY7jtBJTeIODS903ffQtLBIDo56lo4JmwmW57GIu431jtXGcEhqpXBPRpbpxdsKYY5M4qBJ2wgBDJcECEzoijUNzg97D84PX4eCg3E364tsj/sKxgJ+CPCEsoZy9uyPPaUq1M/Vz0WXRucL8gjHCBvzE

AgKhnGna46AS1gMyE1px91BMjblDp2Ka4qRjRKm54uJQqhN6aDyiyoPyErITKhIaY+tixz1zMI09yhIaEooSiuItw17DmhXqEwoSchOv4zdivcPBw0YTshKaE0vjE2GvY3eRzsz6EsYS5hMGIJ9jAGNS40UIVhNmEh6VzoJhQ0S9YuP/eHYSOhOyEMFDt+NTYGYTThJX47uivoOmE2Sp+hPGEy+iB6Ovo2+hfOOOEq4TGhIelKGC5+KV0NLQRnAr

g/fRfxFn4q3j5+Pw4s1wCcKLoNBIIsBo453jPOOP6bRjNNibgsqpYRIn47gSXhSsBfMCXbic473jcBLNcdnCsRLr8MKgWOJzgvNdT2zg/EgDaDwlIqFjMt2lI6U10PwftSYARkAaATQAjADqAOvI4AHLgXpATan4gOvI2ABc2XEAjADUVfUjux3bIMgln9AcsJxCzSLIUQpM5mULxZIpVD0KgpcDHSPfWLwSlyElwQv0dQJm3E2tjD35Y3G8IkKF

Y/0iRWNsPD2l2IJDI9Uddt2lY7UcUkKO3R0C90EVY0FwNCSPceY4NPSk2F1NILwhAYz8dWLAAvVj1INDAopg/mHXOcICXh3gAqTtkj1iAisC3OJYQ2ciIX2JPKMSn0NXI+hDuwKNQ9BDkeJ5fX1Dbj0UA6p9xT2TEi1DN1QmosC9JLzk5Zk9Zjx3YvHjixN4ou4j8+N6vMLjKxPxMHjDg0g547XcSBKKg08Jfj0FomN8AqwqgwDjxry/IpXdfP2E

o/ujknyMwdXCsZxC/ZyDSOKPotES8uIHEw8CTYPLfKD8mHxq48cTWxMQoDR8YqMbffsSVxKdY898i+PO/aNDZxPvA+pd131sE+d8DxO3Et24lpx5hbwTPI3PE8yDVxKvE1G8FunuzMkSuc3JA5xwqRMhYuvdhc0AgmUj0Px/bPJwOAE0AOvJ5ID0gSUAvQBmARcAeazryUgB+IDycUgAYnBGOEUTAb0QkfThfhBiCDPhTSNlApkRfcBJkATQY6FJ

yZE5V4BCgFmAqPWIkjMR3SN1Az0j9QMx1FiCphz3XIwDokPmgMVieILVHcm8NR3DI5/9BIJtErs47RJSATJCjRwepFndk8w8AlfIvANIIG5AZ5QDA4R0AgLUgn1MNIJ6UUpRtIMhbP7dJbxiAhW876mjEbB9yJPGXMFjKROkQqkDm/2hYqgDYWIqAOCSkgAMgQyBJQCsAIZAoAC8OPSB9ADO1R4sjAHy3YlihAMIOdNU7/BwuL6Jh133CAq4fSiU

iYj1Y6g34iVMKcje/V6dBcNWOLUTDDx1E4/89ROEHA0S/SMYkgMjmJKDI6/dzALYk89cOJPv3ASCT2SEguViRIKLAB0T8clYwSspco1/3OSCubyf+WwxjMxKQ2STfRPkk/0SwO2zqSMDTWJEdSsjINw0k1YNS2L9QnqTTIP5Qi8Tg0ViwmAS4WmZwk19fn3ywySiEhPDY5V8tONNvH2cppNe4qYMI2KpfMZ9TqP9YnU88RMytW6jS53nQjaTTTy2

kxz0yCOKfMrDDOIOkiO8siOrPU6TsBM2ktjj4eMEnK9C1uLOk0PgI7wY4hO8rO1FSfaSXpIo4jTDuhLTvSaTREIG4rG1COJABYjijeTGkl7iY6N/YkGSC+B6hewSSBLiw080x2JMJLDj1GPHExGS67xUIwR9OqDoE+7isbSxk9Y8cZOrrMGiNaIz4xVChBPxfLG0SZPT44fFNBLRfKwS672pk9h9h8SaI8V89uNPNEKSyZV244pjVg3AYnYCr+No

SRJiteN8yJmS6MNyEotxvgLvY2PjwaLJklzCMQPRwrG1kZIlcVGSKQ3AQtrDwRLrvJWSK71kfAexM6MWogjj22KI4uGTj8PXcL1h+sP2/C8suhPHAgx8WUJBwt1DJsPLY8x9DMKY4tBjTaMGA/OjurRto5x8ceKfPbqDA70ovRrirpOJ4o7DCT1SfY6Sfb2DkgR9Q5MLnJ2jboNLw4/iq6O/IoV9EQLZfK8D+0BW8Keh6rTfItl8NQMlosE8CXyN

vKNjtOMyCKN8OxLxoguTI2JlfU29zoN0wmb97rUefFtj9byBYkzC9MPrkr6TsX0JA8gTcn3qtCGSfn2grEB9iQPAfd1jWyImkoQQwVxTfRUFTHV7k+19/yCSfC3cd4AH0CKCR5J9gt+i64OHkpKDR5Md4wTh/H1MEQJ8yKKmkzeTmOOUkch8elAlDJeSN5J9g1x8bsEXEjmN15PGkn2D1xNsff2D/IPiEw+Sf6Ab4nCjtCxy/BuSdTybkw7hOsJH

fFhJ6rURfX+Sr1TXfXRBTxOaXCuTVpOjY8mg1RLRvBMsQmmzk9BhGGNCE3588fR2kldd2KNQUtOD0FI9vCyj/33KYPacTdm9gv3B9kMukv6CVKJJkEhTv/hg4Gc0vZNCfSJNiFJ1IWhS/KP4yN6TBwLpYTpciKAaqCO8rZK0wrhStQi6XXhT0OOBzFGTK70EUxOUZMUBQURTZsOVkiRTUWG4U6RS73RPbN8SKRIpAz8TfwJpEygDUPz/E2pt64BN

qL2B5IFzZEcA68hicOvJlAEXAbAdqQDmAFwBmADDpZCTe1ydUVPFuEUNjHU5pRPDXADR8+HgkdI5nFC3YK0h2tG6wG3NDTF3oUJjtSFAkbli+B0w2OKScbwSk30iePRJvQjszQKk/IwDzRPYky0TbQOtE2VjUkLtEiAoBJMTIgg0x6A39KU4nEQzIwxVD5wTIdfY6pKDAgFtne0dHCpC413o6UDd7MzqQpI93FSEY9pTgdy8/BMCMALHE8yCMZJQ

PaVDFpKhk33skBNrAv9CigLGgqjwguL8aQHiWwNGgiNAALj94bctUz2TYnzEFlIzoaZTwwTwYz/jEe3C4qZTAuO2UjhS+imRPAj5NlMOU9rVumL9kyZTFlK2U6sQN2OPg2/imTxtwA5TIuPjk/mTRrxuU85S3lP34o5iP71LlTpT8SGi40S84ULV1TuT+4KtCEC4UONeEvrQ2KIzfWSUosNhgppCcHynEx3cIyBAuKPjzON6Q6iCk+OKwNGIMAOC

oxrDzsLGQ8phK+LO/CPh9kKc/KsDdxKr4/cT2yNJPQOCqKOmnSHZ6VNxPH+gUb16EVyjniFZU9N8nMEmnYbCeF1SfKlTbjxpU8lS7CEpUksSnMA/k4lSQLlb4xvpFl011RChMVJD47FSSRNXor5ScgJ+UreSsqOnQdFTmuPG47bj3/FbgmFTgYP7EobjbuJTo12iBlwsoU7ieuJQbeIQXmNbou/lif0e4mvDflNFon8wHuPmgtf53lLmQjBjx33q

/P7jsiSPYvDCpkJ+48r8g1MT8AGiqTxrQsH93fxXY7fCTlIhA4ECweMukmDCZFhh4pDjweKAE9ZSkeMgo38iVGi0okcje0OTklHiExPwojbi81PgopDjp5KBkqjpY5MJ3cITXdx6Uwu4G1Ox4oPtw5MbnNNiCNyzvJ6Db8MIU32jFuOo3Q9CahKtkBbijBNSA76s9ZISfA41uZPPQ819ssB+sH8Q9pMUopMT7KQsQoXjLqkvvT6TV1IqwvCopeIR

g2XibkkGItdTINB14sxFMZCoLFxAT1L3U4h4TeMxg6Z8A+OvUs6iwsKOdAmSiYOuk/Cjb1KD0d9SL5wBkmMSWiOvPDNDsZOUFOmScD2HU1PjpZNJk4fFFBJ7UymTINK6vGWTh8UtY9vC0+OZkr6Vw7yP4j5S6+L6UiL8RpM746fi9+KGUwGTppJlGBsTxtCbYxMTK1MGqcjS571KPROismPuopZC6NNFwOZSv8Er7WaZaNOwfBriqmKzo5nw4BI6

YrS0TZPbPSzDpMOXRPFghNMagkZCJwLE08GAJNMFtH2TFMKbE4GoV7zk03QlzREHw49iRmJ+otTSEBMihe9iHiNpDMBc0BNrUGqZfVNYw6tpjNKdUUzTMBLuPQEisH0xnKzSuYIwE2IJgaOdEVATrNNfQMzTReJkvEFSqfCc09ASvnU/o3sTaaKkvY2kCBKFKcqic6O0w/ATxoki08sJpLwOEvZD4aInjZdBByUOYj1T3NLGvYWCtVAsoTkinwOU

vVA4ctL6gv15m+LcvYrTuKD9eB5TDNLIElsQcQPBUGQFcMMdwsNSB+SJA+rTKBNR4+KjiMLXompcil2zXOmInZMrYr+Ta7BgfIhgt+EqYzsD01MpeQLCEV0gwE59VlNzYxyBT6KxXOxd5AIyYn9Di1OoEsCjuVzSE0sCaiPeoVFS8YIiY6OiyFmDXOESlV2rYw8SJkkQYyhJ/BAv0a9J0aSohW7TzYP3SIKVu1MzveDTKsMvINQTPxzhSVmSa710

rdt92GERiAwSb1KSYyhiGl0gU3Q880mAoy4QyFkfEmODnxP2FLMTQr0cEqhS9KK4Yn0l/EEwUtHTTGBOEr4SWsIIUzJ8y4Jz4RaggRJhEwdC1ZOJ0tZhERMbg/ohW8GCpTtS1gP5woQhxzAyIJi8idPSg8XDseBGXcnQ2RUp0/tTqdOSYnJjV4NPId7smJyp0rnS+RVKY9IQsFw50yXTlyJAJGXTMF1Nw6LcseJzEw0oBEKTCFHF9hXvItcD0CSo

QphDwfBuSdCiixMMWQ3SQEON0ldTExO/Urz4LdJVIK3S4fwA09mSP4KawL+DLdIiUmNiKZPJfQ0piEJgQ7xJMNMQiH3CUELpMQu90ZPw0kcU/mPt0GZMf+RPU6jTyIjDw6NQLmHMcMT5TdNcvTtgQHSPwMPRTOUK/eBDh2NXwGb5M9MwMbPTuyTTUnIjQ8KL0zZgiLm7JBhTEePXYRPSs9Or0/eR+FOwwwvSn2Eb0lPSe1EaomfCE9Mr05PTjSnu

BEniyqDb0lH1i9Kb02vD32J6okfSk9JL0wN97+P9U5MUo9PcfeA5xgLZ4vFCTmIM8aPSV9N6MA/jPVLeY9TAt9OmEH4CrkCS0mBcN9IP05fSj9OC4tOibVP30mdBL9LIEXMhDeIeQ+Kc79M+MI4NH9P+gq+jk+CHot/TD9M/0+fhM30Sw8gRz9Pv0uAkr9LH43GDFVz1UnZiL9PAMgAziRJno7eiLZOI4JfT4DK8MQPiFJGD43vjUDM30h/SMDJd

gk3Y2+LxUi4S7mLAMj/SCDKlUhrDsKJlUjPT29LH0zvSP0GlU2OC9sEAXTHAKIJJmJgzqDOIYlgzsxS2XMhxNby+4ZgyFunEQvYsG/0prGRDvxNyHQlNqAPQAQgBw0CEAfiAzVievMf9uIBO1eJxYM3hHIP03JIlrSpw9/n5mMTgSZEROGxDBgG8+Udg410lQcjNHTUro6mC2ByjpH3CDKGuTXeJkimiku+BqJOmHPQCfSJP3JKT2IKYk0Vi0pNv

/eJCLRMSQzJSDt0GONJDHgBqKfJTFPU7WaQgJbFdEgI8EjJV2F1N+x3lRPwCZJJqU8A9ykIUk2yhKO1akkMTWlLUk8MSupPUk0ykEgN7Uj1DDBJSAiDTkVIWknNDMCMqMsHThZOzrd2j0hJ5UhsCqZzoY/08DILrEmHSYeP101YMsZ3NUw1TsdPV0/u8LOJGA71S3VP4yHHTRyMmMtn9pjNFKJnTXf2e/X1VCdIV0nmT9g3WAtL9B3wwyMvSM51h

0gtT+Mn2MmOSC/wJA44yA5N40/WSLyyZ0p6jR1Km0zK0KFI+onjTJtPL0hNja9NXSE4zHZMF4ieRLqgHSL4yBzRHPaXj6cLrQdYzBdKl0081lN114xNI/2FIIznTFdPVLW3iH1OmAitJZjJA41Y9E0KEfDzdS1I1fdEzgNMJk5QU09PXYsPjaMKFkTYsX1KGI9UsbDJfnf7TU0Jd019jqTKGk47iajI5kwjTn5zcE73SiNwZMtkyPWDejU81RZLJ

MptTM9xbU/kySTIl3QUz6yIRkiPTeZN/UrEznuLYQ2RS7eMfU1hM49KRUyEzz1MPQE8wn8zGUpOiwLQ6g6EzL1Kfzcv9Z0PY0/ZCgTMPUsjMVlKuaHNSltO+MmeBN1OXHeyjA5IeMxz0PjOE0px9RNP44y4zOwMoUyrj0eKekfBSNjO3Yq5Se9IvLWYzNNNDU4fSHbzGM8jDqtJmYg8jIQL2g5kweTIX05aSQeO+A/LTqSMlfR4D/f3dUqGiCoAB

Up6TA1KnfXYzm5N805LSVyLjU6d9gtMtop1TZVxdUqYzF6PV424TX9P3k+H8FjMXo7ziTVPVwuoz1oJ9UyAydVIPQI38GzI7Mkpc1VLnotsy+zMWMkzig+NE4lVSEoPmMrH9pzKJ4MzxcVIVUsX9F10XowlSaDN4MyczXVK3MslTQTDpUjKCpzK3M/lSfKJmnDcyvjC3MjlSXKIrvO089zMbMr7gOKICEvBTKzLd/asymGH8EtBTIfW/k37iSzIe

7SJhVKLEoo4wEzJTUv59pGIYXT2jXyMOM2HjAmGUYkZg4jHygkG1kFOgwRESqQykwe79TjPlkxtS1Qnw9DCz1aFbnW4y8LNsIVehMLJJkehT7pM8otCz8LLIswiy8fUk3MGCMbEdM3DgELOBLRMJkLLz/c0yVeKPUrhT6Fyhw/zCZb24smXjLTL4spHClEiI4PSSNFIMk2vcUBzpE6DMyHRgAEcA3HGGAWnt+aUIATQBORMwAL2AXjjycMcBL2Uc

UkljssD/oawM5PDD5efduKE/UWIEFpQTsZxCE+BLwbqsnQUFTbWtMTnOWNiEm00tiVT1XDKw7GiT3c0FYnwyNeySUwMiUlLNEjKSnD2ykq0SwjNk9IY5HAP4A+Mizt0aKc8An0DmOf/8P8C8A0IxJzhUg7f0GpKBbBpT7ZFszYMT3RxUkspB6kNKMxpDx20gII4xOCEHQe/svzjRDHMgcJjM3WVx6rMUJa1he4LA8XDBs6Adw6xh4dO9dEKB+PEV

cS0NOrOLaenAerMdcctBs6F3QAb8SWn1INyARrOKUHHhxrJQKP4IHNxJaXvRlrJuwUTxxJE4WaLgUVC1UBXASLgmslayD3Q9PAbBs6A8QI8QieNCzYayiiFGsxayFOkH0Yrg8cAlwPeMWrKhE6eBmjN5sbgxRvEXUiqgM3AMkKqzSIX44P1pIhDwBarA1E0fsUdNKrIb4IGzzbF/uNBIBxQjwXYhqnRush3Cig3hs+awk6CRsuvjpLXftSazKRmX

QXqj38ELBEl0MOA+kwdJgTBR9ZaJecAK8ahpilGHNVEg70icEf+hgtStIUCyhvD2QS1g9KATILBN2RlJMLRBKrL0UCLwPvFFhWY5lCARmKZJ+bJ+s7niY6Ax8cCACEyC6AhJgqVBstASxz20IZnxnLBCoDgFmDAHSFWzysjUTSpcuagBIJ5B9WH9+RsJ+Mj1s8GzrFFpDeOR6lXYQdfBTFgwyS2yJtDERdigJokW2OsgIcEWlAKBa3jBsl2z1bKr

8VzQILnIJL2ypMilsw2MZbOFsgflG6EsUOcFxdM2Qb6yI7KFs1ht1yDnEK9BJ3FEZOOJB9DvoVmyCFENs9/ly4KuQWkJx1SClUsw5HAFw4nx87IQFawxItMgjTucmbOzsiuy2bKrsvNAjeFz4bVQRCGUWG6jZxDhMKmzLrJTs7whuKHTqIWcBEwps3uyLrKDJVhsP1n0YYPEsaFrFILczrOXUecUabKjgsglMcDgYNSJJ0MXsvuzJ7MKJBt4h4DT

QCGolWXJaCWxSZmwwaIlBfz/4YstHTxuSJPBdrKYWPjg0rzNcDHBGWmy0F6hzGPWspdBNrOms6IlmVEBQcSJdVBfw7WBZrJJCW6zOI2G0mglZRkmaWpw7BAFqNBIZEU8wCMVqu0IoQRxUuk2heDkP8QBQKd0FJALYVhMUNOdYWA5BcAfFJQgU+13JAGyYbPFYYGyN9PnwYLglyHnmXl83rMas8HTsIiT/aEQ+3zdYHrgQHK6sousxrOR+eUJaLDe

QY8AlsEQ8VGyeHPuskzg1sBIOdvBIyGqIT+z8bK2s1wgXxSngXnAKJm0yXOMT7L2snlIrd2IlY+BTlydUL4pl1Cbhe+yz7NljNngHijMvQehAxMcDHuzzrMl+NJp7imz4RXxSyjdYGvgp4m3siez7HMOIxCxzPBfQNHhWEzHs2xyreE8cjQE82CKYF9RThQnLGxyl7KCc9LVuZUiFSBI7EkGYgJzonN6wWJy+REa6N1ht6Ex6LHSs7NNnL5oO1AF

sGkiS8FooW1Ap5mQrR6yzJgKc1bNuQWw6MvBiKELIZ2Qy7O7UZ6zk8HeEy3ghiHmwdcIgeG40ppynrLWoVpzN+zwYGAgSqm3jB181sEpsjxy0nOXBEXh2yBsIe9RH0CMcmWIH7KCiV1JucA9SZ15liEWclbQTHJQKPDIPElIoATd5MTXpI6zv7NUINjwLIQv8LTgFfhkaERy5rLAc5PAuTO+kLagqMFx4RKBFpQjoTUhWrI+sxeFM5H8hTFhzCCH

zaGzGxhqsthT1pBCsXh8zQ2M4pAC0Yx9jFAoErXOwQJ0gXOqsjzA/WhiJTJzRyAnMRejbkngc6khEHJOIbvBIQEiqbegSIyhwOByf0AQcx6h8XNtkUeg/cD4ERu8ZnjJcm5BcXMpcsMhu8FjINN4DXTqwI3kPnKZc5dQWXNnbZYRDTA+Ya1g7SkZoRlz/pQLENMVAFGUfbF58MWeMw3AxPGBclFy78EtwLfh6dNwgqGzFXORcqhzN5De+VWyv9xS

gLaV6FAfMU4CMRGTiDRMkXNhs0FzZfAAoD4BmmE1IEPBbnNAc7qzxHKE8UWwksC+oHMkOyzkc46yznP1hTSIbMFAfNbgvXi2c0+zQKFMcsxRgLAxGaDw6sDcciZy7HKmcvCpI9xEldqgo6Gsc9xyE3OTotBiS5BQnOLAHmENZJ8ZmbL6cqpy2nJNUE6Ju/hEIUHxP7y+siGZBbMXwKOy81AfQPxgLfEtYWFEE7Nrc8HBk7OTUNi0e3FzYZOJ0CCl

sROy63PPAKqjMynMXXFzcPF0qdtyBbM7c+tyqqIJnCeQ0BlqzGtyZ3N+s2WzOtCfiZn4TbQokikMKnPycgxzS3IeuOPQB0FD5ezx/HN6cypyD3LXGXUQ5SHDAg+wUow0c5ZyI3Mz0JTFXGjSwUFtQ3M0clZynCHD+QF0NMDLEQ6yNrKmsv1zF9D7gXWgO1BooR4UOrLucl1zHnIENUsxZKhlEBOQvRkYc9LAmrI/0GIxOpCwlDuyLXK1cq1zN40W

ITxA50GroLFzvOjw8yhy4bLSMT9AHOBtQY/k35OzRHFy+XKlckohPGG+00uQLKBuSH1zTnMJsyYgt4wLYampXnS3s+NzqbNwya0xNXSMMhZRPJjhMxuztVErs+ilZFHwaSHgNRArScOzh3PXc9qxzsWn0Q1dWz0nIBGysbMHzBWxN7DFtJDZEYnF08/AzwDgdf71CkhDIZ5BhAiWoWgdGJyZETmzyTBGbT9DSyHYsI4x/gideJMolLHS9bmzClDf

cR6pRbG2wc2xD53esXzIWUk8gVf4NsBQgBchTmN5wEQJE9hRdcYR6TFD0EfAXcAXIWlcryDswYUpkvLSIAroFaCYWbklCtQdwDwgbuBckbdSnRHyCNLyivNpDDKQb0XK8mrhKvMi8z9Yhp0BXBchSvIlCD5gcxCcyXzyubNc8xVozfE68w0h/SCa8w5IwCB6HfY82yBd/Wi9hvMa8nryK0OJsyzzMY2s8lGwKaGLmFmgTMB7RDDJdPMxs5ak6MkL

sdbzeZxiYKGhV0mdstWyW7IowYN53MAnNakozvN9s/VzrbLvITvEj6z4mBuzy7Nk85uybbKsGPFgNMFElINjcnJZs3Wg87Jts17hZ0FSgH/QzngXs4Tz+7MwoetIkeHidXndj7OMc/ayn7NrseeQt6BmESDAcvGR8pZyz7NXQWkMPzBdwP/gQaFAof40TnOA8njzKyVHae9xabGWncnygPIJs0Che/DtIZKwBaDkvDhdcCGdcout0bMrJawgkNyL

oVagyXBJSLnzuHPpwXnyx/CTwEmZYJ3QTcxiuHPmsmdtVKGeSFFlLaAhIznzRHPF8qOhVKFHoVZiQdJCQPpJ5fPuciXzC7Eu4bgwILkfQdN0UbJg8nnytfMzJQHhOYUaEIWQ90MN8tGzbfMP8RYg9y3YJV9AQzxd8m3yIHJqoFNR7XIltARh4z198zXz/fIAFQPyiDJjEEPyj0i48ynzmfMOeZzACun1oXtNGJ3j8pnyvv1kwbPhbUGHnEKgIqhq

whuI8fNR8qklV+DkYB/xuuE9dGYyonJ3s6mpHngNBI7xEoCIMd7ygfLk8x54qphLaOEwxaItsh7z9bKe8vygT5xD4QmhPIjPPCzzNyCs80FTNqEKYV4hy/MswNeVv+ha8sWyYvJD/JgSMcA9YJyxmpI+SBOg1501IRzgCoGVJTGhu5mECF3Aqiyz0eFNVqFeIfdJ6aGlxcaI/wTl4+FJC7JiYevBL1VO0hsxOj1wuRMxS3Rz4Iuzn/OPcemh8Knk
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

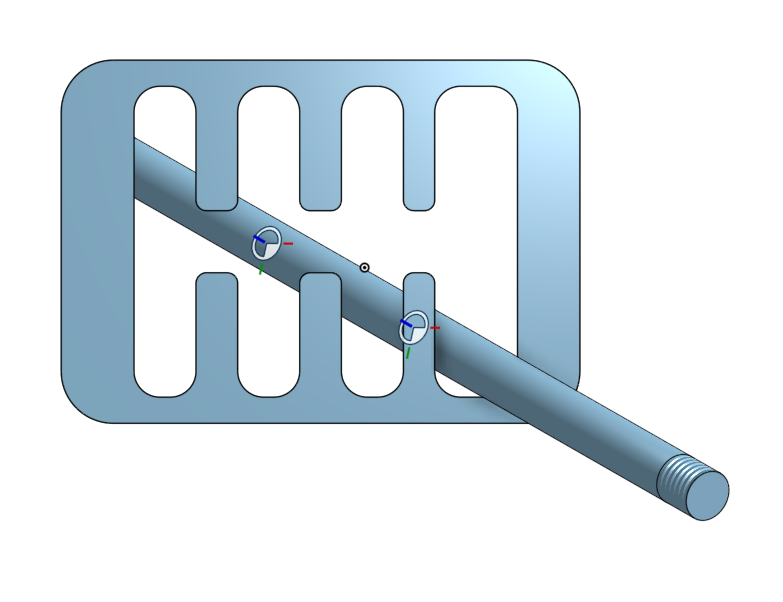
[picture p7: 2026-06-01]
basic design/images/Pasted Image 20260601222214_617.png

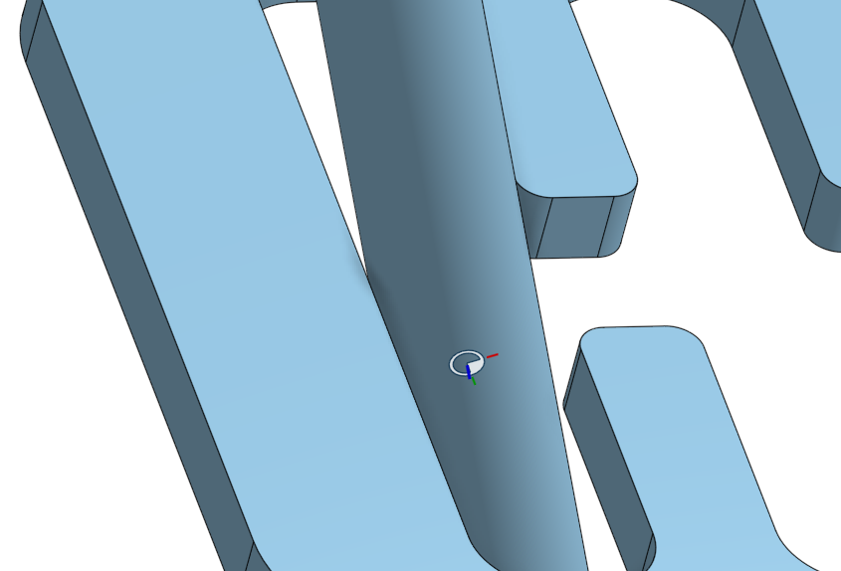
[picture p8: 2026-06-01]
basic design/images/Pasted Image 20260601214944_586.png

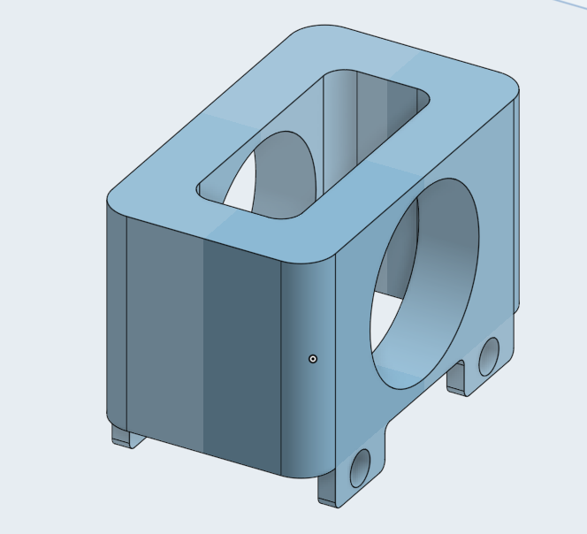
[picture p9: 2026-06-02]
basic design/images/Pasted Image 20260602135354_451.png

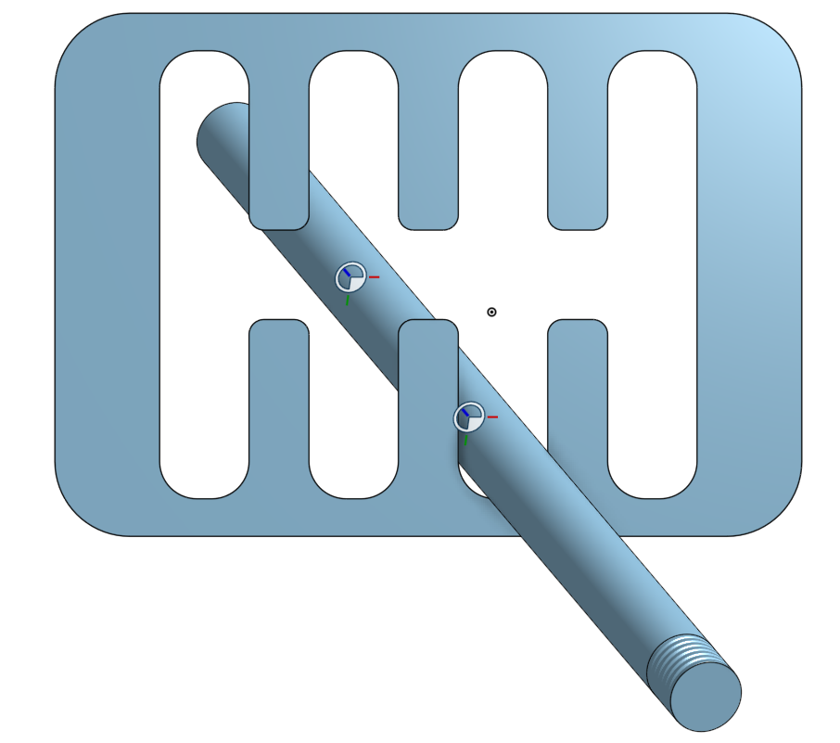
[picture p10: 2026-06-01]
basic design/images/Pasted Image 20260601220356_078.png

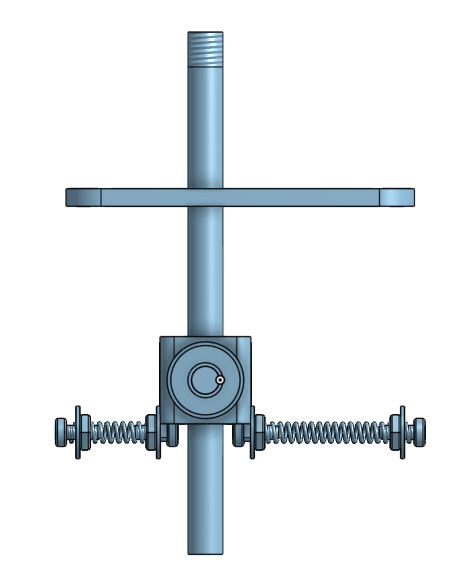
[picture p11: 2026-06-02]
basic design/images/Pasted Image 20260602143530_403.png

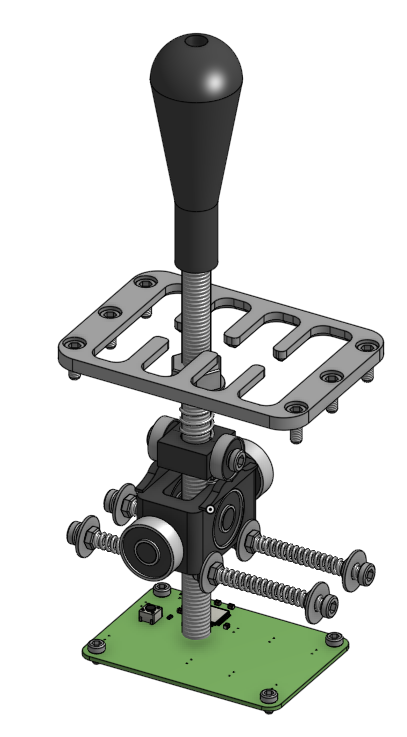
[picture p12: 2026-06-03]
basic design/images/shifter.png

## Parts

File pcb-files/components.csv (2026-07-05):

footprint no. | quantity | part no. | digikey link
C1 | 1 | 0805B105J250CC | link
C2 & C3 | 2 | 0805N220J500AD | link
C4 & C5 & C6 & C7 | 4 | 0805B104K500BD | link
J1 | 1 | 1050170001 | link
R1 | 1 | RC0805FR-0710KL | link
R2 & R3 | 2 | RC0805FR-0722RL | link
SW1 | 1 | 1825910-6 | link
U1 | 1 | ATMEGA32U4-AU | link
Y2 | 1 | ABM3-16.000MHZ-D2Y-T | link

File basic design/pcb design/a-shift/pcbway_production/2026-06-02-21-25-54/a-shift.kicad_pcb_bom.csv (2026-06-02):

Designator | Quantity | Value | Footprint | Package | MPN | DNP | Mount_Type | Description | KiLib_Generator
C1 | 1 | 1uF | C_0805_2012Metric |  |  |  | smt | Unpolarized capacitor, small symbol | SMD_2terminal_chip_molded
C2, C3 | 2 | 22pF | C_0805_2012Metric |  |  |  | smt | Unpolarized capacitor, small symbol | SMD_2terminal_chip_molded
C4, C5, C6, C7 | 4 | 0.1uF | C_0805_2012Metric |  |  |  | smt | Unpolarized capacitor, small symbol | SMD_2terminal_chip_molded
J1 | 1 | USB_B_Micro | USB_Micro-B_Molex-105017-0001 |  |  |  | smt | USB Micro Type B connector
J10 | 1 | GND5 | TestPoint_THTPad_1.0x1.0mm_Drill0.5mm |  |  |  | tht | Generic connector, single row, 01x01, script generated (kicad-library-utils/schlib/autogen/connector/)
J11 | 1 | PD4 | TestPoint_THTPad_1.0x1.0mm_Drill0.5mm |  |  |  | tht | Generic connector, single row, 01x01, script generated (kicad-library-utils/schlib/autogen/connector/)
J12 | 1 | GND6 | TestPoint_THTPad_1.0x1.0mm_Drill0.5mm |  |  |  | tht | Generic connector, single row, 01x01, script generated (kicad-library-utils/schlib/autogen/connector/)
J13 | 1 | PD5 | TestPoint_THTPad_1.0x1.0mm_Drill0.5mm |  |  |  | tht | Generic connector, single row, 01x01, script generated (kicad-library-utils/schlib/autogen/connector/)
J14 | 1 | GND7 | TestPoint_THTPad_1.0x1.0mm_Drill0.5mm |  |  |  | tht | Generic connector, single row, 01x01, script generated (kicad-library-utils/schlib/autogen/connector/)
J15 | 1 | PD6 | TestPoint_THTPad_1.0x1.0mm_Drill0.5mm |  |  |  | tht | Generic connector, single row, 01x01, script generated (kicad-library-utils/schlib/autogen/connector/)
J16 | 1 | GND8 | TestPoint_THTPad_1.0x1.0mm_Drill0.5mm |  |  |  | tht | Generic connector, single row, 01x01, script generated (kicad-library-utils/schlib/autogen/connector/)
J17 | 1 | PD7 | TestPoint_THTPad_1.0x1.0mm_Drill0.5mm |  |  |  | tht | Generic connector, single row, 01x01, script generated (kicad-library-utils/schlib/autogen/connector/)
J2 | 1 | GND1 | TestPoint_THTPad_1.0x1.0mm_Drill0.5mm |  |  |  | tht | Generic connector, single row, 01x01, script generated (kicad-library-utils/schlib/autogen/connector/)
J3 | 1 | PD0 | TestPoint_THTPad_1.0x1.0mm_Drill0.5mm |  |  |  | tht | Generic connector, single row, 01x01, script generated (kicad-library-utils/schlib/autogen/connector/)
J4 | 1 | GND2 | TestPoint_THTPad_1.0x1.0mm_Drill0.5mm |  |  |  | tht | Generic connector, single row, 01x01, script generated (kicad-library-utils/schlib/autogen/connector/)
J5 | 1 | PD1 | TestPoint_THTPad_1.0x1.0mm_Drill0.5mm |  |  |  | tht | Generic connector, single row, 01x01, script generated (kicad-library-utils/schlib/autogen/connector/)
J6 | 1 | GND3 | TestPoint_THTPad_1.0x1.0mm_Drill0.5mm |  |  |  | tht | Generic connector, single row, 01x01, script generated (kicad-library-utils/schlib/autogen/connector/)
J7 | 1 | PD2 | TestPoint_THTPad_1.0x1.0mm_Drill0.5mm |  |  |  | tht | Generic connector, single row, 01x01, script generated (kicad-library-utils/schlib/autogen/connector/)
J8 | 1 | GND4 | TestPoint_THTPad_1.0x1.0mm_Drill0.5mm |  |  |  | tht | Generic connector, single row, 01x01, script generated (kicad-library-utils/schlib/autogen/connector/)
J9 | 1 | PD3 | TestPoint_THTPad_1.0x1.0mm_Drill0.5mm |  |  |  | tht | Generic connector, single row, 01x01, script generated (kicad-library-utils/schlib/autogen/connector/)
R1 | 1 | 10k | R_0805_2012Metric |  |  |  | smt | Resistor, small symbol | SMD_2terminal_chip_molded
R2, R3 | 2 | 22 | R_0805_2012Metric |  |  |  | smt | Resistor, small symbol | SMD_2terminal_chip_molded
SW1 | 1 | SW_Push | SW_PUSH_6mm |  |  |  | tht | Push button switch, generic, two pins
U1 | 1 | ATmega32U4-A | TQFP-44_10x10mm_P0.8mm |  |  |  | smt | 16MHz, 32kB Flash, 2.5kB SRAM, 1kB EEPROM, USB 2.0, TQFP-44 | package/gullwing
Y2 | 1 | Crystal_GND3_Small | Crystal_SMD_5032-2Pin_5.0x3.2mm |  |  |  | smt | Three pin crystal, GND on pin 3, small symbol | crystal_resonator_oscillator

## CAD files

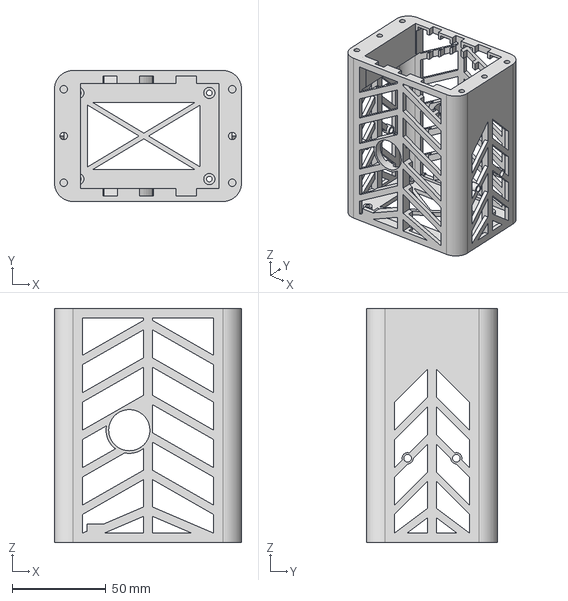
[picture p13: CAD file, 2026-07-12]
3d-prints/main-chassis (1).step
100.0 x 70.0 x 125.0 mm

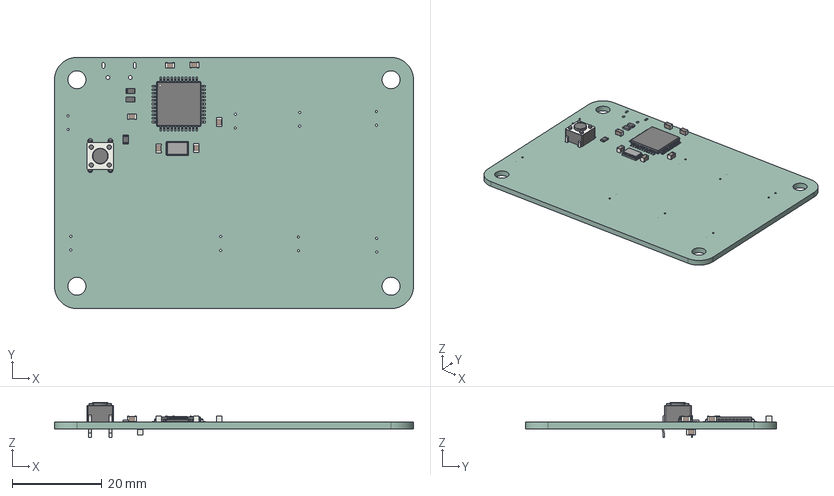
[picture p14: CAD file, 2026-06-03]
basic design/pcb design/a-shift/a-shift-board.step
80.0 x 56.0 x 7.80 mm
C_0805_2012Metric x 7
Crystal_SMD_5032-2Pin_5.0x3.2mm
R_0805_2012Metric x 3
SW_PUSH_6mm
TQFP-44_10x10mm_P0.8mm
a-shift_PCB

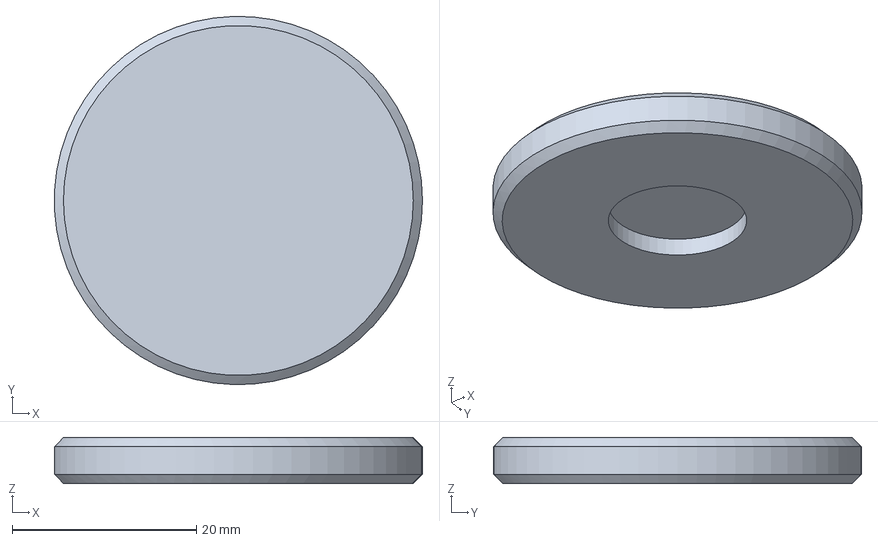
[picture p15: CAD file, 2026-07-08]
3d-prints/clamp head.step
40.0 x 40.0 x 5.00 mm

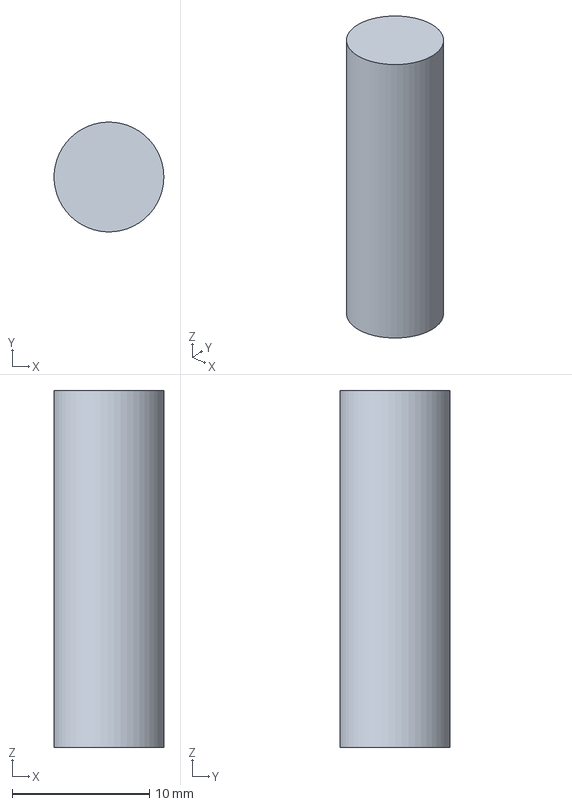
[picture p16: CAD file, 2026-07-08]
3d-prints/y-axis bearing peg.step
7.99 x 8.00 x 26.0 mm

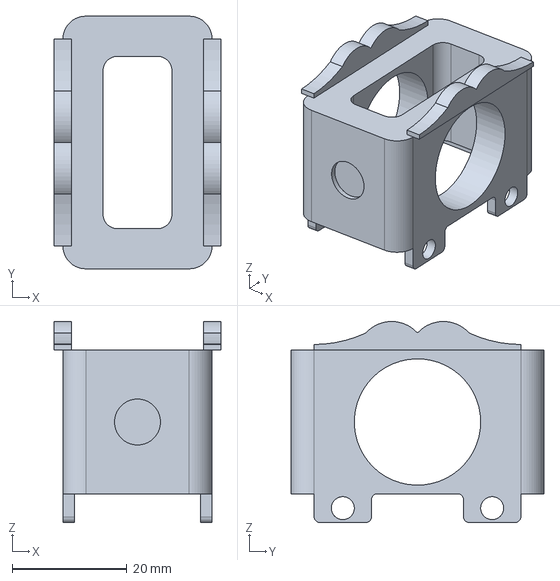
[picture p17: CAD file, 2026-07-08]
3d-prints/y-axis chamber.step
29.0 x 44.0 x 35.0 mm

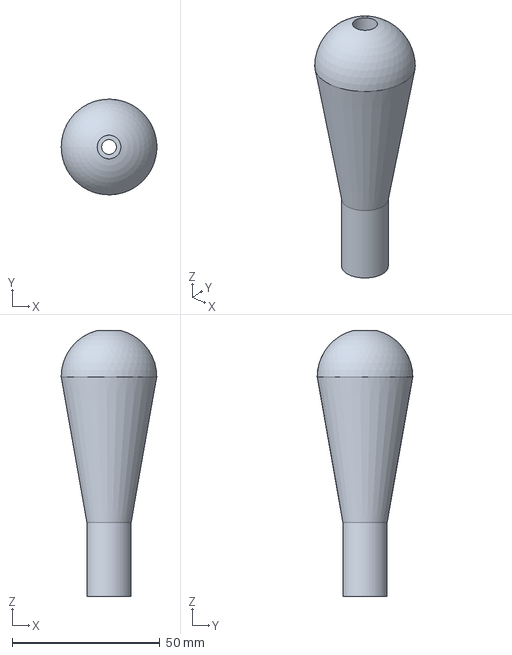
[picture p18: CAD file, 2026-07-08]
3d-prints/shift knob.step
32.3 x 32.3 x 89.9 mm

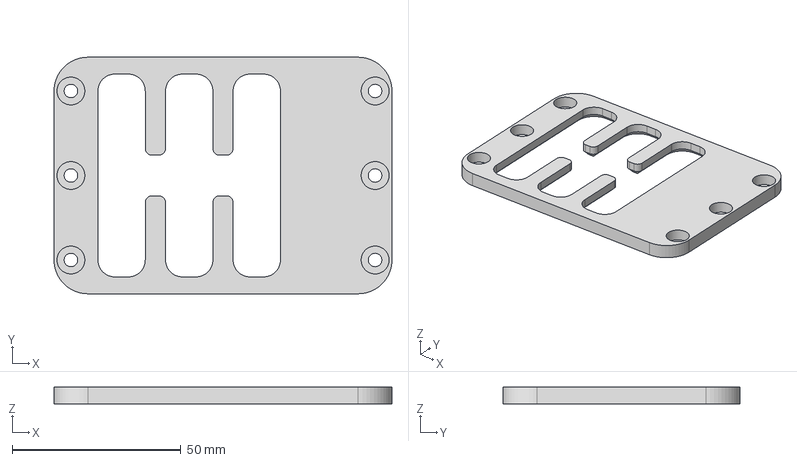
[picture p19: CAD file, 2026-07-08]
3d-prints/5+r-shift-gate.step
100.0 x 70.0 x 5.00 mm

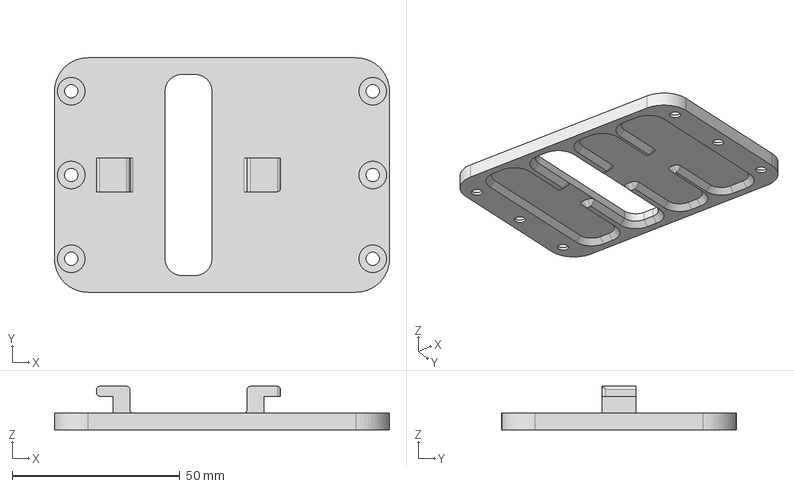
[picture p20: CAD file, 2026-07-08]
3d-prints/seq-gate.step
100.0 x 70.0 x 13.0 mm

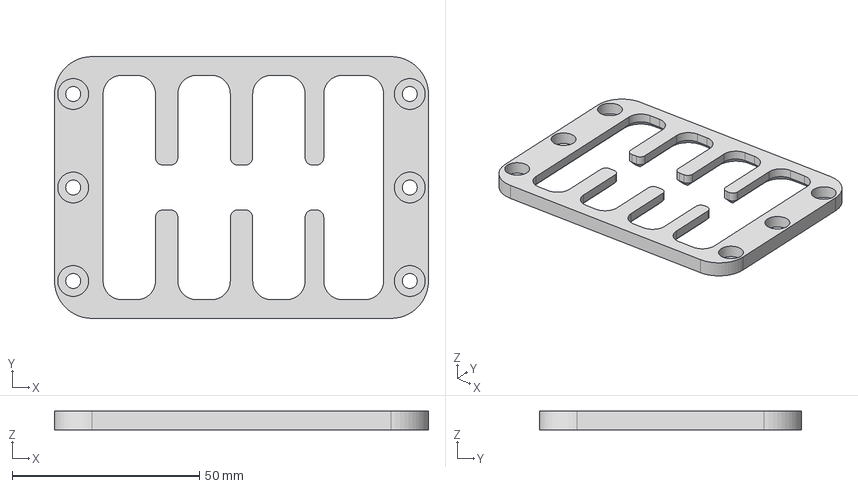
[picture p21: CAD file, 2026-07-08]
3d-prints/7+r-shift-gate.step
100.0 x 70.0 x 5.00 mm

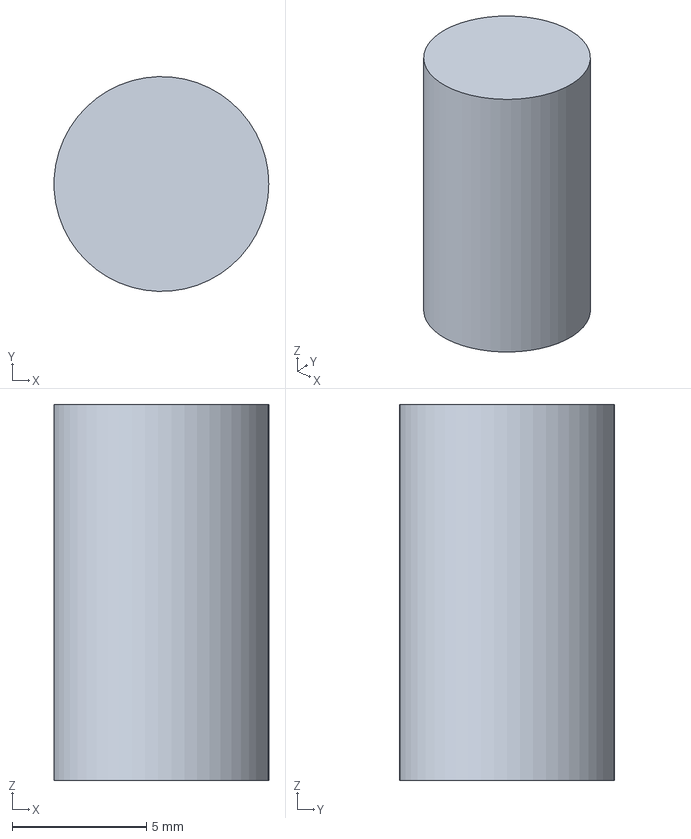
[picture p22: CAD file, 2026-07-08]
3d-prints/x-axis bearing peg.step
7.99 x 8.00 x 14.0 mm

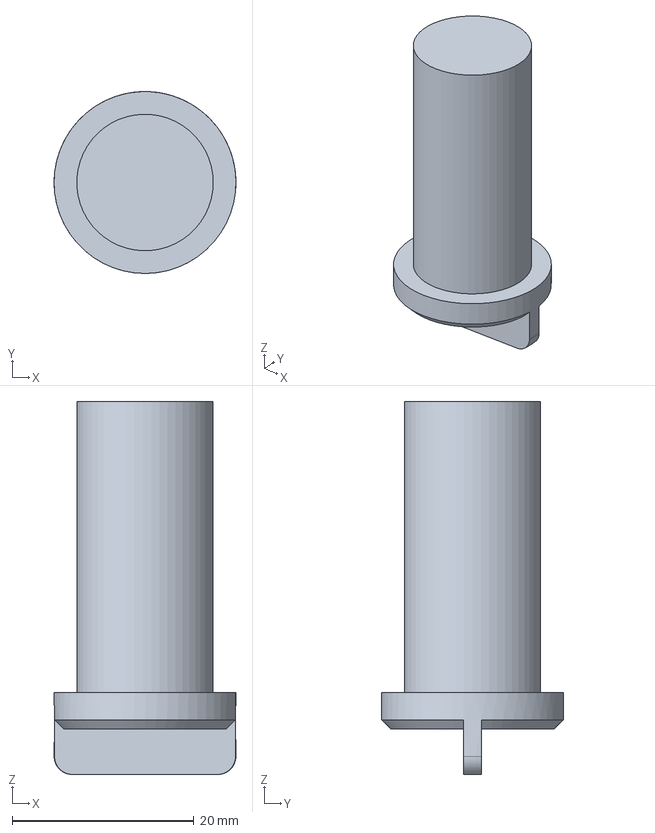
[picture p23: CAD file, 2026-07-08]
3d-prints/clamp body.step
20.0 x 20.0 x 41.0 mm

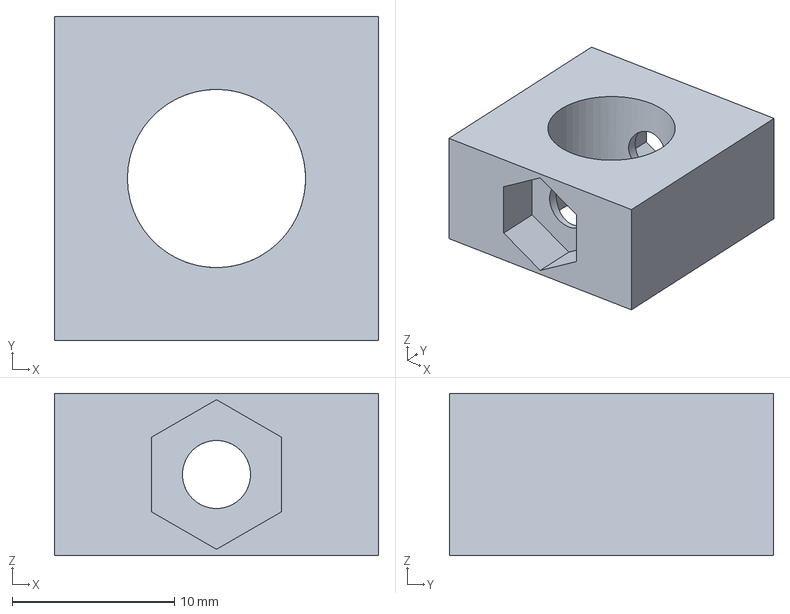
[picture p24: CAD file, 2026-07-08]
3d-prints/y-axis bearing holder.step
20.0 x 20.0 x 10.0 mm

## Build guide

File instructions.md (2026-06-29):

<h1>instructions!</h1>
<h2>if you made it this far - congrats! it's time to build the shifter!</h2>
<hr>
<h3>what ya need!</h3>
<h4>3d printed parts</h4>
  <li>1 x <b>3d printed y-axis chamber</b></li>
  <li>2 x <b>3d printed x-axis bearing pegs</b></li>
  <li>1 x <b>3d printed y-axis bearing peg</b></li>
  <li>1 x <b>3d printed main chassis</b></li>
  <li>1 x <b>3d printed shift gate</b></li>
  <li>1 x <b>3d printed y-axis bearing holder</b></li>
  <li>1 x <b>3d printed shift knob</b></li>
  <li>1 x <b>3d printed clamp head</b></li>
  <li>1 x <b>3d printed clamp body</b></li>
<h4>bearings</h4>
  <li>4 x <b>608 series bearings</b></li>
  <li>2 x <b>625 series bearings</b></li>
<h4>mounting hardware</h4>
  <li>4 x <b>m3x5mm bolts</b></li>
  <li>8 x <b>m4 nuts</b></li>
  <li>8 x <b>m6 washers</b></li>
  <li>15 x <b>m4x10mm bolts</b></li>
  <li>2 x <b>m5 nuts</b></li>
  <li>2 x <b>m5x10mm bolts</b></li>
  <li>1 x <b>m10 washer</b></li>
  <li>1 x <b>m10 nut</b></li>
<h4>springs</h4>
  <li>2 x <b>25mm long, 5mm diameter springs</b></li>
  <li>2 x <b>45mm long, 5mm diameter springs</b></li>
  <li>1 x <b>20mm long, 11mm diameter spring</b></li>
<h4>misc.</h4>
  <li>1 x <b>200mm m10 threaded rod</b></li>
  <li>8 x <b>kw13-2 limit switches</b></li>
  <li>1 x <b>a-shift pcb</b></li>
</ul>

<p>(p.s - if you want to buy the bare pcb and assemble it yourself, <a href="https://docs.google.com/spreadsheets/d/1MjrU7IrbQ_ZQorYGkfbvgLpo6hidaAycoKFRKqDxL6c/edit?usp=sharing">here's a spreadsheet</a> with the components that i used and recommend for the pcb! :D)</p>
<hr>
<h3>how to build!</h3>
<ol>
  <li>assemble the <b><b>a-shift pcb</b></b> (if neccessary)</li>
  <li>flash the <b>a-shift pcb</b> firmware</li>
  <li>bolt the <b>a-shift pcb</b> to the <b>3d printed main chassis</b> with <b>m3x5mm bolts</b></li>
  <li>solder connections from the <b>kw13-2 limit switches</b> to the pcb pads</li>
  <li>test all of the switches on your computer</li>
  <li>superglue all switches to their respective slots</li>
  <li>drill an 8mm hole 50mm up on <b>200mm m10 threaded rod</b></li>
  <li>superglue <b>3d printed x-axis bearing pegs</b> to <b>3d printed y-axis chamber</b></li>
  <li>assemble <b>608 series bearings</b> in <b>3d printed y-axis chamber</b></li>
  <li>thread the <b>3d printed y-axis bearing peg</b> through both bearings and <b>200mm m10 threaded rod</b> hole</li>
  <li>put <b>m4 nuts</b> and <b>m6 washers</b> over each end of the <b>25mm long and 45mm long, 5mm diameter springs</b></li>
  <li>thread <b>m4x10mm bolts</b> in the back of the <b>3d printed y-axis chamber</b> holes and tighten <b>m4 nuts</b> until <b>all 4 springs</b> are secured to <b>3d printed y-axis chamber</b></li>
  <li>put the <b>3d printed y-axis chamber</b> pegs through the <b>3d printed main chassis</b> bearing holes without any bearings</li>
  <li>put <b>608 series bearings</b> on each side of the pegs and friction fit one by one into <b>3d printed main chassis</b> bearing holes</li>
  <li>thread <b>m4x10mm bolts</b> in the holes on the sides of the <b>3d printed main chassis</b> and tighten <b>m4 nuts</b> until <b>all 4 springs</b> are attached to the <b>3d printed main chassis</b></li>
  <li>superglue <b>m5 nuts</b> into both slots of the <b>3d printed y-axis bearing holder</b></li>
  <li>bolt <b>625 series bearings</b> through the <b>m5 nuts</b> on the <b>3d printed y-axis bearing holder</b> with <b>m5x10mm bolts</b></li>
  <li>slide <b>3d printed y-axis bearing holder</b> onto the <b>200mm m10 threaded rod</b> with bearings on top of the ramps of <b>3d printed y-axis chamber</b></li>
  <li>slide a <b>20mm long, 11mm diameter spring</b> over the <b>200mm m10 threaded rod</b> above the <b>3d printed y-axis bearing holder</b></li>
  <li>use a <b>m10 washer</b> and a <b>m10 nut</b> to secure the <b>20mm long, 11mm diameter spring</b> and <b>3d printed y-axis bearing holder</b> to the rod</li>
  <li>bolt the <b>3d printed shift gate</b> to the <b>3d printed main chassis</b> with <b>m4x10mm bolts</b></li>
  <li>test the shifter to see if it goes into each gear</li>
  <li>thread the <b>3d printed shift knob</b> over the <b>200mm m10 threaded rod</b></li>
  <li>thread the <b>3d printed clamp body</b> through the bottom a little bit</li>
  <li>superglue the <b>3d printed clamp head</b> to the <b>3d printed clamp body</b></li>
</ol>

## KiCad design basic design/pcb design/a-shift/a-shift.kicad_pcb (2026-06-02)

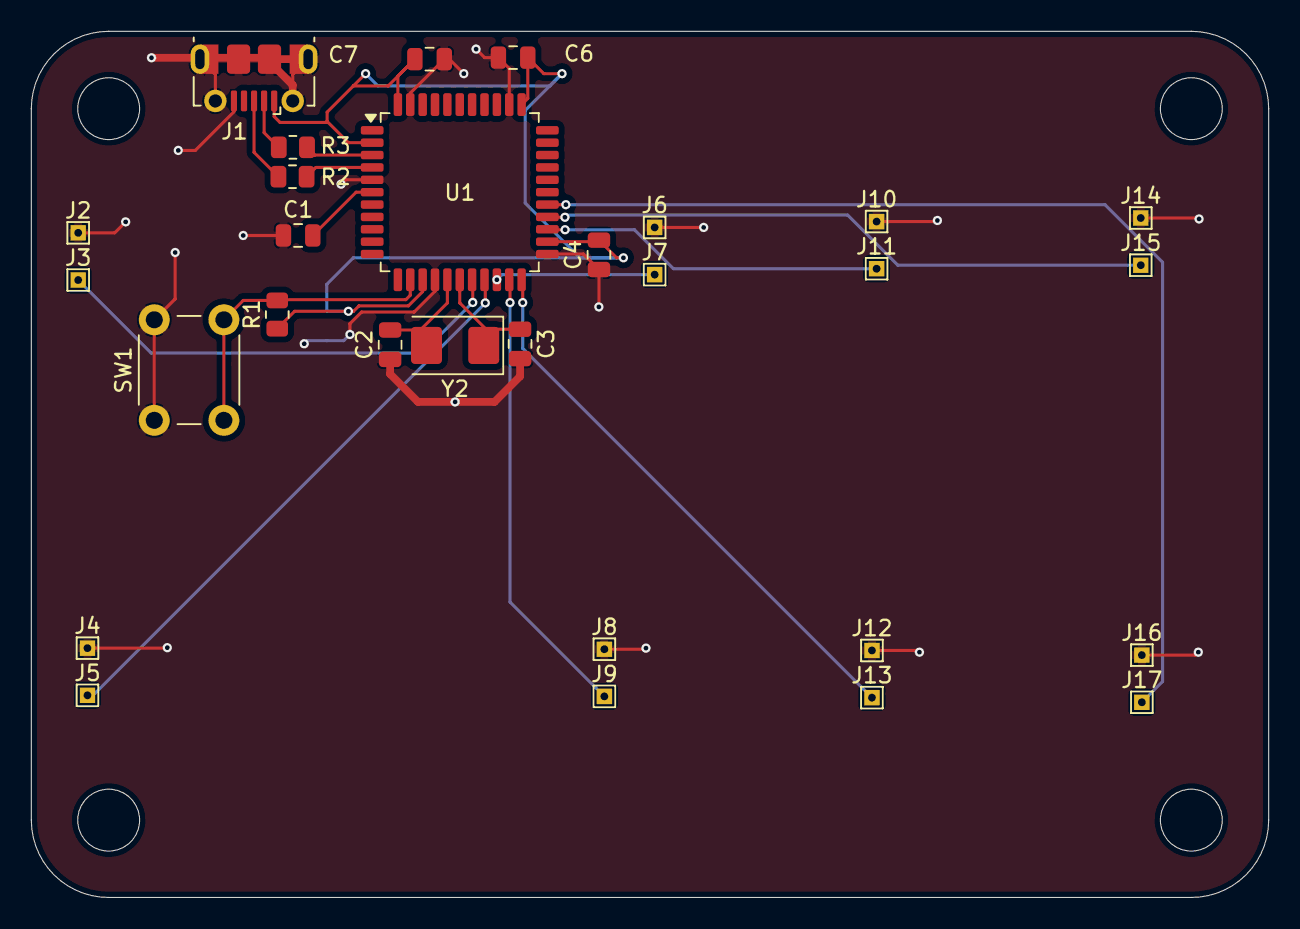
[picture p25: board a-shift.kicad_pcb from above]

Board: 2 copper layers, 80.0 x 56.0 mm, 30 parts (1 on the bottom side), 18 nets.

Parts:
C1: 1uF; C_0805_2012Metric
C2, C3: 22pF; C_0805_2012Metric
C4, C5, C6, C7: 0.1uF; C_0805_2012Metric
J1: USB_B_Micro; USB_Micro-B_Molex-105017-0001
J2: GND1; TestPoint_THTPad_1.0x1.0mm_Drill0.5mm
J3: PD0; TestPoint_THTPad_1.0x1.0mm_Drill0.5mm
J4: GND2; TestPoint_THTPad_1.0x1.0mm_Drill0.5mm
J5: PD1; TestPoint_THTPad_1.0x1.0mm_Drill0.5mm
J6: GND3; TestPoint_THTPad_1.0x1.0mm_Drill0.5mm
J7: PD2; TestPoint_THTPad_1.0x1.0mm_Drill0.5mm
J8: GND4; TestPoint_THTPad_1.0x1.0mm_Drill0.5mm
J9: PD3; TestPoint_THTPad_1.0x1.0mm_Drill0.5mm
J10: GND5; TestPoint_THTPad_1.0x1.0mm_Drill0.5mm
J11: PD4; TestPoint_THTPad_1.0x1.0mm_Drill0.5mm
J12: GND6; TestPoint_THTPad_1.0x1.0mm_Drill0.5mm
J13: PD5; TestPoint_THTPad_1.0x1.0mm_Drill0.5mm
J14: GND7; TestPoint_THTPad_1.0x1.0mm_Drill0.5mm
J15: PD6; TestPoint_THTPad_1.0x1.0mm_Drill0.5mm
J16: GND8; TestPoint_THTPad_1.0x1.0mm_Drill0.5mm
J17: PD7; TestPoint_THTPad_1.0x1.0mm_Drill0.5mm
R1: 10k; R_0805_2012Metric
R2, R3: 22; R_0805_2012Metric
SW1: SW_Push; SW_PUSH_6mm
U1: ATmega32U4-A; TQFP-44_10x10mm_P0.8mm
Y2: Crystal_GND3_Small; Crystal_SMD_5032-2Pin_5.0x3.2mm

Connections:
+5V: C4.2, C5.2, C6.2, C7.2, J1.1 (VBUS), R1.1, U1.2 (UVCC), U1.14 (VCC), U1.24 (AVCC), U1.34 (VCC), U1.44 (AVCC)
/PD0: J3.1 (Pin_1_1), U1.18 (PD0)
/PD1: J5.1 (Pin_1_1), U1.19 (PD1)
/PD2: J7.1 (Pin_1_1), U1.20 (PD2)
/PD3: J9.1 (Pin_1_1), U1.21 (PD3)
/PD4: J11.1 (Pin_1_1), U1.25 (PD4)
/PD5: J13.1 (Pin_1_1), U1.22 (PD5)
/PD6: J15.1 (Pin_1_1), U1.26 (PD6)
/PD7: J17.1 (Pin_1_1), U1.27 (PD7)
/d+: J1.3 (D+), R2.1
/d-: J1.2 (D-), R3.1
GND: C1.1, C2.1, C3.2, C4.1, C5.1, C6.1, C7.1, J1.5 (GND), J1.SH (Shield), J2.1 (Pin_1_1), J4.1 (Pin_1_1), J6.1 (Pin_1_1), J8.1 (Pin_1_1), J10.1 (Pin_1_1), J12.1 (Pin_1_1), J14.1 (Pin_1_1), J16.1 (Pin_1_1), SW1.1, U1.5 (UGND), U1.15 (GND), U1.23 (GND), U1.35 (GND), U1.43 (GND)
unnamed: R2.2, U1.4 (D+)
unnamed: R3.2, U1.3 (D-)
unnamed: C1.2, U1.6 (UCAP)
unnamed: C3.1, U1.17 (XTAL1), Y2.1
unnamed: C2.2, U1.16 (XTAL2), Y2.2
unnamed: R1.2, SW1.2, U1.13 (~RESET)

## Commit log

2026-06-01 finished the first revision of the shift plate and lever design
2026-06-02 design and route a main pcb for the shifter
    [a-shift.kicad_pcb, a-shift.kicad_sch]
2026-06-02 create production files for the 1st pcb
    [a-shift.kicad_pcb, a-shift.kicad_pcb_bom.csv, a-shift.kicad_pcb_positions.csv]
2026-06-03 add an image of the mechanism and circuit board to the repo
    [a-shift-board.step]
2026-06-03 update the readme with a frame of what to put where
2026-06-18 add pcb components link to instructions.md
2026-07-05 create pcb-files
2026-07-05 added pcb gerber file
2026-07-05 add main bom
    [BOM.csv]
2026-07-05 add components to pcb-files
    [components - Sheet1.csv]
2026-07-08 add pcb picture files for readme.md
2026-07-08 update readme.md with pcb and schematic photos
2026-07-08 update readme.md with bom
2026-07-08 create 3d-prints folder
2026-07-08 add all 3d printing files
    [5+r-shift-gate.step, 7+r-shift-gate.step, clamp body.step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]
2026-07-12 add improved chassis
    [main-chassis (1).step]
